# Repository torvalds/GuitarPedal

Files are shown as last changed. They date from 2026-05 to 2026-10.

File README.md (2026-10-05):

## Resurrected random guitar pedal project

This is a resurrected version of my old guitar pedal project: a digital
guitar pedal built around an RP2354A and a TI audio codec, with all the
effects done in software on a core of its own.

It went through a phase with a little OLED screen and a couple of rotary
encoders on it, and that's gone now.  Editing seventeen effects through a
128x128 screen and two knobs was never going to be pleasant, and I'm not
exactly known for my mad UI designing skillz, so the pedal itself is down
to one knob and one stomp switch and the deep editing happens somewhere
that already has a screen: there's a web app that talks to it over USB
MIDI from a browser.

So what's in here:

 - `Hardware` has the kicad files.
 - `Effects` has the seventeen effects, one file each.  They are up here
   rather than inside the firmware because three different things are
   built from them: the firmware, the test bench, and the web app's
   controls.
 - `Audio` has the DSP the effects are built out of - biquads, envelope
   followers, LFOs - and the audio loop itself.  The bench compiles the
   same files, so what gets measured is the pedal's own arithmetic.
 - `Firmware` is the rest of what runs on the pedal: USB, MIDI, scenes,
   the board pin maps.
 - `WebMIDI` is the web app that edits it.
 - `scripts` is what the build runs - the effect generator, the math
   tables, and the checks that refuse a firmware image doing something
   the audio core shouldn't.
 - `Validation` is the test suite.  Some of it runs on your machine and
   some of it wants a pedal plugged in.
 - `Documentation` remains a very optimistic name for a directory.

## Firmware

I've only ever built the firmware on Linux, but it *should* be perfectly
possible to build on MacOS or Windows too if you just figure out the
platform requirements. The project depends on the `pico-sdk` and
`tinyusb` libraries and on `picotool`, and has submodules for all three, so
they get built automatically, but the build tools your platform has to provide.

Regardless of platform, you'll need the basics:
 - git
 - make
 - python3
 - cmake
 - a C and C++ compiler for the machine you build on, because picotool
   and the SDK's PIO assembler are built from source too
 - pkg-config and the libusb-1.0 development files, for picotool
   (`libusb1-devel` on Fedora, `libusb-1.0-0-dev` on Debian)

and a 32-bit arm cross-build environment.  On Linux, that would be
something like
 - arm-none-eabi-binutils-cs
 - arm-none-eabi-gcc-cs
 - arm-none-eabi-gcc-cs-c++ (the SDK sets up C++ as well as C)
 - arm-none-eabi-newlib

On Fedora that whole list is

    dnf install git make python3 cmake gcc-c++ pkgconf-pkg-config \
        libusb1-devel arm-none-eabi-gcc-cs arm-none-eabi-gcc-cs-c++ \
        arm-none-eabi-newlib

The `ble` board also carries the nRF54 radio's firmware, which is a
Zephyr build of its own.  ``make -C nRF54 fetch`` sets that up once: a
python venv with west in it, the Nordic SDK, and Zephyr's ARM toolchain
in `~/zephyr-sdk-*`, about 7.5GB between them.  It also needs ninja
(`ninja-build` on Fedora).

There's more than one board this can be built for, and the build won't
guess.  You say which one this tree is about once, in
`board.local`, and it stays said - it's a file rather than a
cmake cache variable specifically so that blowing away `build/` doesn't
silently change your mind for you.  So:
```
	git clone https://github.com/torvalds/GuitarPedal.git
	cd GuitarPedal
	echo unified > board.local
	make prep
	make
```
`unified` is the current one-board pedal.  The other is `split`, which is
the older modular pair of boards.  If you forget this step the configure
will stop and tell you, which is the intended behaviour - a wrong board
should be an error you fix once, not a working build for hardware you
don't have.

That gets you `build/pedal-unified.uf2` (and `.elf`, and `.bin`).  Every
artifact is named for the board it's for, so there is deliberately no
`pedal.uf2` to grab by mistake.  You can build the other board without
changing what the tree is about - ``make split`` - or both with ``make
all-boards``.

To get the `.uf2` onto the pedal you need it in BOOTSEL mode, and there
are two ways.  If it's running and plugged in, send it MIDI CC 20 with
value 126 and it will reboot into BOOTSEL on its own:
```
	amidi -l                          # find which card the pedal is
	amidi -p hw:5,0 -S "B0 14 7E"     # ...and that 5 is mine, not yours
```
Otherwise, hold the knob in while you plug it in.  The rotary encoder's
switch doubles as BOOTSEL on this board - through a Schottky, so that
QSPI traffic can't fake pulling it low - and that's the route that still
works on a pedal too broken to enumerate.  The older boards had a proper
BOOTSEL button, but it was on the little MCU daughtercard, which is fine
on a bench and useless the moment the thing is screwed into a box.

Either way a USB mass storage device shows up and you copy the file to
it.

The build makes its own picotool, with USB support, so you can also skip
all that and just do ``make flash``, which builds and flashes the board in
`board.local`.
``make flash-split`` does the other one.

### Tools outside the tree

Two tools stay outside the tree, and each has a make target that
sets it up once per machine.  Both say what they are missing, and
running either again is safe.

``make probe-rs`` builds probe-rs, which programs and debugs the nRF54
radio through the pedal, from `~/src/probe-rs` into `~/bin/probe-rs`.
It needs cargo and the libudev development files (`systemd-devel` on
Fedora).

``make build123d`` makes a python venv in `~/.build123d` for the
3D-printed case in `Hardware/Models`, and two commands in `~/bin` that
use it: ``build123d Compact.py`` runs the model, and ``ocp-viewer`` is
the viewer it draws in, at http://localhost:3939.

### Talking to the pedal without root

picotool and probe-rs open the pedal's USB device directly, and without
a udev rule only root can.  This is `/etc/udev/rules.d/99-pedal.rules`:

    ATTR{idVendor}=="2e8a", MODE="0660", GROUP="dialout"
    ATTR{idVendor}=="ffff", ATTR{idProduct}=="0003", MODE="0660", GROUP="dialout"

The first line covers anything with Raspberry Pi's vendor id, which is
how a board in BOOTSEL shows up; the second is the running pedal, whose
CMSIS-DAP interface is what probe-rs uses for the radio.  You have to be
in the `dialout` group, and ``udevadm control --reload`` as root plus a
replug picks the rule up.  USB audio and MIDI need no rule.

The pedal's debug console is `/dev/ttyACM0`, which needs a kernel with
`CONFIG_USB_ACM`.  Every distribution kernel has it; a kernel you
configured yourself may not.

### Testing

`Validation` has the test suite, and it's split by what it needs.

``make check`` needs gcc and numpy (`python3-numpy`), plus node if
you want the web app's tests too; without node those are skipped.  The
bench scripts that talk to a pedal want more: alsa-utils, ffmpeg, scipy
and matplotlib, ngspice for the circuit comparisons, and dbus-python and
PyGObject for Bluetooth MIDI.  On Fedora,

    dnf install python3-numpy nodejs alsa-utils ffmpeg-free psmisc \
        python3-scipy python3-matplotlib ngspice python3-dbus python3-gobject

``make check`` runs the part that needs no hardware at all: the MIDI
packetiser, whether the web app still loads and still draws the right
conclusions, and a sweep that asks every biquad in the pedal where it
actually landed.  ``make check-biquad`` is that last one on its own, and
``make check-effects`` puts signals through the effects themselves.

That last one works because of `Validation/bench`, which builds the
pedal's actual audio core - the same `single_sample()`, the same effect
headers, the same compiler flags - as a program on your machine that
takes float samples on stdin and hands them back on stdout.  It is not a
model of the signal path.  It's the signal path, with the two register
blocks the audio core touches replaced by ordinary memory.

``make check-analysis`` is the other host-only one, and it is what keeps
the per-effect pages under `Documentation/effects` honest: every curve on
those pages is a measurement, and this re-measures and says when one has
stopped being true.  It is separate from ``check`` because it re-runs
every sweep on every page, which is slow.

Then there are the ones that want hardware: ``make check-hw`` with a
signal generator, ``make check-analog`` with a patch cable from the
pedal's output back to its own input, ``make check-bench`` to ask whether
a real board agrees with the host build, ``make check-hwtone`` to sweep
the tone stack the codec runs in its own biquads, and ``make check-loop``
if you have two pedals to patch into each other.

## Hardware

The kicad design files (and some supporting infrastructure, like the 3D
printed insert and the enclosure drill rules) are in the ``Hardware``
subdirectory.

These days it's just the one board.  `Hardware/usb-stomp` has the RP2354A
and the TI TAC5242 codec sitting directly on it, and that's the whole
pedal: no cable, no daughtercards, no connectors in between.

What's on it:

 - a 1/4" input jack and a 1/4" output jack
 - a third 1/4" jack for an expression pedal or a remote stomp switch
 - MIDI in and out, on 3.5mm "Type A" TRS jacks (out through a 5V
   buffer, in through an optocoupler, like MIDI has always wanted)
 - USB-C, and the usual 9V guitar pedal power jack
 - one rotary encoder with a switch under it, and one stomp switch
 - three addressable WS2812B LEDs

The MIDI jacks and the expression jack are the genuinely new things.  The
older boards had nowhere to put them - the expression jack in particular
wants two ADC pins, and those are exactly the pins the old MCU board was
spending on hardware MIDI, so it could not have existed there at all.

Fair warning on that expression jack, though: the hardware is done and
the firmware can read it, but only when the host asks it to over SysEx.
Right now it's a probe for figuring out what people actually plug in
there - expression pedals don't even agree on which contact is the wiper
- and nothing is wired up to *do* anything with the result yet.

### How it used to be

It used to be modular, and those board files are all still here.  There
were two little daughtercards for the "core" hardware - the RP2354
microcontroller (`Hardware/rp2354`) and the TI TAC5112 codec
(`Hardware/codec`) - plus a board for the audio and 9V DC power jacks
(`Hardware/audio-jacks`), and a main board (`Hardware/pedal-board`) for
the pedal IO: i2c connector for the screen, USB-C programming port,
rotary encoders, pin header for stomp switches.  The two halves were
joined by a 12P 0.5mm FFC cable carrying power and data lines (i2c for
control, i2s for audio).

That was mostly so I could try out different form factors.  It let me lay
the two halves out independently, and it was flexible enough to cram a
125B enclosure full of jacks, rotaries and the screen all in one top
area.  There was also a worry about noise isolation, which in the end
never had to be tested.

I used the nice HiRose BM28 series connectors on the modular boards.
They are absolutely tiny, which makes for a great board footprint but
admittedly also makes for a slightly more complicated board due to the
tiny 0.35mm pitch.  I'm not a fan of the traditional pin headers simply
because they make it so hard to do compact form factors.

Those boards are finished and they still work - the firmware builds for
them, and they're still useful for testing.  But what this section used
to say was that if you know what you want, you should just put the codec
directly on the audio jack board and the rp2354 on the IO board.  Which,
yes.  That's the board above.

### Images

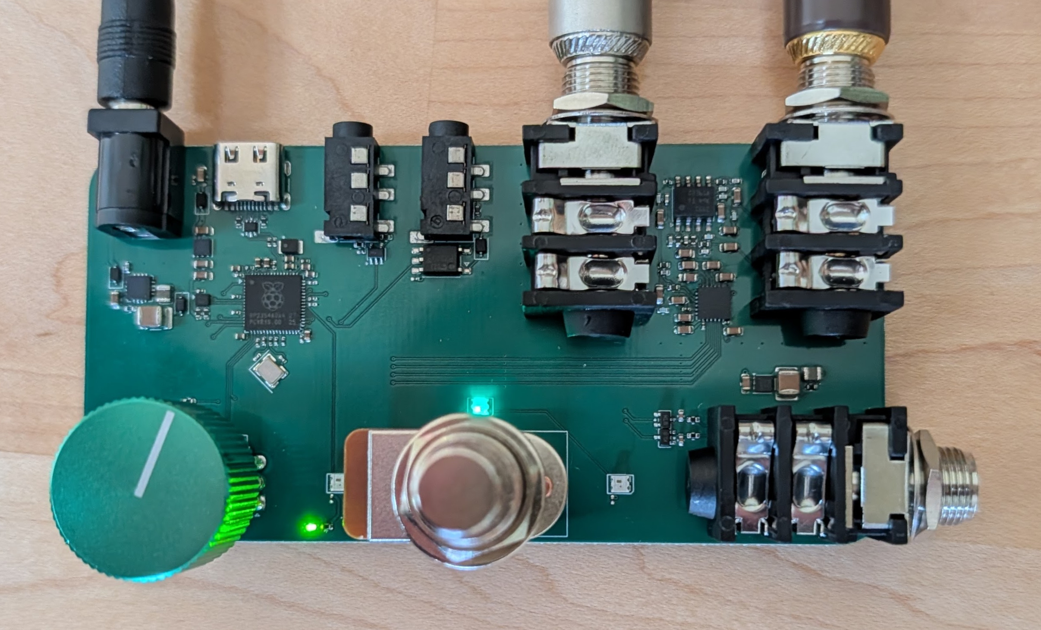
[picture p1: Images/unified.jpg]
The unified board


The bare `usb-stomp` board, powered up.

## Basic UI

There's no screen.  The pedal has one knob, one footswitch and three
LEDs, and everything else happens in a browser.

### On the pedal

Out of the box the footswitch is bypass - tap for in-circuit or not, hold
it for the tuner - and the knob is the master volume, with either kind of
press on it putting the volume back where it started.  That last one
sounds trivial and isn't: it's the way back when you can't see anything.

But none of that is compiled in.  There are five gestures - turn the
knob, tap it, hold it, tap the switch, hold the switch - and what each
one means is a table the pedal looks up and the app writes.  You can
point the knob at any parameter of any effect, or make a single press
take one effect's mix up while it takes another's down.  A pedal with no
screen can't tell you what its knob is for, so that has to be settable
from something that can.

The three LEDs, left to right: something is wrong (red for clipping,
amber for dropped samples), in circuit or bypassed, and the chain is
busy - where "busy" means whatever the effect thinks it means, so the
gate lights it while it's gating and the compressor while it's
compressing.

### In the browser

`WebMIDI` is a static web page that talks to the pedal over USB
MIDI.  There's nothing to install and it runs off a phone.

It also talks to the pedal over Bluetooth MIDI.  On Linux, Chrome only
offers Bluetooth to a page with
`chrome://flags/#enable-experimental-web-platform-features` turned on;
USB needs nothing.

It doesn't know what the effects are.  It asks.  The pedal describes
every effect it has - every pot, the ranges, the units, the hover text -
and the app builds itself out of that, so it can't drift out of step with
the firmware, and adding an effect to the pedal makes it show up in the
app without touching the app.

What you actually do there is *route*.  There are seventeen effects and
none of them are in your signal path until you say so: routing picks
which ones run, and in what order, and the order is yours, because a
boost in front of a delay is a different pedal from a delay in front of a
boost.  Whatever you don't route costs nothing.

Pots are mostly just numbers, except where they aren't - the tone stacks,
the parametric EQ and the cab sim draw their actual frequency response,
so you can see the curve instead of inferring it from three knob
positions.

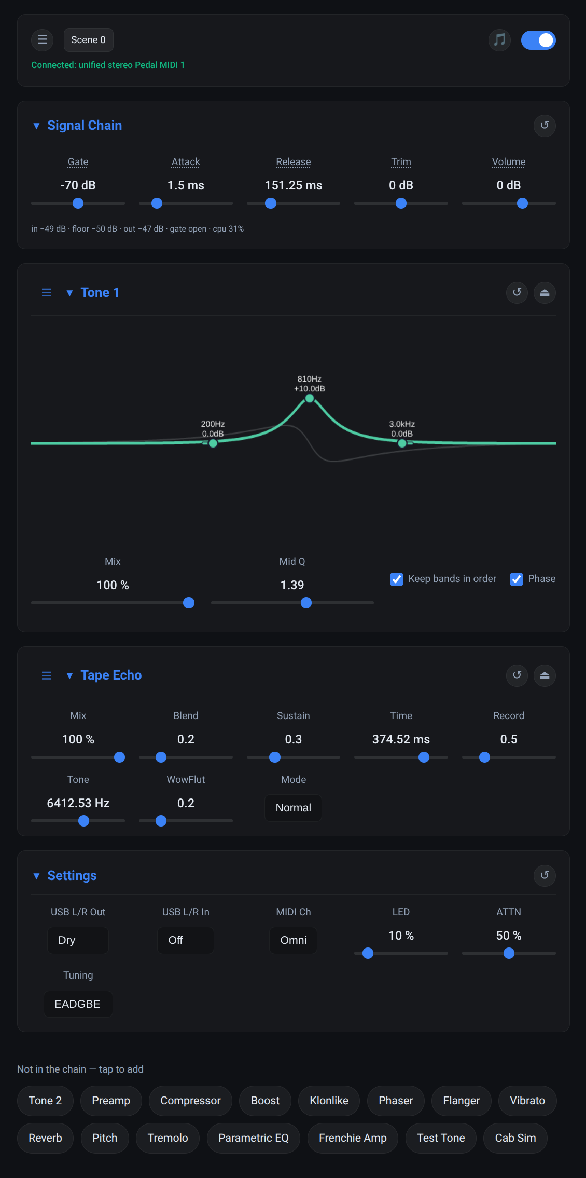
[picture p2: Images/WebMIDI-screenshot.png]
The WebMIDI app with a tone control and a tape echo routed


A tone stack with a 10dB mid bump at 810Hz and a tape echo behind it, and
the fifteen effects that aren't routed sitting at the bottom waiting to
be.  The faint grey line is the phase response.

Eight scenes fit in the pedal's own flash.  A scene is a routing plus
everything set inside it, and a MIDI program change recalls one, which is
half of what those MIDI jacks are for: a cheap footswitch can step
between scenes with no computer in sight.

## Audio effects

Nineteen of them, plus five that are always there and can't be
unrouted: the **Signal Chain** at the front, which is the input trim, the
noise gate and the master volume
([measured](Documentation/effects/signal-chain.md)), and behind them the
**Settings**, which is whether the input jack is carrying one channel or
two, the MIDI channel, LED brightness and what the tuner is tuning to,
the **USB Audio**, which is what crosses the wire in each direction, the
**Bluetooth Audio**, which is where audio from a phone joins, how loud it
is and what goes back, on a board with a radio, and the **Expression Jack**, which is what
is plugged into it and where that thing's travel ends.

They're listed in the order they run in by default.  This is an overview
and not documentation - the app is the reference, because it gets the
ranges, the units and the hover text from the pedal itself rather than
from anything I typed here.

 - **Hum Filter** - removes the hum single coils and noisy power put on
   the guitar, cutting only the hum's own frequencies, so a clean supply
   gets no cuts at all.  Switching it on the first time, or moving the
   target, listens for a few seconds with the sound left on, so you hear
   the hum go: keep the strings quiet while it does.  It runs ahead of
   the noise gate.  It does not reach the high buzz some USB chargers
   add, and a power bank is quieter there anyway.
 - **Tone** - bass, mid and treble, with the corner frequencies
   adjustable and the mid's Q as well.  There are two of them, so one
   can go in front of a distortion and one behind it.
 - **Analog In Tone** and **Analog Out Tone** - the same three bands
   again, running in the codec's own biquads rather than in the chain.
   They cost the audio core nothing, and they keep the two channels
   apart where Tone folds them together.  Routed like anything
   else, but drawn at the ends of the chain because that is where they
   are: analog is the operative word, and they sit outside everything
   USB audio can reach, so a Dry capture has already been through the
   input one and a Wet capture has not yet been through the output one.
   They need a board whose codec answers on i2c.
 - **Preamp** - a two-stage 12AX7 model, class-A biased with the
   asymmetry left in, and a JFET stage after it.
 - **Compressor** - level, ratio, attack, release, and a boost, so it
   can also just be a clean boost when that's what you want.  The
   threshold reaches low enough to work on a quiet pickup with nothing
   in front of it.  [Measured](Documentation/effects/compressor.md).
 - **Auto-Wah** - an envelope filter that sweeps a resonant filter with
   the guitar's pick dynamics, by Jacky Mpoka.  Lowpass mode preserves low-end body while
   sweeping harmonics (Mu-Tron III style); Bandpass mode isolates the
   resonant peak for classic vocal wah (Crybaby style).  Sweeps up for
   funk quack or down for synth sweeps.
 - **Boost**, with distortion.  I like this one.  Others may not.  Set
   the boost stupidly high and the level low, and instead of clipping at
   the level the signal *folds* back down, which gives you harmonics
   that a soft or hard clipper doesn't.
 - **Klonlike** - the obvious model: 18V charge pump for headroom,
   germanium diodes, and the clean/dirty blend that tracks the gain
   knob.  Originally by Bryan Leavelle.
   [Measured](Documentation/effects/klon.md).
 - **Rat Sketch** - a ProCo RAT, from the Aion FX Helios clone.  One
   op-amp with up to 67dB and several decibels an octave of treble
   emphasis inside the feedback, then diodes to ground, then the one
   backwards Filter knob.  Three clipping modes, because the pedal has
   three.  The op-amp saturates inside its own loop and the diodes are
   solved rather than approximated, which is where its second harmonic
   comes from.  [Measured](Documentation/effects/rat.md).
 - **Phaser**, **Flanger** and **Vibrato** - the modulation three.  All
   simple, all a delay line and an LFO wearing different hats.
 - **Tape Echo** - the Echo King from Cleveland Music Co, a model of the
   Maestro Echoplex tape delays, converted from the Hothouse examples.
   All credit to Ricky Sheaves, and blame me for the conversion.
 - **Reverb** - comb filters into allpasses, the traditional way.
   [Measured](Documentation/effects/reverb.md).
 - **Pitch** - not the clever FFT kind.  It walks a delay line faster or
   slower than real time in two phases, crossfaded with a sine so the
   wrap doesn't click.  So it shifts *and* delays, and it feeds back into
   itself, which makes it a short echo that shifts again on every repeat.
   Most natural an octave up, but it does fractions.
 - **Tremolo** - amplitude modulation, several shapes.
 - **Parametric EQ** - five bands, two shelves and three peaks, every one
   of them tunable across the whole range.
 - **Frenchie Amp** - a small amp: triode, tone stack, power amp.
 - **Test Tone** - sine, triangle, saw or noise at a known level and
   frequency.  It replaces the input rather than adding to it, which is
   what lets the pedal measure itself.
 - **Cabinet** - a speaker cone as a moving mass rather than as a filter,
   integrated at the sample rate.  Pick one of five cabinets and it knows
   the rest of itself; the knobs are how hard the amp drives it, how much
   the amp lets its resonance bloom, and where the mic is pointed.

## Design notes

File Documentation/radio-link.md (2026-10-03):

# The link between the pedal and its radio

How the RP2354 and the nRF54L10 on the `minimal` board talk to each other
over a UART: the wire, the packet format, streams and windows, loss, and
restarts. The code is `nRF54/app/src/link.h`, which both sides compile,
`Firmware/nrf54/uart.h` on the pedal and `nRF54/app/src/main.c` on the radio.

## What it is built for

This is not a general-purpose serial protocol, and the design leans on that:

- **Two chips on one board.** The two data lines are copper traces under an
  inch long, with no connector. Bit errors are not expected; the CRC is
  there so that damage is seen rather than decoded, not because the line is
  noisy.
- **Both ends are ours and are updated together.** The pedal programs the
  radio over SWD (Serial Wire Debug), so there is no version negotiation.
- **Both ends poll from a main loop**, expected to come round within about a
  millisecond. The radio sleeps 1 ms when it has nothing to do. The pedal's
  loop also runs USB, and a few things hold it up for longer: a debug-probe
  command can take milliseconds, and saving a scene erases a flash sector
  with interrupts off.
- **The pedal's start is the radio's start.** The pedal holds the radio in
  reset while it brings the link up, so the radio never carries link state
  from before the pedal's.
- **Loss has two expected causes:** one side restarting in the middle of a
  packet, and a receiver falling a whole receive ring behind, which takes a
  stall of seconds. Neither is a reason to resend, and nothing is resent.

What it carries: MIDI to and from up to four Bluetooth connections, commands
from the pedal to the radio and the radio's answers, the radio's debug text,
and a load test.

## The wire

UART1 on the RP2354 (GPIO4 transmit, GPIO5 receive) to UARTE30 on the nRF
(P0.01 receive, P0.00 transmit). 1 Mbit/s, 8 data bits, no parity, one stop
bit, so 100 kB/s each way. The board also wires RTS and CTS, and nothing
uses them: there is no hardware flow control. Both receive pins have a
pull-up, so an undriven line reads as idle rather than as a break.

Both ends move bytes with DMA (direct memory access) and service the
link from the main loop, with no interrupt:

- **Pedal receive:** a 4 kB ring, aligned to its size, that one DMA transfer
  of 0xffffffff bytes writes for ever, wrapping on its address bits. The
  loop reads the channel's write address to see how far it has got.
- **Pedal transmit:** a 1 kB ring, sent one contiguous span per DMA
  transfer.
- **Radio receive:** a 4 kB ring that the DMA refills from the top for ever,
  through the shortcut from the receive END event to the START task. The
  DMA's match filter is set to the zero byte that ends every packet, which
  makes the `AMOUNT` register say how far the DMA has got at each packet
  end; END events count the wraps. The radio only knows the position at a
  packet end, which is all the decoder needs.
- **Radio transmit:** a 1 kB ring, sent one contiguous span per DMA
  transfer.

Each hand-over between the CPU and a DMA channel has a data memory barrier.

## Packets

A packet is a four-byte header, a payload of 0 to 128 bytes, and a CRC-8
over both (polynomial 0x07, initial value 0). That is encoded with COBS
(Consistent Overhead Byte Stuffing), which removes every zero byte, and
ended with a zero. A zero on the wire is therefore always the end of a
packet, and a receiver can start listening at any byte. A packet is at most
135 bytes on the wire: one byte of COBS overhead, since a frame is shorter
than COBS's 254-byte block, and the zero.

The receiver believes nothing until it has seen its first zero. A frame
that does not decode, is longer than a packet can be, or is too short to
hold a header and a CRC is dropped and counted as malformed; one whose CRC
is wrong is dropped and counted separately. Zeros with nothing between them
are ignored.

The header:

| Byte | Field | Meaning |
|---|---|---|
| 0 | kind | what the packet is (below) |
| 1 | peer | which Bluetooth connection it is from or for; 0 is all of them |
| 2 | seq | the packet's number in its stream |
| 3 | flags | `LINK_FIRST` 0x01, `LINK_LAST` 0x02, `LINK_TRUSTED` 0x04 |

The radio assigns peer numbers to its connections. The pedal only ever
echoes one back, so it keeps no table of them.

| Kind | Value | Direction | Carries |
|---|---|---|---|
| `LINK_MIDI` | 0 | both | MIDI bytes, to or from one peer |
| `LINK_CONTROL` | 1 | both | a command for the radio, or its answer |
| `LINK_DEBUG` | 2 | radio to pedal | the radio's `printk` text |
| `LINK_ACK` | 3 | both | how far a stream has got (below) |
| `LINK_HELLO` | 4 | radio to pedal | the radio has started |
| `LINK_ASK` | 5 | both | please acknowledge this stream |
| `LINK_TEST` | 6 | both | load for testing the link |

`LINK_FIRST` marks a payload that starts a message, which is where a
receiver may pick up again after a lost packet. On a MIDI stream that is
any payload starting with a status byte other than F7 (the end of a
SysEx), real-time bytes (F8 to FF) included; on the others, the first
packet of a message. `LINK_LAST` marks
the end of a command or answer. `LINK_TRUSTED` is set by the radio on MIDI
from a peer that bonded with Secure Connections through the pedal's pairing
window, and the pedal refuses SysEx and the reboot-to-bootloader CC from a
peer without it.

## Streams

A stream is a kind and a peer: MIDI for each peer, the control stream, the
debug stream, and the test streams. Acknowledgements, asks and the hello
are not streams. Each side keeps up to 12 streams, made on first use; when
all 12 are in use, the one idle longest - nothing in flight, no
acknowledgement due - is reused, and with none of those a packet on a new
stream is dropped and counted.

A new stream starts at sequence 0 on both sides, and takes nothing until a
packet with `LINK_FIRST`: its first packet may be the rest of a message
from a stream the far side had before, numbered 0 and so in order.

The radio numbers its Bluetooth connections from 1 to 255 and then from 1
again, a new number for each connection and never one still in use, so
streams for peers that have gone are reused as new ones arrive. A radio
that restarts starts again from 1.

For each stream, each side keeps:

| Field | Meaning |
|---|---|
| `tx_next` | the sequence number the next packet out gets |
| `tx_acked` | the first packet out the far side has not consumed |
| `rx_next` | the sequence number expected next |
| `rx_done` | one past the last packet consumed |

Sequence numbers are 8 bits and wrap, and are compared modulo 256. With
two packets in flight at most, that is never ambiguous.

## Windows and acknowledgements

A sender may have at most 2 packets on a stream that the receiver has not
**consumed**: `tx_next - tx_acked < 2`. Consumed means dealt with, not
merely received, so a stream whose receiver cannot use its packets yet
stops its sender on that stream. Every stream starts with its window open
and nothing is granted, because each side has room for every stream's
window at once.

**The windows are per stream, but MIDI for different peers shares a queue
at every stage**, so a shut window on one peer's MIDI stream holds up MIDI
for all of them:

- the pedal collects outgoing MIDI into one packet buffer, and takes no MIDI
  for another peer until that packet has gone;
- the radio's MIDI from the air waits in one queue, and the record at its
  head waits for its own stream's window;
- the radio hands held MIDI to Bluetooth in arrival order, through one set
  of notification buffers shared by every connection.

Commands, answers, debug text and test traffic do not share these, and a
stalled MIDI stream does not hold them up.

An acknowledgement is a `LINK_ACK` packet with the stream's peer in the
peer byte, the stream's kind in the flags byte, `rx_done` as its sequence
number and `rx_next` as a one-byte payload: how far consumed, and how far
received. The sender takes the first as its new `tx_acked` if it lies
between the old one and `tx_next`.

Acknowledgements are sent the next time a side sends anything after
something is consumed, ahead of any other packet, and outside any window.
Each side reads its receive ring before it sends, so that an
acknowledgement says where it really is: after a stall, one sent first
would report the position from before it. Every 100 ms each side repeats
one for every stream it has received anything on, since an acknowledgement
only restates a position and a lost one would otherwise leave a full window
shut for good. The radio
does this only on a pass that found nothing to do, so a radio that is busy
without a break does not repeat them; the pedal does it on every pass.

What consuming means at each end:

- **The pedal consumes everything on arrival:** MIDI goes through a parser
  per peer, answers through a parser of their own, debug text to its debug
  port.
- **The radio holds MIDI** in one of 32 slots until it has been handed to
  Bluetooth, so a Bluetooth client that cannot keep up shuts the MIDI
  windows from the pedal.
- **The radio holds commands** in one of 2 slots until its queue of answers
  to the pedal is empty, so that whatever a command says back has room.

## Loss

A receiver that gets a sequence number other than `rx_next` counts a gap,
takes the new number as its position, and drops packets on that stream,
consuming each, until one with `LINK_FIRST`, and marks that one as
following a gap. The parser behind the stream then starts afresh rather
than take it as the rest of the message that was cut: the pedal drops a
SysEx cut short, and the radio closes it with F7 and sends it on. The
radio also closes an open SysEx when MIDI goes on to another peer, since
the pedal only switches peer between messages.

**Write-off.** A sender that gets an acknowledgement showing the receiver
has received less than was sent, and has sent nothing on the stream for
200 ms (`LINK_LOST_MS`), takes the rest as lost: it moves `tx_acked` so
that only packets received and not yet consumed hold the window. Worked out
from the acknowledgement itself, so the same one again changes nothing.
The receiver sees the next packet as a gap. A receiver that is merely slow
has received everything sent, so its window stays shut until it catches
up.

A side whose own loop was held up does not count that time: a jump of more
than 100 ms in its clock is taken as a stall, and moves the time each
stream last sent forward by as much. What it had queued mostly could not
leave meanwhile, and the acknowledgements waiting in its ring are from
before it did.

**Ask.** A receiver that has heard nothing on a stream has nothing to
acknowledge, so a write-off would never come. So a sender with a packet
unacknowledged, and nothing sent on the stream for 200 ms, sends a
`LINK_ASK`, at most once per 200 ms per stream: the stream's peer, its
kind in the flags byte, sequence 0, and the sender's `tx_acked` as the
payload. A receiver that knows the stream acknowledges it. One that does
not makes it, starting at the asker's `tx_acked`, and acknowledges that:
the packets it never saw are then written off like any others.

## Starting and restarting

**The pedal starts first.** It finds the radio over SWD, holds it in reset,
sets up its UART and DMA, initialises its link state and releases the
reset. Until it has a hello, it sends nothing but acknowledgements.

**The radio starts listening, then says hello.** It starts its receive DMA,
picks a random 32-bit boot id, and sends a zero followed by a `LINK_HELLO`:
peer 0, sequence 0, `LINK_FIRST | LINK_LAST`, with the boot id (four bytes,
low first) and the image's build date and time as payload. It repeats the
hello every 50 ms, on passes that found nothing to do, until it has decoded
any packet from the pedal.

**The pedal answers a new hello by starting over.** A hello with the boot id
it already has is a repeat and is ignored. Any other forgets every stream,
throws away half-parsed MIDI and the MIDI collecting for the next packet,
starts the command it was part way through sending again from its first
packet, sends a zero so that the radio's decoder is in step, and queues
what the radio has to know: the pedal's name and whether the pairing window
is open. Those go behind any commands already queued.

It also stops sending MIDI until the new radio says a Bluetooth client is
subscribed. It keeps its place in its queue of outgoing MIDI, so the rest
of a message it was part way through goes out, without `LINK_FIRST`, and
the new radio drops it. Packets already in its transmit ring go out too,
numbered for the old streams, and are taken as gaps.

**A radio that restarts on its own** comes through the same path with a new
boot id. **A pedal that restarts** resets the radio, so both start again.

## Buffers

| Side | Buffer | Size | Holds |
|---|---|---|---|
| pedal | receive ring | 4 kB | bytes from the radio, written by DMA |
| pedal | transmit ring | 1 kB | packets for the radio |
| pedal | command queue | 512 B | whole commands waiting for the control window |
| pedal | MIDI buffer | 128 B | MIDI collecting into the next packet |
| radio | receive ring | 4 kB | bytes from the pedal, written by DMA |
| radio | transmit ring | 1 kB | packets for the pedal |
| radio | Bluetooth in | 1 kB | packets from the Bluetooth thread, waiting for the loop |
| radio | MIDI from the air | 2 kB | MIDI decoded from Bluetooth, waiting for its window |
| radio | answer queue | 1 kB | answers waiting for the control window |
| radio | debug queue | 1 kB | lines of `printk` waiting for the debug window |
| radio | held MIDI | 32 slots | MIDI from the pedal waiting for Bluetooth |
| radio | held commands | 2 slots | commands waiting for the answer queue to empty |

**The windows keep each receive ring from overrunning.** Twelve streams of
two packets of at most 135 bytes is 3240 bytes, under the 4 kB ring, so
data alone cannot lap it however late the loop is. What still arrives while
a receiver's loop is stopped is acknowledgements and asks, at most a few
hundred bytes a second. Measured with the load test, the radio's loop had to
stop for several seconds before its ring overran.

The radio takes its ring as overrun when more than 3826 bytes are waiting:
the ring less two packets, one for a packet the DMA may be part way through
and one for the time it takes to read the rest. It then counts everything
waiting as lost, skips it, and drops the packet after it as well, since the
decoder was in the middle of one. Since END is a flag rather than a count,
an overrun that crosses two wraps between polls is not counted, and shows
up as gaps and a malformed packet instead. The pedal cannot tell an overrun
at all: it sees the result as gaps, CRC failures and malformed packets.

**When a queue is full, what does not fit is dropped and counted**, not
held back: commands at the pedal, answers and debug lines at the radio,
and MIDI from Bluetooth, which has no way to push back on a sender over the
air. When the radio's MIDI-from-the-air queue lacks room for another
packet's worth, the loop stops taking from Bluetooth in, which then fills
and drops.

## Commands and answers

A command is a whole SysEx message, `F0 7D` and a command byte through F7,
of up to 255 bytes. The pedal queues it whole and sends it on the control
stream in packets of up to 128 bytes, `LINK_FIRST` on the first and
`LINK_LAST` on the last. The radio puts it back together in a 256-byte
buffer and deals with it when it takes the last packet. Answers come back
on the control stream as SysEx messages, which the pedal parses as MIDI from
a trusted source.

Each pass, the radio sends a packet of the control stream before one of
MIDI, so that a notice that a Bluetooth client has subscribed reaches the
pedal ahead of the request that client sends next - as long as the control
window is open. The pedal throws MIDI for the radio away until it has such
a notice, since sending to nobody would cost the link the whole of a big
reply.

## Timing

| Constant | Value | What it is |
|---|---|---|
| `LINK_LOST_MS` | 200 ms | how long a packet may still be on its way |
| acknowledgement repeat | 100 ms | both sides |
| hello repeat | 50 ms | until the radio hears from the pedal |
| radio idle sleep | 1 ms | when a pass found nothing to do |

## Tests

- `Validation/test-link.c` checks the encoder and decoder against known
  packets and every single-byte change and omission - a changed data byte
  is always caught, and a changed COBS code byte or a missing byte gets
  through about 1 time in 3000 - and two ends joined in memory for windows,
  acknowledgements, loss, asks, the hello, stream reuse and sequence wrap.
- `Validation/test-uartrx.c` checks the radio's receive position logic
  against a model of its DMA.
- `Validation/link-stress.py` runs the load test on a pedal: test streams
  both ways, a stream held stuck, debug text, commands timed through the
  radio, a schema over Bluetooth, and optionally the radio's loop stopped
  for a while.

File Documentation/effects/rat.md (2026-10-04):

# Rat Sketch `[RAT]`

A model of the ProCo RAT: one op-amp with a great deal of gain, a diode clamp
on its output, one pole of treble cut and a buffer. There are no transistors in
the signal path, so the whole pedal is a feedback network, two diodes and a
filter — which makes it the distortion here with the least in it, and so the
one where what is left is the argument.

Five controls. **Distortion** and **Filter** and **Volume** are the pedal's
own; **Sweep** and **Mode** are the Helios's additions, described below.

Every figure here is drawn by `Validation/draw-rat.py` from measurements made
by `Validation/analyse-rat.py`, which drives the pedal's own audio core on the
host. The numbers behind each one are kept in the source of this page, in
comments, and `make check-analysis` re-measures them and says if the code has
moved underneath the drawing — so a figure can be as detailed as it needs to be
without the record stopping being text. Comparisons against the hardware and
against ngspice carry their date instead, because neither runs on a laptop.

## Which RAT this is, and why that is the first question

**There is no such thing as "the" RAT**, and this matters more here than it
would for most pedals, because the two things that vary between versions are
the two things this model is mostly about: the op-amp and the diodes.

The reference is an **Aion FX Helios Vintage Distortion** — a documented kit,
built, on the bench, with an OP07CP read off the board. It was chosen because
it was to hand and because a kit comes with a schematic, which is the
difference between measuring a circuit and guessing at one. Every fitted number
in `Effects/rat.h` came off that unit on 2026-09-06.

**The op-amp is a version, not a detail.** The original 1978 RAT used an
LM308N, externally compensated with the 30 pF cap between pins 1 and 8 that
every RAT schematic shows. Pro Co began phasing it out around 1995 and post-1996
RAT 2s carry an OP07, which is internally compensated and needs no such cap.
So the Helios's OP07CP is not a deviation from a RAT — it is what a modern one
has, and this model is faithful to that generation rather than to the first.

That is the version dependency worth taking seriously, because of what the
op-amp turned out to be worth. Giving it a real gain-bandwidth instead of an
ideal one moved this model 7.9 dB at 5 kHz with the Distortion at noon and
22.8 dB at the top of the travel, and at full Distortion it was **audible in a
blind test** — level-matched and shuffled, three takes ordered correctly by
brightness. An LM308 RAT would want that one number refitted and, on the
evidence, very little else: `RAT_GBW` is fitted at 460 kHz for this OP07, and
the whole closed-loop corner falls out of it. What it would *not* need is a
different slew rate, which is the usual folklore about this part — see below.

**The diodes are the other version.** A stock RAT has one silicon pair to
ground and no switch. The Helios adds two common modifications: a **Mode**
switch selecting between three sets of diodes, and a **Sweep** control that
puts up to 1 k in series with the 47 R setting the gain, which takes the treble
emphasis away and the gain with it. Fully down, Sweep is the stock pedal.

So `Mode = Silicon` with `Sweep = 0` is a stock post-1996 RAT, and the other
positions are the mods. If you are comparing this against a different RAT, that
is the setting to compare at.

## The gain network, and the loop around it

The feedback leg is two series RC branches in parallel with the Distortion
rheostat above them, so the gain is frequency-dependent on purpose: 4.7 µF into
560 R lifts everything above 60 Hz, 2.2 µF into 47 R lifts it again above
1.5 kHz, and the Filter knob then takes the result back off. That shape is the
pedal.

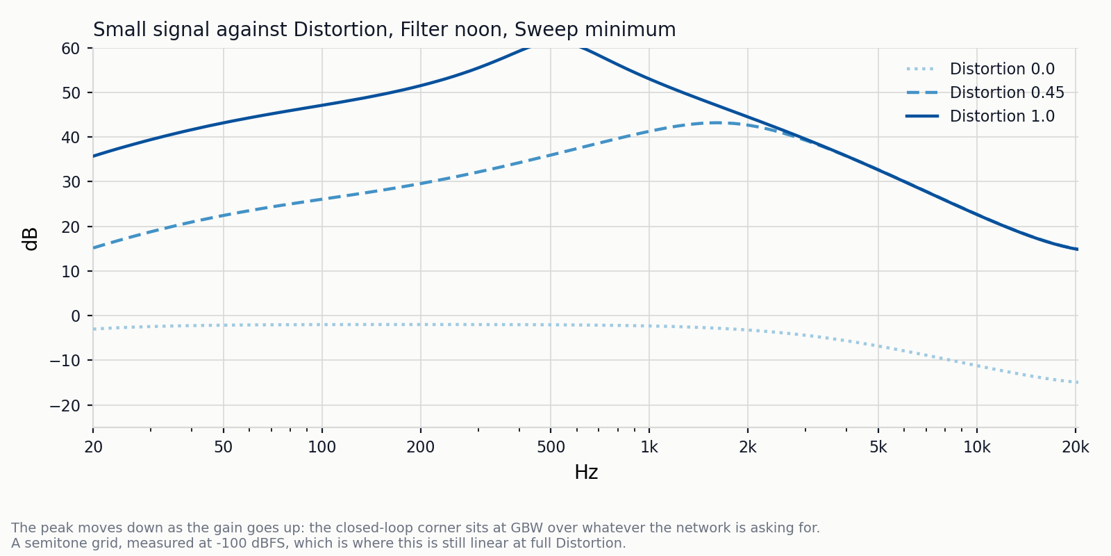
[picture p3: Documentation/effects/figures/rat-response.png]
Small signal against Distortion


<!-- measured
| dB at | 20 | 40 | 80 | 160 | 320 | 640 | 1.3k | 2.6k | 5.1k | 10k | 20k |
|---|---|---|---|---|---|---|---|---|---|---|---|
| Distortion 0.0 | -3.01 | -2.23 | -2.02 | -1.98 | -1.99 | -2.1 | -2.51 | -3.86 | -6.93 | -11.34 | -14.93 |
| Distortion 0.45 | 15.16 | 20.97 | 25.01 | 28.35 | 32.62 | 37.92 | 42.68 | 40.89 | 32.35 | 22.37 | 14.85 |
| Distortion 1.0 | 35.72 | 41.65 | 45.92 | 49.86 | 56.27 | 59.66 | 49.82 | 41.53 | 32.31 | 22.33 | 14.81 |
-->

The peak moving *down* as the gain goes up is the gain-bandwidth: the corner
sits wherever the gain the network is asking for has fallen to GBW/f, so the
knob drags it across most of the audio band — about 2 kHz at noon and down near
560 Hz at the top.

The op-amp's rails are **inside** that loop, which is where the circuit has
them and is not a formality. When it saturates the loop opens, C5 and C6 go on
charging from wherever the node was, and when it comes back out is decided by
that charge and by which rail it had been against. Two unequal rails and a
capacitive feedback leg make a duty cycle, and for a clipped wave the duty
cycle *is* the even harmonics: H2/H1 is `|cos(πd)|`, which is nothing at all at
a half.

| 220 Hz, −12 dBFS, Distortion full | duty | H2 | H3 |
|---|---|---|---|
| the Helios | 46.83 % | −19.6 dB | −10.1 dB |
| `rat-helios.cir` | 45.96 % | −14.9 dB | −10.8 dB |
| **this model** | **45.99 %** | **−17.9 dB** | **−11.2 dB** |
| this model, rails outside the loop | 49.96 % | −55.2 dB | −9.7 dB |

Those are the softest numbers on this page, and it is worth saying by how
much. They come from a scope reading of the op-amp's own output, good to
something like a tenth of a volt, and a tenth of a volt on the upper rail is
worth 0.29 % of duty and 0.65 dB of H2. The remaining disagreement with the
pedal is 0.8 % and 1.7 dB — larger than that, but the same order, so the
right conclusion is that the mechanism is present and correctly signed rather
than that it is calibrated.

That is a table of one number each. The reason to believe it is a picture:

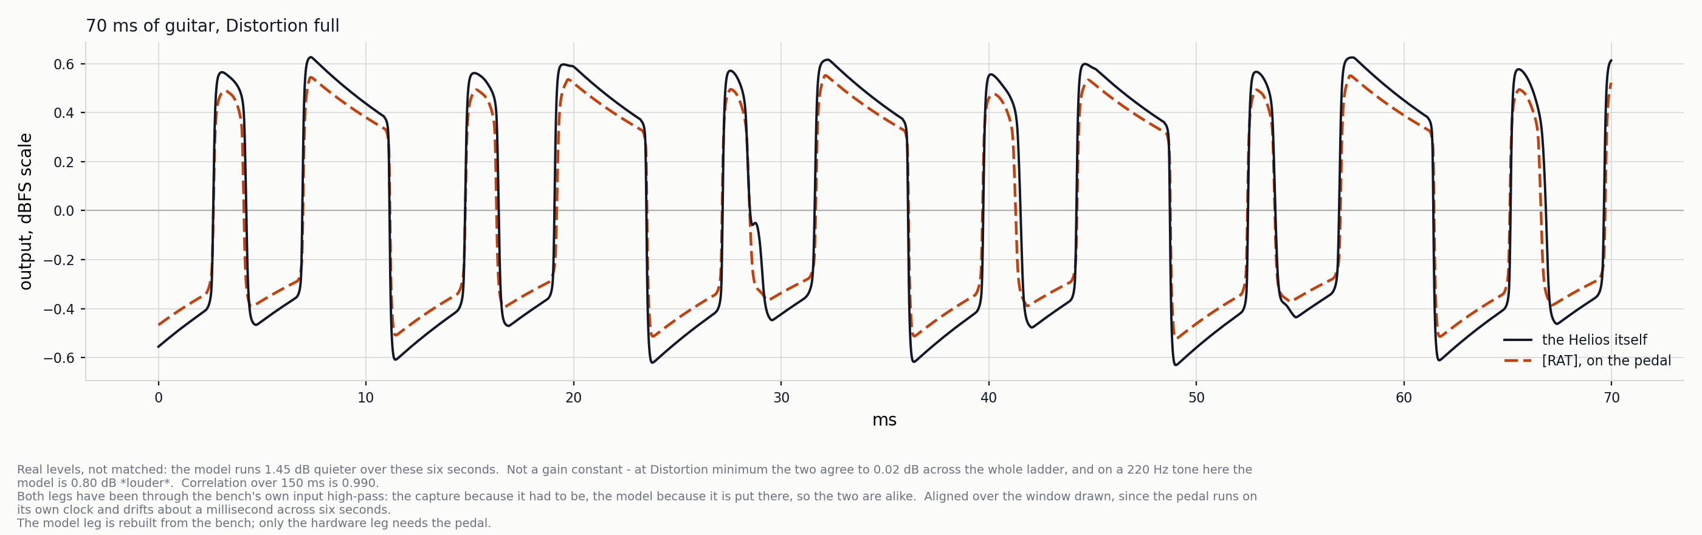
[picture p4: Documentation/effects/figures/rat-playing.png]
70 ms of guitar at Distortion full


Seventy milliseconds of real playing at full Distortion, at real levels rather
than matched. The model's plateaus tilt down at the pedal's rate and its zero
crossings are the pedal's; over 150 ms the two correlate at **0.990**.

It is also **1.45 dB quieter**, and that is drawn rather than normalised away.

It is not a gain constant. At Distortion minimum, where the op-amp is a
follower and the input network, the clamp curve, the follower and the output
network are the whole signal path, the model matches the pedal to **0.02 dB
across the entire level ladder**. Nor is it the source the pedal is driven
from, whose 1 kΩ output impedance against a 690 kΩ input costs 0.021 dB and is
flat across the band.

Driven with the pedal's own recorded stimulus, windowed identically, at full
Distortion:

| 220 Hz burst | rms | crest | plateau droop |
|---|---|---|---|
| the Helios | −8.46 dB | 1.69 dB | **2.17 dB** |
| this model | −7.66 dB | 1.36 dB | **1.27 dB** |

So on a tone the model is 0.8 dB *louder*, and it has **about half the
pedal's droop** — the tilt away from the rail across each clipped plateau,
which is what the waveform above shows. That holds at every drive level tested.
A flatter plateau is less peaky for the same energy, and on broadband material,
where the level never settles and the tilt is being re-established constantly,
it comes out 1.45 dB the other way.

The droop is C7 charging through the diodes, and **most of the apparent gap was
the bench**. A capture reaches the analysis through the pedal's own analog
input, whose coupling capacitor into the codec is a single-pole high-pass at
9.28 Hz.[^rig] Taking it back out — so the numbers are what an ideal capture
would have caught — leaves this:

| plateau droop | 82 Hz | 165 Hz | 220 Hz | 440 Hz |
|---|---|---|---|---|
| the Helios, corrected | 3.80 dB | 1.89 | 1.40 | 0.71 |
| this model | 3.72 | 1.82 | 1.33 | 0.57 |
| `rat-helios.cir` | 2.27 | 1.53 | 1.13 | 0.52 |

So the model is under 0.15 dB short of the pedal across 2.4 octaves rather
than half of it, and the netlist is further short than the model. What remains
is small and unattributed.

The op-amp's rails are not the explanation, and they are the obvious place to
look: they are measured rather than fitted, a scope on pin 6 reading the output
stopping 0.89 V short of the supply and 1.56 V short of ground. That trace
settles the larger question too — at full Distortion the plateaus are flat, top
and bottom — so whatever tilts this pedal's clipped half cycles, the amplifier
does not.

The rest was excluded the same way, all by measurement: C7's value (4.1 µF in
circuit), R5's (1 kΩ), the diode saturation current (×30 moves the droop
0.17 dB), its ideality (1.86 to 3.5, another 0.17), C7 leakage (300 µA moves
it 0.01 dB) and the Filter branch (0.6 % of the current).

The level is a separate question and the correction does not touch it: +0.8 dB
on a tone and −1.45 dB on a chord, pole in or out.

[^rig]: 9.28 Hz is measured, not assumed — `Validation/test-loop.py` fits it and
    it has held across three board generations, predicted before the third was
    built. It is 0.008 dB at 220 Hz, so no level, ladder or harmonic
    measurement here has ever needed to care about it. In the time domain it is
    not small: τ is 17 ms, so a value held across a 2.27 ms half cycle decays
    12 % and a clipped flat top tilts 1.1 dB. `loop.uncolour()` takes it back
    out, which is what makes a number describe the pedal rather than the pedal
    and this bench together. The real fix is hardware and is planned rather
    than done: DC-coupling the codec inputs removes the pole, and the
    next-generation board wants that anyway for its headphone amplifier — with
    a 1 MΩ input and only a DC blocking capacitor in front of it, what is left
    is too small to correct for.

The netlist is not drawn here, and that is worth saying rather than passing
over: on this material it correlates with the pedal at 0.574, so the model is
the better description of the Helios than `rat-helios.cir` is. The deck is
right about tones — it is what most of the constants on this page were fitted
against — and wrong about a chord, by an amount no tone measurement would have
found.  That is a defect in the netlist rather than in this model, and it
is not chased here.

## A diode has no clipping level

The clamp is not a limit. A diode's drop is the logarithm of its current, so
the node keeps climbing about a hundred millivolts a decade for as long as the
drive keeps rising. At Distortion minimum the op-amp is a follower and the
input drives the diodes through R5 alone, which is the one place that curve is
visible from outside the pedal:

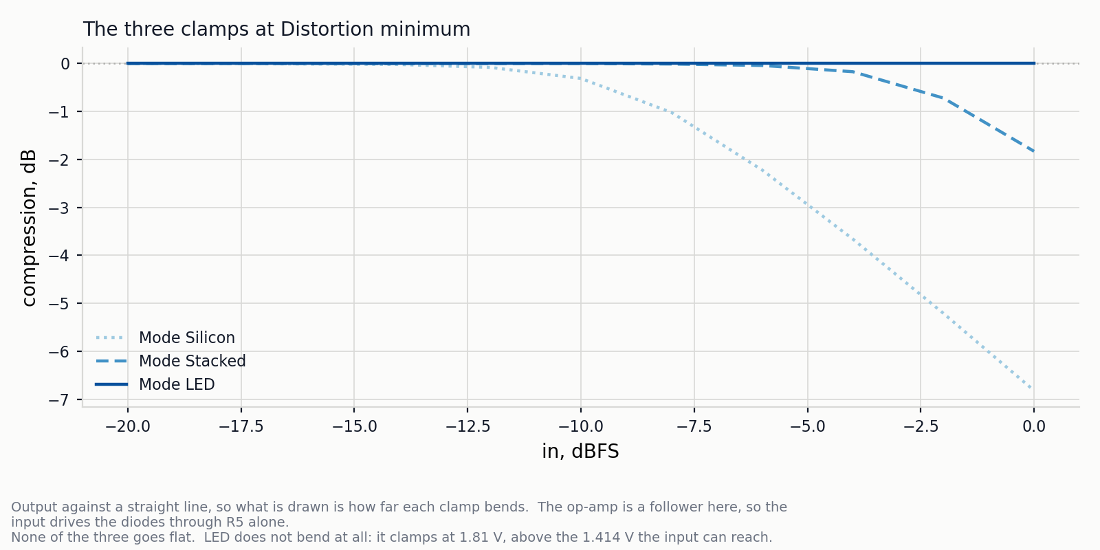
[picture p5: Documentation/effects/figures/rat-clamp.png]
The three clamps


Drawn as compression — output against a straight line — because what matters is
how far each bends and that none of them stops bending. Raw, all three are a
diagonal with the interesting part squeezed into the last few decibels.

<!-- measured
| dB at in dBFS | -20 | -18 | -16 | -14 | -12 | -10 | -8 | -6 | -4 | -2 | 0 |
|---|---|---|---|---|---|---|---|---|---|---|---|
| Mode Silicon | 0.0 | -0.0 | -0.01 | -0.02 | -0.08 | -0.31 | -1.02 | -2.22 | -3.66 | -5.21 | -6.82 |
| Mode Stacked | 0.0 | -0.0 | -0.0 | -0.0 | -0.0 | -0.0 | -0.01 | -0.04 | -0.17 | -0.72 | -1.83 |
| Mode LED | 0.0 | 0.0 | -0.0 | 0.0 | 0.0 | -0.0 | 0.0 | 0.0 | 0.0 | -0.0 | -0.0 |
-->

None of the three goes flat, and that is the point rather than a detail of the
drawing. Measured on the pedal at 1 dB steps, the last decibel before full
scale still moves the output **0.21 dB**. A curve that goes flat above a knee
cannot do that, and what it costs is visible: the flat top of a clipped note
stops tilting as the note decays.

That figure is also the one setting where the **Mode** switch looks pointless,
which it is not. Put some gain in front and the three positions separate by
7.6 dB of output ceiling:

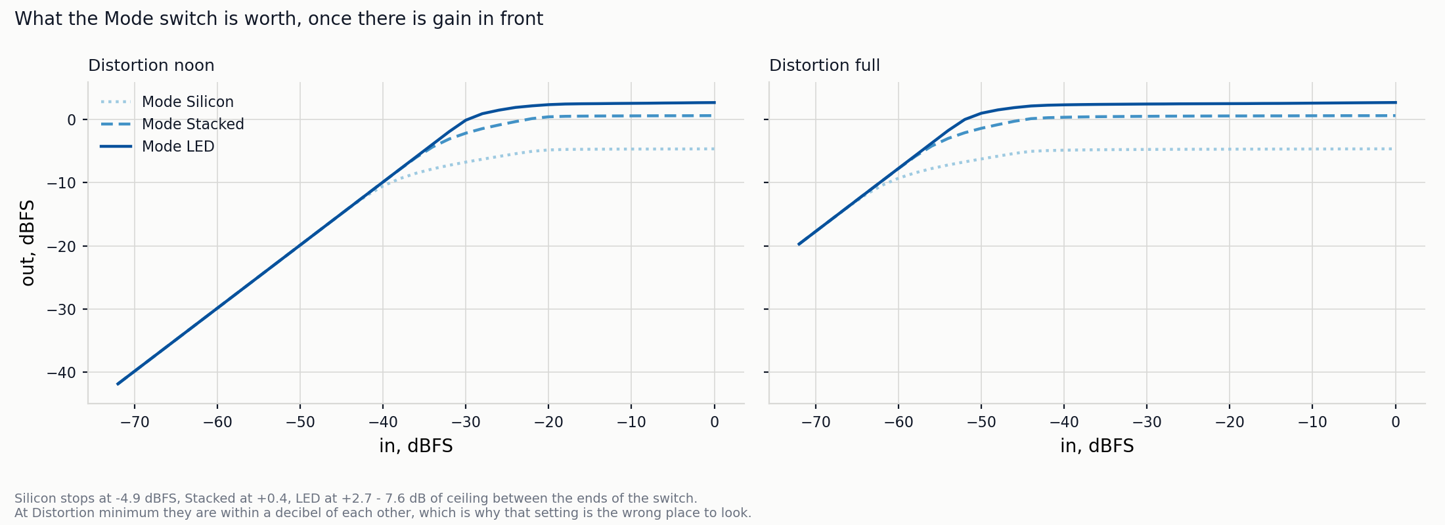
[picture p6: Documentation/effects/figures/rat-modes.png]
What the Mode switch is worth


<!-- measured
| dBFS out at in dBFS | -72 | -60 | -48 | -36 | -24 | -12 | 0 |
|---|---|---|---|---|---|---|---|
| Mode Silicon at noon | -41.89 | -29.89 | -17.89 | -8.49 | -5.4 | -4.67 | -4.63 |
| Mode Stacked at noon | -41.89 | -29.89 | -17.89 | -5.99 | -0.31 | 0.59 | 0.64 |
| Mode LED at noon | -41.89 | -29.89 | -17.89 | -5.89 | 1.94 | 2.57 | 2.71 |
| Mode Silicon at full | -19.72 | -9.28 | -5.79 | -4.77 | -4.69 | -4.66 | -4.63 |
| Mode Stacked at full | -19.72 | -7.75 | -0.79 | 0.47 | 0.57 | 0.61 | 0.64 |
| Mode LED at full | -19.72 | -7.72 | 1.55 | 2.42 | 2.52 | 2.6 | 2.72 |
-->

The three positions are not three heights of one mechanism. LED clamps at
1.81 V, which is *above* the 1.414 V this pedal's input can reach, so at unity
gain the LEDs never conduct at all — the green line is the linear chain and
nothing else. Silicon at 0.61 V sits far below the op-amp's rails and dominates
completely. Stacked is between. The two red LEDs are across the node in all
three positions; they contribute nothing to the other two, four decades down
where the silicon passes milliamps.

Magnified onto a single clipped edge, at Distortion noon where the clamp and
the rails are both in play:

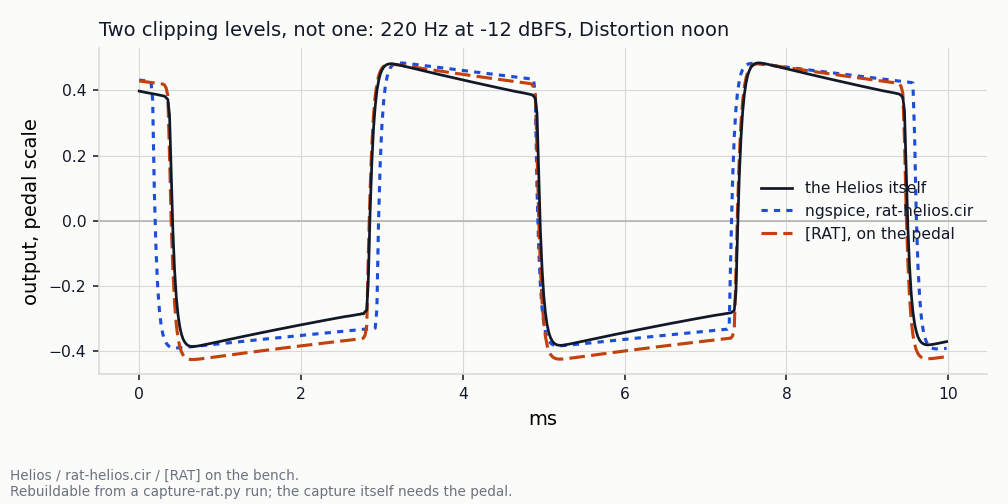
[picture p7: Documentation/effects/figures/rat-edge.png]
One clipped edge, three ways


The diode law is fitted to the pedal, not to the netlist:

| | this pedal | `rat-helios.cir` |
|---|---|---|
| N | 1.859 | 1.752 |
| Is | 2.03 nA | fitted |
| Rs | **31 Ω** | absent |

Where the 31 Ω lives is not settled. A 1N914's own bulk resistance is
single-digit ohms, so most of it is the Mode switch's contacts or the JFET
follower sagging at large signal, and those look identical from outside. Only
the diode's own share should double in the Stacked position, so it is not
doubled — a choice recorded rather than a measurement.

## The Filter runs backwards

One pole, and turning it up makes it darker. It is the only tone control and it
is after everything, so it removes treble the gain network has already made
rather than shaping what the diodes see.

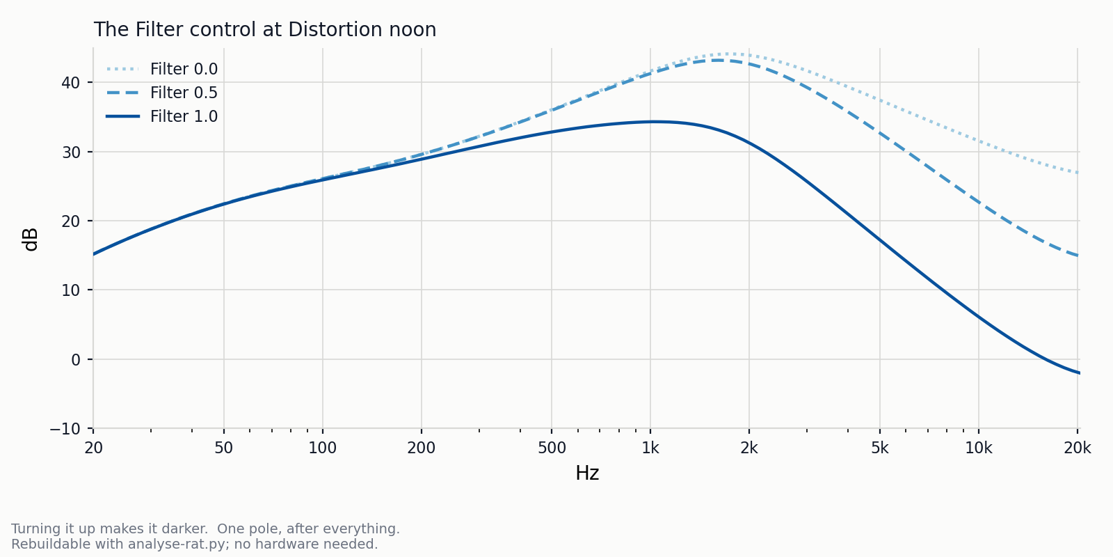
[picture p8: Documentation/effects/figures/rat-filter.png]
The Filter control


<!-- measured
| dB at | 20 | 40 | 80 | 160 | 320 | 640 | 1.3k | 2.6k | 5.1k | 10k | 20k |
|---|---|---|---|---|---|---|---|---|---|---|---|
| Filter 0.0 | 15.16 | 20.97 | 25.01 | 28.36 | 32.66 | 38.07 | 43.25 | 42.78 | 37.23 | 31.36 | 26.89 |
| Filter 0.5 | 15.16 | 20.97 | 25.01 | 28.35 | 32.62 | 37.92 | 42.68 | 40.89 | 32.35 | 22.37 | 14.85 |
| Filter 1.0 | 15.15 | 20.94 | 24.89 | 27.89 | 31.03 | 33.58 | 34.09 | 28.07 | 16.83 | 5.75 | -2.07 |
-->

## What it gets wrong

**The asymmetry turns on more abruptly than the pedal's.** Across the
Distortion travel both this model and the netlist switch their asymmetry on
between 0.25 and 0.30, where the pedal is already part way into it at 0.25:

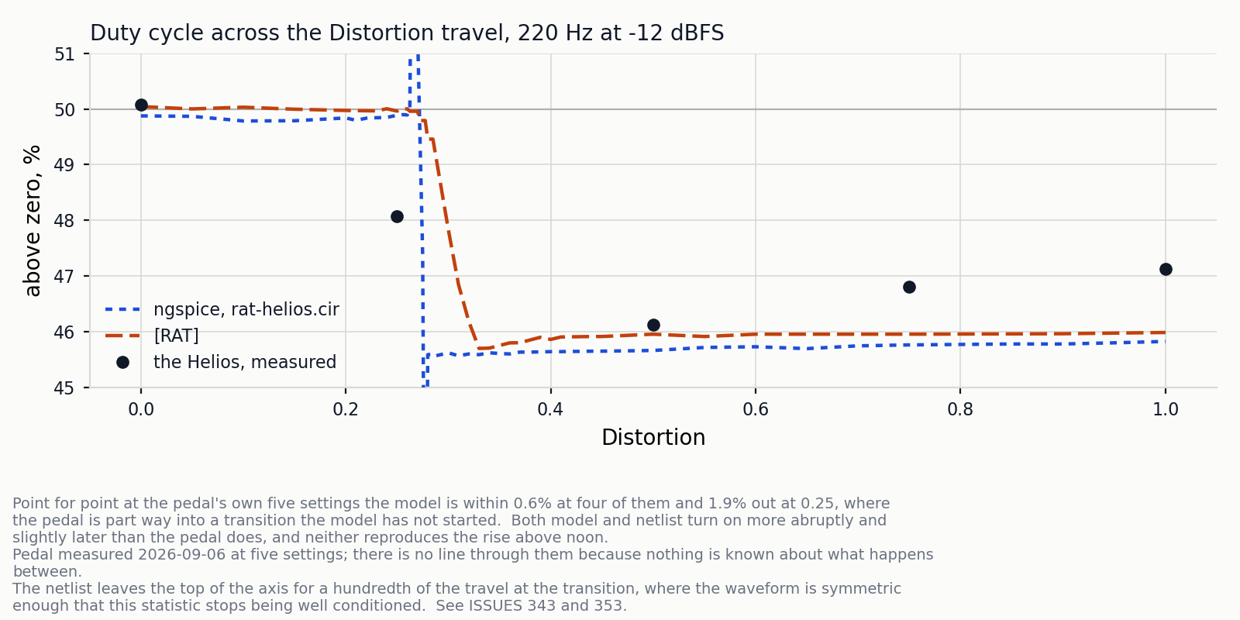
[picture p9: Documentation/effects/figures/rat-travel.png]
Duty cycle across the Distortion travel


<!-- measured
| % at Distortion | 0.0 | 0.1 | 0.2 | 0.3 | 0.4 | 0.5 | 0.6 | 0.7 | 0.8 | 0.9 | 1.0 |
|---|---|---|---|---|---|---|---|---|---|---|---|
| duty above zero % | 50.04 | 50.03 | 49.97 | 47.84 | 45.86 | 45.95 | 45.95 | 45.95 | 45.96 | 45.96 | 45.99 |
| H2 | -106.9 | -121.2 | -153.3 | -22.0 | -17.7 | -17.8 | -17.9 | -17.9 | -17.9 | -17.9 | -17.9 |
| H3 | -52.0 | -38.9 | -14.9 | -12.1 | -11.2 | -11.2 | -11.2 | -11.2 | -11.2 | -11.2 | -11.2 |
-->

Point for point at the pedal's own five settings the model is within 0.6 % at
four of them and 1.9 % out at 0.25 — rms 0.91 %, against the netlist's 1.12 %.
So this is the shape of the onset rather than a different curve, and the first
version of this figure said otherwise only because it joined the pedal's five
points with straight lines. There is no line through them now: the pedal was
measured at five settings and nothing is known about what it does between.

Neither description reproduces the small rise from noon to full either, which
is 0.6 %, which is about twice what the same measurement repeats to.

**The follower is one number.** `RAT_KOUT` is a flat −1.95 dB, which is a good
approximation of a stage the schematic cannot settle anyway: it draws a 2N5457
and the kit shipped a PN4303, which bias half a volt apart. Against the deck
with nothing else in the path there is a bow of about +0.4 dB through the
midband crossing to −0.78 dB at 16 kHz, and the follower is where to look
first.

**Everything runs at the sample rate**, so the diode clamp aliases. What that
costs on this effect has not been measured.

**And the slew rate is deliberately absent**, which is worth saying because it
is the first thing anybody reaches for. The OP07's 0.3 V/µs is never reached
here: the closed-loop corner is 2 kHz at noon and 560 Hz at full, so a
rail-to-rail swing through it has a maximum slope of 0.07 and 0.02 V/µs. The
bandwidth limit wins by four to fifteen times everywhere, and a full swing at
0.3 V/µs would take 0.9 of a sample period in any case — sub-sample, so a
per-sample delta clamp would model the sample rate rather than the part.

## What it costs

A diode equation solved per sample is a logarithm and four Newton steps, and
measured on the pedal that was **59 % of everything this effect costs**. The
clipping node cannot move while a note is playing, so `scripts/rat_clamp.py`
solves it at every point of a table at build time and the audio core does an
index and a lerp instead. What the finished effect costs is **9 % more than the
crude sketch that preceded it** — the one with a fixed clipping level, a
symmetric clamp and the rails outside the loop — so everything on this page
arrived for very little.

The table is 1548 bytes of RAM, sized so its interpolation error stays under
the 0.62 mV rms residual of the fit it is built from. Ratios rather than
percentages of the sample period, because a percentage depends on the clock the
firmware happens to be built for and this one does not.

## Reproducing this

```
cd Validation && make bench && ./analyse-rat.py      # every chart above
./compare-spice.py rat                               # against rat-helios.cir
./draw-rat.py                                        # the figures themselves
```

`make check-analysis` compares this page against a fresh run and warns when a
number has moved. The hardware comparisons need the Helios on the bench and a
capture from `capture-rat.py`; the figures need a guitar recording that is not
ours to commit, and `draw-rat.py` says so on their faces.

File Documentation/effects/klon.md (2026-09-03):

# Klonlike `[KLON]`

A model of the Klon Centaur, originally written by Bryan Leavelle. Three
controls — **Gain**, **Treble**, **Output** — all `LINEAR(0 1)`.

The circuit it models: a charge pump for 18V of headroom, an input buffer, an
op-amp driving a germanium diode pair to ground, and a clean/dirty blend that
tracks the gain knob rather than being a mix control of its own. The treble
control is a shelf with a presence peak below it.

**The signature is the blend.** On a real Centaur the clean and clipped paths
are summed by a dual-gang gain pot, so turning up the gain does not just add
distortion, it *removes the clean signal*. At low gain you get a clean sound
with an edge on it; at maximum there is no clean path left. That is the whole
character of the pedal and the model does reproduce it.

All numbers here are measured, not calculated, by `Validation/analyse-klon.py`
driving the pedal's own audio core on the host. `make check-analysis` re-runs
them and says if the code has moved underneath this page.

## What the Gain knob does

Output and distortion against Gain, with a −18 dBFS tone in — about what a
guitar actually produces.

```mermaid
%%{init: {'themeVariables': {'xyChart': {'plotColorPalette': '#0072b2'}}}}%%
xychart-beta
    title "THD against Gain, -18 dBFS in"
    x-axis "Gain, %" [0, 10, 20, 30, 40, 50, 60, 70, 80, 90, 100]
    y-axis "THD, dB" -145 --> 0
    line [-138.5, -80.4, -57.7, -42.5, -32.3, -25.1, -19.9, -14.9, -10.9, -9.2, -8.3]
```

```mermaid
%%{init: {'themeVariables': {'xyChart': {'plotColorPalette': '#0072b2'}}}}%%
xychart-beta
    title "Output against Gain, -18 dBFS in"
    x-axis "Gain, %" [0, 10, 20, 30, 40, 50, 60, 70, 80, 90, 100]
    y-axis "Gain, dB" -5 --> 25
    line [-0.81, -0.6, 1.55, 5.65, 10.19, 14.18, 17.34, 19.46, 19.87, 19.99, 20.04]
```

Two things worth reading off those. **The output curve flattens after about
0.7** — the last third of the knob is almost all distortion and almost no
level, which is what you want from a drive pedal and is a fair reproduction of
the real thing. And **at Gain 0 the effect is essentially a wire**, −0.81 dB
and −138.5 dB THD, so it can be left in the chain switched down.

## The Treble control

Small-signal response at Gain 0.5, with Treble at each end.

```mermaid
%%{init: {'themeVariables': {'xyChart': {'plotColorPalette': '#0072b2, #d55e00'}}}}%%
xychart-beta
    title "Treble 0.0 blue, Treble 1.0 orange, at Gain 0.5"
    x-axis "Hz" [20, 40, 80, 160, 320, 640, "1.3k", "2.6k", "5.1k", "10k", "20k"]
    y-axis "dB" 0 --> 24
    line [10.13, 13.36, 14.74, 15.16, 15.27, 15.22, 14.35, 10.83, 8.87, 7.55, 5.92]
    line [10.13, 13.37, 14.75, 15.19, 15.39, 15.87, 19.6, 21.78, 20.93, 19.59, 17.93]
```

The two ends differ by 11 to 12 dB above 2 kHz and are within 0.15 dB of each
other below 640 Hz, so it is a treble control and not a tilt. The peak at
2 kHz on the bright setting is the 1.7 kHz presence filter riding on the
shelf, which is why it sits above its own centre frequency. The model doubles
the peak's boost relative to the shelf, which the comment in the source notes
was true of the original code too.

## What it gets wrong

Two things, both filed.

**It cannot produce even harmonics at all.** The clipper is `tanhf()`, which
is odd, and nothing in the signal path breaks the symmetry — measured even
content is `0.00 %` at every gain setting, from 0.0 to 1.0. The comment in the
source says germanium hard clipping "gives even harmonic content from the soft
knee", and a real mismatched diode pair does. This one does not, and even-order
content is most of what people mean when they call a drive "warm" rather than
"fuzzy".

**The clean path skips every input filter.** `klon_step()` builds a
conditioned signal — DC blocker, 30 Hz coupling capacitor, 15 kHz input
bandwidth — and then blends the *raw* input with the clipped one, not the
conditioned input. So all three filters exist only in the dirty half, and the
gain knob moves the frequency response as a side effect:

```mermaid
%%{init: {'themeVariables': {'xyChart': {'plotColorPalette': '#0072b2, #d55e00'}}}}%%
xychart-beta
    title "Gain 0.0 blue, Gain 1.0 orange, Treble 0.5, normalised"
    x-axis "Hz" [20, 40, 80, 160, 320, 640, "1.3k", "2.6k", "5.1k", "10k", "20k"]
    y-axis "dB, relative to 320 Hz" -6 --> 4
    line [-0.08, -0.06, -0.05, -0.04, 0.0, 0.18, 1.65, 1.09, 0.11, -0.03, -0.05]
    line [-5.09, -1.91, -0.57, -0.14, 0.0, 0.21, 1.65, 0.96, -0.46, -1.86, -3.68]
```

At Gain 0 the response is flat to 20 Hz and flat to 20 kHz — no coupling
capacitor and no bandwidth limit anywhere. At Gain 1.0 the same filters are
fully present, 5.1 dB down at 20 Hz and 3.7 dB down at 20 kHz. On the real
Centaur both halves come off the same input buffer through the same coupling
cap, so the split happens after the input stage, not before it. One character
in the source — blending `pre` instead of `in` — but it changes the voicing at
every setting below maximum.

## What it gets right

- **The blend really is a gain-tracked crossfade**, not a mix knob, and the
  clean path really does ground out as the gain comes up.
- **The knee is soft.** The level sweep at Gain 0.7 shows THD rising smoothly
  from −96 dB at −60 dBFS to −7 dB at 0 dBFS with no discontinuity, and the
  waveform corner sharpness stays near 1.5 until the signal is loud enough to
  fold, which is germanium-like rather than silicon-like.
- **It stays clean when it is told to.** −138.5 dB THD at Gain 0.

One caveat for the top of the knob: aliasing rises from −123 dB at low gain to
**−50.7 dB at Gain 1.0**, because the clipper generates harmonics well above
Nyquist and there is no oversampling. That is audible as a hard edge rather
than as recognisable tones, and it is worst exactly where the input bandwidth
limit is bypassed by the issue above.

## Reproducing this

```
cd Validation
make bench          # a stale bench measures a pedal you no longer have
./analyse-klon.py
```

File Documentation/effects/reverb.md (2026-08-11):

# Reverb `[REVERB]`

Freeverb — Schroeder-Moorer, by Jezar at Dreampoint, public domain. Eight
parallel feedback comb filters fed by the input, summed into four series
allpasses. Two controls: **Room** (0.70..0.98) is the feedback gain shared by
all eight combs, and **Damp** (0.1..0.5) is a one-pole lowpass inside each
comb's feedback loop. Defaults are 0.88 and 0.25, and it returns wet only, at
an 18% default mix.

Each comb's read pointer is swept ±6 samples by one of four slow LFOs, which is
the Lexicon trick for stopping a long tail ringing on a fixed set of
frequencies.

## Room is the decay time, and it is not linear in the knob

T60 is measured the standard way: Schroeder backward integration of the tail
after a gated noise burst, fitted from −5 dB to −25 dB and tripled.

```mermaid
%%{init: {'themeVariables': {'xyChart': {'plotColorPalette': '#0072b2'}}}}%%
xychart-beta
    title "Decay time against the Room control"
    x-axis "Room, comb feedback gain" [0.7, 0.76, 0.81, 0.87, 0.92, 0.98]
    y-axis "T60, seconds" 0 --> 10
    line [0.52, 0.65, 0.89, 1.32, 2.4, 9.08]
```

Half a second to nine seconds, so the whole travel does something — but look at
the shape. The knob is linear in the feedback gain, and decay time goes as
roughly 1/(1−g), so it runs away at the top: **the first 80% of the pot covers
0.52 to 2.4 seconds, and the last 20% covers 2.4 to 9.1.**

That is not merely a steep curve, it is a curve whose steep end is where the
interesting settings live. It is the same shape of defect the compressor's Ratio
had — a control whose useful range is piled at one end of its travel — and it is
worth knowing about before reaching for the knob, because the top two
centimetres are where a room turns into a cathedral.

The default 0.88 gives 1.32 s, which is a plausible medium room and sits at
mid-travel where the control is still well behaved.

## Damp tilts the decay; Room scales it

Damp is a lowpass in the feedback path, so it does not shorten the tail evenly —
each pass round the loop takes a little more top off, and the highs run out
first. That is what a real room does, because air and soft furnishings both
absorb treble faster than bass.

```mermaid
%%{init: {'themeVariables': {'xyChart': {'plotColorPalette': '#0072b2, #d55e00, #009e73'}}}}%%
xychart-beta
    title "T60 by octave. Damp 0.10 blue, 0.30 orange, 0.50 green"
    x-axis "Hz" [125, 250, 500, 1000, 2000, 4000]
    y-axis "T60, seconds" 0 --> 2
    line [1.7, 1.85, 1.77, 1.69, 1.47, 1.13]
    line [1.7, 1.84, 1.71, 1.6, 1.24, 0.78]
    line [1.69, 1.81, 1.59, 1.47, 0.91, 0.48]
```

The three lines are on top of each other at 125 Hz — 1.70, 1.70, 1.69 — and a
factor of 2.4 apart at 4 kHz. Damp does nothing whatever to the bottom of the
spectrum, by construction, and that is the correct behaviour rather than a
limitation.

Room, by contrast, scales the whole thing:

```mermaid
%%{init: {'themeVariables': {'xyChart': {'plotColorPalette': '#0072b2, #d55e00, #009e73'}}}}%%
xychart-beta
    title "T60 by octave. Room 0.70 blue, 0.87 orange, 0.98 green"
    x-axis "Hz" [125, 250, 500, 1000, 2000, 4000]
    y-axis "T60, seconds" 0 --> 11
    line [0.95, 0.59, 0.59, 0.58, 0.56, 0.46]
    line [1.58, 1.68, 1.5, 1.51, 1.21, 0.82]
    line [10.82, 10.12, 9.6, 7.68, 4.62, 1.79]
```

Note that the green line still slopes — at Room 0.98 the tail is 10.8 s at
125 Hz and 1.8 s at 4 kHz, a six-to-one tilt, because the damping compounds over
far more trips round the loop. So the two controls are not independent: a longer
room is also a darker one, at the same Damp setting.

## The modulation, and why the tail wanders

Eight fixed combs ring on a fixed set of frequencies, and a note that lands on
one of them sits there and hums. Sweeping each read pointer ±6 samples walks
those resonances instead — ±0.5% on a comb of 1215 samples — so nothing has a
fixed frequency to sit on.

You can see it directly. A steady 440 Hz tone, 100% wet, half-second windows —
the first 5.5 seconds of a 85-second capture:

```mermaid
%%{init: {'themeVariables': {'xyChart': {'plotColorPalette': '#0072b2'}}}}%%
xychart-beta
    title "Wet level of a steady tone, wandering as the combs detune"
    x-axis "seconds" [0.0, 0.5, 1.0, 1.5, 2.0, 2.5, 3.0, 3.5, 4.0, 4.5, 5.0]
    y-axis "dBFS" -28 --> -24
    line [-25.08, -26.57, -25.92, -24.96, -26.08, -25.12, -25.73, -26.11, -26.86, -25.24, -25.96]
```

The input never changes and the output wanders. That wander is the effect
working: it is the comb peaks sliding under a fixed tone.

**How far it wanders depends entirely on how long you watch**, and that is worth
stating because the first attempt at this got it wrong. The excerpt above covers
1.9 dB. Over the full 85 seconds it is **5.9 dB peak to peak**, with a standard
deviation of 1.08 dB and a p5..p95 spread of 3.4 dB. The slowest of the four
LFOs has a period of 4.8 seconds and they are spaced so as not to share one, so
a short capture does not sample the range — it samples whichever corner of it
the recording happened to start in. An eight-second capture reported 2.3 dB,
which is less than half the truth.

The chart is an excerpt rather than the whole run for a reason that is about
drawing rather than about reverb: eleven points is what the axis can label, and
eleven points spread over 85 seconds would put the window well above every rate
being looked at and average the wobble into a flat line.

The four LFOs run at 0.21, 0.31, 0.46 and 0.67 Hz — spaced about 3:2 so they do
not beat into a common period — and they are phase accumulators, which matters
more than it sounds. They used to be quadrature phasors rotated by a fixed
step, and nothing renormalised them: three of the four spiralled outwards and
one decayed to a tenth of its amplitude in ten minutes, so the reverb slowly
became the unmodulated version of itself and, left on overnight, walked its read
pointer out of the comb buffer entirely.

**The modulated read is interpolated.** Truncating it to a whole sample makes
the pointer jump, and a jump is a step discontinuity sprayed into the tail
continuously by eight combs at four rates. Measured by band-limiting the input
to 1 kHz and looking above 4 kHz, where a reverb that is time-invariant apart
from a sub-hertz modulation cannot legitimately put anything:

```
  input above 4 kHz    -78.3 dB of its total
  output above 4 kHz   -82.2 dB of its total
```

The output has *less* up there than the input did. It manufactures nothing.
Before the read was interpolated it manufactured 34.5 dB above what went in.

## What it costs

This is the expensive effect, and unlike everything else on this page the number
comes off the pedal rather than the bench — `Validation/measure-load.py`, which
reads the load meter over MIDI telemetry. Steps out of 127 of the sample period,
averaged over four boots:

| | reverb routed | share of the sample period |
|---|---|---|
| empty chain | — | 9.4 % |
| **reverb, as it is now** | **28.42 steps** | **22.4 %** |
| before the LFO and interpolation fixes | 26.15 | 20.6 % |
| with those fixes but a per-frame LFO | 33.54 | 26.4 % |

So one reverb is a fifth of the audio budget, which makes it comfortably the
most expensive effect here and the one to think about before stacking things
behind it.

**Those four figures were taken with the load meter as it was**, timing the
audio loop's idle spin with a 1 MHz timer — one tick of which is 4.8% of a
sample period, so each of them is a rounding of that. The meter counts cpu
cycles now, and re-measured it puts the reverb at **22.1%**, which is inside
the old instrument's resolution and does not move anything said here. The
before-and-after rows have not been re-measured, because doing so means
reflashing three superseded builds to correct figures by a few tenths.

The middle row is the honest cost of correctness: fixing the drifting LFOs and
interpolating the comb reads added 28.3%. Running the LFOs at control rate —
exact once every 32 frames, a straight line between — gave most of that back,
and the effect now costs 8.7% more than the broken version rather than 28.3%.
The remaining work is the comb read itself, which is irreducibly per-frame
because it reads audio.

## Reproducing this

```
cd Validation
make bench          # a stale bench measures a pedal you no longer have
./analyse-reverb.py
```

The cpu figures are not from that and will not be reproduced by it. They need
the pedal:

```
./measure-load.py -b 4
```

which sets routing live over SysEx, saves nothing, and reloads the scene when it
finishes. Read the note at the top of it before believing a single reading:
the empty-chain baseline wanders by a couple of steps between boots while the
routed reading holds still, so the number to compare between firmwares is the
routed absolute, averaged over several boots, and never a one-shot difference.

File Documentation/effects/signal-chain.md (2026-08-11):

# Signal Chain `[CHAIN]`

Not an effect, and it does not pretend to be one. It is the two ends of the
chain: **Trim** (−20..20 dB) and **Gate** (−100..−40 dB) with its **Attack**
(0..10 ms) and **Release** (50..500 ms) at the front, and **Volume**
(−40..20 dB) at the back. It always runs, it is never in the routing, and it
has no wet/dry mix — a gain stage cannot be blended against itself.

## The two gains, which are exactly what they say

```mermaid
%%{init: {'themeVariables': {'xyChart': {'plotColorPalette': '#0072b2'}}}}%%
xychart-beta
    title "Trim: gain applied to a 440 Hz tone"
    x-axis "Trim setting, dB" [-20, -12, -4, 0, 4, 12, 20]
    y-axis "measured gain, dB" -22 --> 22
    line [-20, -12, -4, 0, 4, 12, 20]
```

Volume is the same line shifted: −28.0, −16.0, −10.0, −4.0, +8.0 and +20.0 dB
at the settings that read that way. Both are exact to the second decimal, and
this section exists only so that the rest of the page is read against something
known to be boring.

The one wrinkle is at the bottom of Volume. Its range stops at −40 dB, but the
pot's zero is an explicit **silence** rather than −40, so that CC 7 at zero
means what a MIDI host means by it. −40 dB is a hundredth of an amplitude, so
the step from there to nothing is inaudible.

Trim and Volume are two controls rather than one because the chain between them
is full of things that are not linear. Where you sit on a triode curve, where
the boost starts folding, how far over the compressor's threshold you are — all
of that depends on the absolute level going in, and the DSP is calibrated to a
1 Vrms internal scale that any given guitar may miss by 20 dB either way. Trim
puts a pickup onto that scale; Volume then makes it as loud as you want without
disturbing any of it. Turn Trim up and Volume down by the same amount and you
hear the non-linearity by itself with the loudness held still, which is the only
honest way to judge it — louder always sounds better.

## The gate is three separate things

Everything interesting on this page is the gate, and it is built in three
pieces that are easy to confuse for one:

1. An **envelope follower** on the untrimmed input, with Attack and Release as
   its two time constants.
2. A **binary decision**: is that envelope above the threshold, or below it.
3. A **fixed ramp** that fades the gain between 0 and 1 once the decision
   flips.

**Attack and Release are the first piece only.** They are the detector's
ballistics — they decide *when* the gate changes its mind. They have nothing
to do with the third piece, which is where the fade actually happens and which
no control on the pedal can reach.

## What the threshold is worth

`Inputs/BassForLinus.mp3` is a friend of mine playing scales on a bass, 77
seconds of real dynamics, committed unmodified and scaled to −6 dBFS peak
(−25.9 dBFS RMS) for the same reasons the compressor page gives. Its quiet
passages sit around −57 dBFS and its 1st percentile is −78.

```mermaid
%%{init: {'themeVariables': {'xyChart': {'plotColorPalette': '#0072b2'}}}}%%
xychart-beta
    title "How much of the take the gate silences"
    x-axis "Gate threshold, dBFS" -100 --> -40
    y-axis "% of samples silenced" 0 --> 12
    line [0.0, 0.0, 0.0, 0.29, 2.01, 5.84, 11.08]
```

**At the default −70 dB this recording never gates at all** — 0.29% of it, which
is the space between takes and nothing else. That is not a criticism of the
default. A digital file has a noise floor no room has; the low end of the range
is aimed at a quieter input than any file on disk, and the number worth setting
it by is the floor meter, not this chart.

It does mean the rest of this page is measured with the threshold at the top of
its travel, −40 dBFS, because that is where both timing controls have something
to act on. Measuring a control somewhere it cannot act is how you conclude it
does nothing.

## Release: how long it waits

Measured as the time from a phrase ending — the input dropping below the
threshold and staying there — to the output actually reaching zero. Fourteen
such phrase ends in the take.

```mermaid
%%{init: {'themeVariables': {'xyChart': {'plotColorPalette': '#0072b2'}}}}%%
xychart-beta
    title "Time from the phrase ending to the gate shutting"
    x-axis "Release setting, ms" 50 --> 500
    y-axis "measured wait, ms" 0 --> 1200
    line [173, 348, 548, 747, 862, 1072]
```

A six-to-one range across the knob, and every step of it moves. Note that the
measured wait is several times the number on the pot: the pot is a time
*constant*, and what is being timed is an exponential decay falling all the way
from the note's level to the threshold, which is several time constants' worth.
So the knob is a rate, and the wait it produces also depends on how loud the
note was and where the threshold sits.

That last dependency is worth seeing, because at a lower threshold the top of
the pot stops working altogether:

```mermaid
%%{init: {'themeVariables': {'xyChart': {'plotColorPalette': '#0072b2, #d55e00'}}}}%%
xychart-beta
    title "Silenced at Gate -40 blue, at Gate -50 orange"
    x-axis "Release setting, ms" 50 --> 500
    y-axis "% of samples silenced" 0 --> 14
    line [13.34, 11.33, 9.47, 7.62, 6.3, 5.22]
    line [7.68, 5.99, 4.68, 3.68, 2.91, 2.63]
```

On the orange line the gate closes 8 times at 50 ms and **0 times at 500 ms** —
the envelope simply never gets down to the threshold before the next note
arrives. Both controls are live; it is that one can make the other inert, which
is the ordinary way two knobs on one detector interact rather than a fault in
either.

## Attack: about three milliseconds of say

The same measurement the other way round — from a note starting out of silence
to the output reaching full.

```mermaid
%%{init: {'themeVariables': {'xyChart': {'plotColorPalette': '#0072b2'}}}}%%
xychart-beta
    title "Time from the note starting to the gate fully open"
    x-axis "Attack setting, ms" [0, 1, 2, 4, 6, 8, 10]
    y-axis "measured delay, ms" 0 --> 22
    line [17.1, 17.8, 18.2, 19.0, 19.4, 19.8, 20.0]
```

Monotonic, and much less than it looks. The whole travel moves the opening by
**2.9 ms**, on top of a floor of 17.1 ms that is there at every setting. The
floor is the fixed ramp plus the detector's own lag; the pot supplies the rest.

So Attack is a real control with a small authority, and the gate's opening
speed is mostly not up to it. This was checked against three thresholds and
three different definitions of where a note starts, because the first ruler
tried gave a much more dramatic answer that did not survive the second one.

## The ramp, which no knob touches

```mermaid
%%{init: {'themeVariables': {'xyChart': {'plotColorPalette': '#0072b2, #d55e00'}}}}%%
xychart-beta
    title "Fade time. Opening blue, closing orange"
    x-axis [Release min, Release mid, default, Attack min, Attack max]
    y-axis "milliseconds" 0 --> 110
    line [9.5, 9.5, 9.5, 9.5, 9.5]
    line [95.9, 95.9, 95.9, 95.9, 95.9]
```

Two flat lines, and that is the point of the chart. The gate fades in over
**9.5 ms** and out over **95.9 ms**, and it does so at every setting of both
pots. The constants are written into `chain_step()`: `linear(0.01f, mult, 1.0f)`
going up and `linear(0.001f, mult, 0.0f)` coming down, each snapping to its rail
within a hundredth. That predicts ln(0.01)/ln(0.99) = 458 samples = 9.55 ms and
ln(0.01)/ln(0.999) = 4603 samples = 95.9 ms, which is what comes out.

**The ramp is about not popping**, and the asymmetry is deliberate and was set
by ear. It opens quickly because you do not want to lose the front of a note
when you start playing. It closes far more slowly because a long drawn-out
decay suddenly going away is very noticeable — much more noticeable than the
same amount of time spent opening. Whether 9.5 and 95.9 are the *right* numbers
is a fair question and they have never been measured against anything; what
they are is two values that sounded right.

## An honest doubt about the design

The ramp exists because the gate is a binary on/off decision on the envelope,
and a binary decision needs smoothing or it clicks. That is one design and not
obviously the best one. The alternative is a gate that has no decision and no
ramp in it at all: a multiplier that follows the envelope directly and clamps
at unity above the threshold, so the fade falls out of the envelope's own
ballistics and Attack and Release would then genuinely be the fade times.

What has kept it as it is, is a worry about amplitude modulation. A gain that
tracks the envelope closely is a gain that moves at the signal's own frequency,
and modulating a signal by something derived from itself is distortion — the
compressor page measures exactly this happening, at 11 dB per octave down,
which makes it a bass problem far more than a guitar one. A binary decision
plus a fixed ramp cannot do that, because the ramp's shape does not depend on
the signal level at all. It is a real trade and it has not been measured; the
current design is the cautious side of it.

## The trap this page was written around

The obvious way to measure a gate is to compare the total energy of the output
against the ungated output. Do not. Over this recording:

| Release | energy vs gate off | silenced |
|---|---|---|
| 50 ms | −0.01 dB | 13.34 % |
| 500 ms | −0.00 dB | 5.22 % |

The gate's behaviour changes by a factor of two and a half and the energy
number does not move. It cannot: everything a gate removes is, by construction,
quieter than the threshold, so it contributes almost nothing to a sum of
squares. An earlier attempt at this reported that Attack and Release "barely
change anything" on precisely that evidence. They change a great deal. What was
measured was the metric.

Everything above is therefore a timing, or a count, or a fraction of samples —
and never an average over the take.

## Reproducing this

```
cd Validation
make bench          # a stale bench measures a pedal you no longer have
./analyse-signal-chain.py
```

Needs `ffmpeg` for the decode, which is deterministic for a given ffmpeg; the
script prints the sample count, raw peak and scaled RMS first, so if those move
and nothing else changed, the decoder did.

The gate multiplier is recovered by dividing the gated output by the ungated
one, sample by sample — `chain_step()` applies the trim and the gate as one
scalar multiply, so the quotient is the firmware's own `chain.mult` exactly.
Where a note starts and ends is decided here, from the input, and never from
the firmware's envelope follower: that is the thing being measured, so it
cannot also be the ruler.

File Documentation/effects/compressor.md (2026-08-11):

# Compressor `[COMPRESSOR]`

Five controls: **Level** (−60..−10 dB, the threshold), **Attack** (2..100 ms),
**Release** (50..500 ms), **Ratio** (1..20×) and **Boost** (0..24 dB, makeup
gain). Defaults are −35 dB, 15 ms, 150 ms, 4.8× and 6 dB.

The arithmetic is short enough to state. An envelope follower tracks the
rectified input with those attack and release times; above the threshold the
gain becomes `(level/env)^(1 − 1/ratio)`, slewed to avoid clicks; and the
result is multiplied by Boost whatever happens. **So Boost is unconditional
and compression only ever subtracts** — quiet playing gets the makeup gain and
nothing else, loud playing gets the makeup gain minus whatever the ratio takes
away.

## The static answer, which is exact and not very useful

A steady tone at a series of levels, measuring the gain the compressor
settles on:

```mermaid
%%{init: {'themeVariables': {'xyChart': {'plotColorPalette': '#0072b2, #d55e00'}}}}%%
xychart-beta
    title "Gain applied to a steady tone. Level -20 blue, Level -30 orange"
    x-axis "input, dBFS peak" -60 --> -10
    y-axis "gain, dB" -10 --> 8
    line [6, 6, 6, 6, 6, 6, 6, 6, 6, 2.95, -1.01]
    line [6, 6, 6, 6, 6, 6, 6, 2.95, -1.01, -4.97, -8.94]
```

The knee sits exactly where Level says, and above it each 5 dB of input buys
1.04 dB of output — a ratio of 4.81, against the 4.8 on the pot. Nothing is
wrong with it.

It is also nearly worthless as a description of the effect, which is why this
page does not stop here. A compressor's whole job is changing its gain over
time in response to a signal that changes over time, and a tone that never
changes measures the one case that never happens.

## The dynamic answer

`Inputs/BassForLinus.mp3` is a friend of mine playing scales on a bass, 77
seconds of real dynamics. It is committed unmodified, so it matches the copy
it came from.

**The level it is played at is a measurement choice, not a detail.** The mp3
decodes to **+2.86 dBFS** — reconstruction overshoot on a master that was
already close to full scale — so used raw it would clip the pedal's input
before the compressor saw any of it. It is scaled to −6 dBFS peak, which is
where an instrument track is usually aimed, giving −25.9 dBFS RMS over the
whole take. A quieter input crosses the threshold less often and everything
below moves with it.

```mermaid
%%{init: {'themeVariables': {'xyChart': {'plotColorPalette': '#0072b2, #d55e00'}}}}%%
xychart-beta
    title "Level -30: input blue, output orange, half-second windows"
    x-axis "seconds" 0 --> 76
    y-axis "dBFS rms" -75 --> -10
    line [-69.5, -73.8, -71.6, -66.2, -25.3, -22.4, -25.1, -24.7, -23.6, -25.4, -28.2, -29.8, -33.6, -34.5, -35.3, -35.1, -32.7, -34.4, -32.4, -32.0, -30.7, -38.4, -36.3, -34.2, -36.1, -30.8, -27.9, -25.1, -23.6, -24.9, -26.0, -24.6, -28.6, -26.5, -25.6, -24.3, -24.5, -25.3, -26.5, -24.2, -25.7, -26.7, -27.4, -28.0, -36.9, -47.4, -63.5, -25.4, -24.5, -22.5, -22.1, -23.9, -25.4, -27.4, -36.1, -24.6, -24.6, -24.3, -23.7, -25.0, -27.0, -29.5, -37.7, -24.3, -24.7, -26.8, -23.3, -22.5, -24.9, -33.2, -41.3, -21.6, -27.8, -29.4, -28.4, -22.7, -23.9, -25.3, -32.2, -67.4, -62.0, -58.6, -54.3, -18.9, -23.5, -49.0, -31.7, -28.4, -23.7, -51.7, -54.0, -20.7, -22.5, -23.7, -30.9, -31.5, -42.8, -63.0, -35.9, -21.4, -22.1, -19.7, -25.8, -30.4, -39.1, -60.7, -44.6, -21.7, -23.1, -20.0, -20.5, -21.2, -23.7, -26.4, -34.6, -21.5, -22.0, -23.0, -24.1, -24.9, -25.2, -25.7, -29.0, -24.1, -25.8, -27.7, -28.3, -22.3, -23.2, -24.4, -25.1, -24.0, -24.5, -24.8, -27.5, -32.8, -29.2, -29.5, -28.2, -29.7, -28.5, -30.9, -30.2, -30.1, -27.1, -31.6, -34.2, -37.9, -25.8, -25.6, -26.3, -26.8, -27.4]
    line [-63.5, -67.8, -65.6, -60.2, -24.4, -24.3, -25.2, -24.9, -24.2, -25.3, -26.3, -26.1, -28.1, -28.5, -29.3, -29.1, -27.8, -28.6, -27.5, -27.2, -27.9, -32.4, -30.3, -28.4, -30.3, -25.9, -25.6, -25.2, -24.6, -25.1, -25.4, -25, -26.5, -25.3, -25.2, -25.1, -24.8, -25.9, -26.2, -24.2, -25.5, -25.7, -25.5, -25.4, -33.3, -41.4, -57.5, -24.3, -24.5, -24, -24.3, -24.9, -24.8, -25.2, -31.8, -24.6, -24.6, -24.8, -24.6, -25.6, -25.6, -26.2, -32.9, -23.9, -24.6, -25.5, -24.1, -24.6, -25.5, -31.3, -35.3, -23.2, -26.5, -26, -26.4, -23.8, -24.2, -24.7, -31.2, -61.4, -56, -52.6, -48.3, -21.9, -28.1, -43, -27.6, -25.8, -27.4, -45.7, -48, -22.8, -26.8, -24, -27.3, -26.8, -37.2, -57, -30.2, -23.6, -25.4, -24.1, -25.9, -27.2, -33.1, -54.7, -38.6, -23.3, -26.6, -23.1, -24.7, -25, -25.8, -26.4, -32.2, -23.4, -24.6, -24.8, -25.1, -25, -24.8, -25, -27.8, -23.8, -24.8, -25.1, -25.1, -23.6, -24.2, -24.5, -24.6, -24.7, -24.8, -24.8, -27, -27.4, -26.1, -27.4, -25.8, -26.8, -26.1, -27, -27.1, -26.8, -26.1, -26.5, -28.2, -31.9, -24.9, -25.3, -25.4, -25.3, -25.2]
```

That is the picture a tone cannot give. The blue line wanders over 50 dB; the
orange one spends most of the take between −24 and −28 dB. The passages the
player left quiet come up, the loud ones are held, and the shape of the phrase
survives — the orange line still rises and falls, it just does it over a
quarter of the range.

The silences are the exception and they are correct: where the input drops to
−67 dB between takes, the output sits 6 dB above it, because there is nothing
to compress and the makeup gain is unconditional. A compressor lifts the noise
floor between notes; this one is honest about it.

## What the threshold is worth

The same recording, gain plotted against how loud the playing was, at two
threshold settings:

```mermaid
%%{init: {'themeVariables': {'xyChart': {'plotColorPalette': '#0072b2, #d55e00'}}}}%%
xychart-beta
    title "Gain against playing level. Level -20 blue, Level -30 orange"
    x-axis "input, dBFS rms in half-second windows" -55 --> -16
    y-axis "gain, dB" -6 --> 8
    line [6, 6, 6, 6, 6, 5.99, 5.5, 3.7]
    line [6, 6, 5.87, 5.47, 4.23, 1.34, -1.3, -3.5]
```

At −20 dB, against this recording at this level, the effect never applies less
than +3.0 dB and never more than +6.0 — the blue line is flat until the loudest
few seconds and then bends slightly, which is a boost with a hint of
compression on top. The orange line, ten decibels down, is what a compressor's
transfer curve is supposed to look like: +6 dB on the quiet passages falling to
−3.5 dB on the loud ones, about 10 dB of range squeezed out of the performance.

Neither is right or wrong. Which one you get depends on how loud the signal
arriving is, and that is a thing the player sets — with Trim, with a boost, or
with whatever pedal is in front. What the threshold does is fix the distance
between the two.

**A caution about reading the two transfer curves together**: they do not
share an x-axis. The static one is the peak amplitude of a sine; this one is
half-second RMS of a bass. Those differ by the crest factor, which for plucked
bass is a good 12 dB, so the knee appears in a different place on each and
neither is wrong.

## What the knobs are worth

The threshold is compared against an envelope of the input, so how much any
setting does depends entirely on how hot the instrument is. That makes "is
this default any good" a question with three different answers:

```mermaid
%%{init: {'themeVariables': {'xyChart': {'plotColorPalette': '#0072b2, #d55e00, #009e73'}}}}%%
xychart-beta
    title "Dynamic range removed. Input peaking -6 blue, -12 orange, -20 green"
    x-axis "Level, dB" -40 --> -15
    y-axis "dB of range removed" -1 --> 17
    line [15.7, 12.0, 8.2, 4.4, 0.9, -0.0]
    line [11.2, 7.4, 3.6, 0.5, -0.0, -0.0]
    line [5.2, 1.5, -0.0, -0.0, -0.0, -0.0]
```

**At a realistic instrument level the default threshold does nothing at all.**
A guitar around 0.1 V RMS lands near −12 dBFS peak once its crest factor is
allowed for, and on that middle line the default −20 dB removes 0.0 dB of
dynamic range. You have to be at −35 before it takes out a useful 7 dB, and
−35 is most of the way to the bottom of a pot that stops at −40.

The top half of the Level control — everything above about −25 — does nothing
for any input a guitar produces.

## Attack and release cost low notes

A fast envelope follows the waveform rather than the note, and modulating the
gain at the note's own frequency is distortion. It is a bass problem far more
than a guitar one: the penalty falls about 11 dB per octave.

```mermaid
%%{init: {'themeVariables': {'xyChart': {'plotColorPalette': '#0072b2, #d55e00, #009e73'}}}}%%
xychart-beta
    title "THD by note. Release 50ms blue, 150ms orange, 500ms green"
    x-axis "Hz" [40, 80, 160, 320, 640]
    y-axis "THD, dB" -105 --> -35
    line [-40.5, -50.6, -62.0, -73.9, -85.8]
    line [-48.3, -58.5, -69.9, -81.8, -93.8]
    line [-57.6, -67.8, -79.2, -91.1, -103.1]
```

At the default 150 ms, a guitar's low E measures −58.5 dB and a bass low E
−48.4 dB. So the default is comfortable for the instrument this pedal is for
and marginal for the one an octave below it. Dropping to 50 ms costs 8 dB
everywhere and takes bass low E to −40.5 dB, which is audible.

Attack barely matters here by comparison — the whole 2 ms to 100 ms range
moves THD by 5 dB — while it does change how much gets squeezed, from 9.9 dB
at 2 ms to 4.3 dB at 100 ms. So attack is close to a free control and release
is not.

Ratio is nearly free above about 8: at Level −30 it buys 8.8 dB of squeeze at
8:1 and 9.4 dB at 20:1, against 8.2 dB at the default 4.8.

## What the defaults are, and why

**These were made up.** The controls were given plausible-sounding numbers when
the effect was written and had never been measured. The ranges too.

Measuring changed one of them. Because the response is a pure translation, the
end of the pot is a wall: with the old `LINEAR(-40 0)`, a guitar arriving at
about −20 dBFS peak could not get more than roughly 5 dB of compression at any
setting, simply because the knob stopped. The range is now `LINEAR(-60 -10)`,
which costs 0.42 dB per step against 0.33 and forecloses nothing.

With that room, here is what each candidate default does to the instrument
somebody actually plugs in — no trim, nothing in front:

```mermaid
%%{init: {'themeVariables': {'xyChart': {'plotColorPalette': '#0072b2, #d55e00, #009e73, #666666'}}}}%%
xychart-beta
    title "dB removed by pickup. 280mVpp blue, 500mVpp orange, 1Vpp green, 2Vpp grey"
    x-axis "Level, dB" [-30, -33, -35, -37, -40, -45]
    y-axis "dB of range removed" -1 --> 21
    line [-0, 0.4, 1.4, 2.9, 5.1, 8.9]
    line [1.4, 3.5, 5.1, 6.6, 8.9, 12.7]
    line [5.9, 8.1, 9.7, 11.3, 13.5, 17.0]
    line [10.4, 12.7, 14.3, 15.8, 17.6, 20.5]
```

Peak-to-peak volts convert through `process.h`: a sample is the instantaneous
volts over √2, because 1.0 is a 1 Vrms sine peaking at 1.414 V. So the README's
"typical" 280 mVpp is −20.1 dBFS peak, and a hot pickup at 500 mVpp is −15.1.

**−35 dB** is the default, and two things pick it. It gives 5.1 dB of reduction
on a hot pickup and 9.7 dB on a humbucker — a compressor doing something the
moment you switch it on, which is presumably why you switched it on. And it
sits at exactly mid-travel on the new range, so the knob's centre is the
sensible setting and both directions mean something.

It is deliberately gentle on a quiet single-coil, 1.4 dB. That is what the 25 dB
of travel below it is for.

The other four hold up, with one repair. Ratio's *values* were always fine —
4.8 is in the useful part of the curve and above 8:1 buys almost nothing — but
the pot was `LINEAR(1 20)` while the compressor uses `1 − 1/ratio`, which
saturates. The first twentieth of the travel covered more than half the effect
and the last 63% covered 0.7 dB. It is `EXPONENTIAL(1 20)` now: the same
values, the same reach, spread across the knob instead of piled at one end.

Attack costs 5 dB of THD across its whole range while changing the squeeze by
more than twice that. Release is right for guitar and marginal an octave below.

## Reproducing this

```
cd Validation
make bench          # a stale bench measures a pedal you no longer have
./analyse-compressor.py
```

Needs `ffmpeg` for the decode. That decode is deterministic for a given
ffmpeg, and the script prints the sample count, raw peak and scaled RMS
first — if those move and nothing else changed, the decoder did.

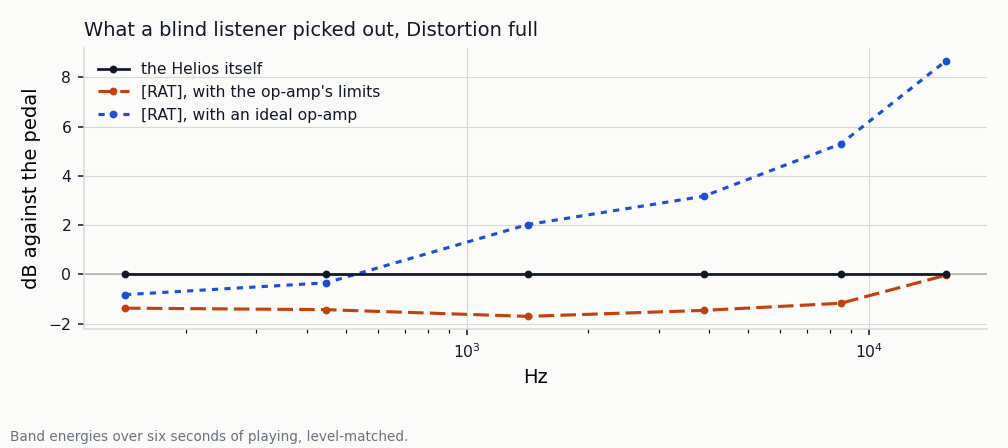
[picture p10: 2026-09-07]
Documentation/effects/figures/rat-brightness.png

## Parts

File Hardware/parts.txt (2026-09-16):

#
# The parts worth using again.  Hardware/parts.README has the format.
#
# One line of comment or none, and only where it is critical to the
# part.  Anything that has to be looked at before an order is a CHECK:
# line instead.
#
## Capacitors

0.3pF/50V/±0.1pF/C0G/0201:
	Murata GRM0335C1HR30BA01D
	C76927

1.5pF/25V/±0.05pF/C0G/0201:
	Murata GJM0335C1E1R5WB01D
	C435397

2.0pF/25V/±0.05pF/C0G/0201:
	Murata GJM0335C1E2R0WB01D
	C668326

15pF/25V/5%/C0G/0201:
	Murata GRM0335C1E150JA01D
	C161373

15pF/50V/5%/C0G/0402:
	Murata GRM1555C1H150JA01D
	C76950

150pF/25V/5%/C0G/0402:
	Murata GRM1555C1E151JA01D
	C710836

2.2nF/25V/10%/X7R/0201:
	Murata GRM033R71E222KA12D
	C161488

2.2nF/50V/2%/C0G/0402:
	Murata GRM1555C1H222GA01D
	C2987940

10nF/25V/10%/X7R/0201:
	Murata GRM033R71E103KE14D
	C85930

22nF/50V/10%/X7R/0402:
	Fenghua 0402B223K500NT
	C1532

# The Z7 in the Murata code is X7R, not the X7T it looks like.
0.1uF/16V/X7R/0201:
	Murata GRM033Z71C104ME14D
	C3901090

0.1uF/16V/10%/X7R/0402:
	Samsung CL05B104KO5NNNC
	C1525

1uF/16V/5%/X7R/0603:
	Yageo CC0603JRX7R7BB105
	C519560

1uF/25V/10%/X7R/0603:
	Murata GCM188R71E105KA64D
	C85862

2.2uF/25V/10%/X7R/0603:
	Murata GRM188Z71E225KE43D
	C415535

2.2uF/25V/10%/X7R/0805:
	Murata GRM21BR71E225KE11L
	C77081

4.7uF/25V/20%/X5R/0402:
	Murata GRM155R61E475ME15D
	C2858031

4.7uF/50V/10%/X7R/0805:
	Murata GRM21BZ71H475KE15L
	C437557

10uF/25V/20%/X5R/0603:
	Murata GRM188R61E106MA73D
	C91606

22uF/25V/20%/X5R/0805:
	Murata GRM21BR61E226ME44L
	C86816

22uF/25V/10%/X7R/1210:
	Samsung CL32B226KAJNNNE
	C309062

# Hybrid electrolytic.
47uF/35V/D6.3xL5.8:
	Panasonic EEHZA1V470P
	C178639
	Capacitor_SMD:CP_Elec_6.3x5.9

## Resistors

1Ω/50V/1%/0402:
	FOJAN FRC0402F1R00TS
	C2909329

1Ω/75V/1%/0603:
	UniRoyal 0603WAF100KT5E
	C22936 basic

10Ω/50V/1%/0402:
	UniRoyal 0402WGF100JTCE
	C25077 basic

33Ω/25V/5%/0201:
	UniRoyal 0201WMJ0330TEE
	C423356

33Ω/50V/1%/0402:
	UniRoyal 0402WGF330JTCE
	C25105 basic

100Ω/50V/0.1%/thin-film/0402:
	Yageo RT0402BRD07100RL
	C705627

220Ω/50V/1%/0402:
	UniRoyal 0402WGF2200TCE
	C25091 basic

1kΩ/25V/1%/0201:
	UniRoyal 0201WMF1001TEE
	C270365

1kΩ/50V/1%/0402:
	UniRoyal 0402WGF1001TCE
	C11702 basic

1kΩ/50V/1%/thin-film/0402:
	Yageo RT0402FRE071KL
	C136974

2.2kΩ/50V/1%/0402:
	UniRoyal 0402WGF2201TCE
	C25879 basic

4.7kΩ/50V/1%/0402:
	UniRoyal 0402WGF4701TCE
	C25900 basic

5.1kΩ/25V/1%/0201:
	UniRoyal 0201WMF5101TEE
	C270344

5.1kΩ/50V/1%/0402:
	UniRoyal 0402WGF5101TCE
	C25905 basic

100kΩ/50V/1%/0402:
	UniRoyal 0402WGF1003TCE
	C25741 basic

249kΩ/25V/1%/0201:
	Yageo RC0201FR-07249KL
	C273273

1MΩ/50V/1%/thin-film/0402:
	Vishay MCS04020C1004FE000
	C1884615

## Inductors

2.7nH/600mA/0201:
	Murata LQP03HQ2N7B02D
	C7216765
	Inductor_SMD:L_0201_0603Metric

3.5nH/500mA/0201:
	Murata LQP03HQ3N5B02D
	C3911055
	Inductor_SMD:L_0201_0603Metric

1uH/2A/0806:
	Murata LQM2MPN1R0MGHL
	C528977
	Mylib:L_0806

2.2uH/1.8A/0806:
	Murata DFE201612E-2R2M=P2
	C337893
	Mylib:L_0806
	https://pim.murata.com/asset/pim4/inductor/J(E)TE243A-0006_PDF_INDUCTOR

# Polarised, and the inductor the RP2350 datasheet specifies.
3.3uH/0806:
	Abracon AOTA-B201610S3R3-101-T
	C42411119
	Mylib:AOTA-B2016
	https://abracon.com/datasheets/AOTA-B201610S3R3-101-T.pdf
	CHECK: polarised, and the body is symmetrical - match the silkscreen
	CHECK: dot to JLCPCB's.  The dot is the outer winding, our pad 1
	JLC: rotate 180

4.7uH/350mA/0603:
	TDK MLZ1608M4R7WT000
	C76799
	Inductor_SMD:L_0603_1608Metric

## Ferrite beads

120Ω@100MHz/200mA/0201:
	Murata BLM03AG121SN1D
	C97850
	Inductor_SMD:L_0201_0603Metric

## Diodes

# KiCad's Part field says LRC LMBR130T1G; that is not what C191023 ships.
1N5819WS/40V/1A/SOD-323:
	Guangdong Hottech 1N5819WS
	C191023
	Diode_SMD:D_SOD-323

# Common cathode.
BAT54CW/30V/SOT-323:
	hongjiacheng BAT54CW
	C22392482
	Package_TO_SOT_SMD:SOT-323_SC-70
	https://assets.nexperia.com/documents/data-sheet/BAT54W_SER.pdf
	CHECK: rotation applied automatically, and never yet seen on a board
	JLC: rotate 180

# Series connected.
BAT54SW/30V/SOT-323:
	hongjiacheng BAT54SW
	C22466373
	Package_TO_SOT_SMD:SOT-323_SC-70
	https://assets.nexperia.com/documents/data-sheet/BAT54W_SER.pdf
	CHECK: rotation applied automatically - confirm the body matches the
	CHECK: footprint outline in the assembly preview
	JLC: rotate 180

SM4007PL/1kV/1A/SOD-123FL:
	MDD SM4007PL
	C64898
	Mylib:SOD-123FL

## LEDs

LED/yellow-green/2V/0402:
	Lite-On LTST-C281KGKT
	C160479

# Top-emitting.
WS2812B/2020:
	Worldsemi WS2812B-2020-V6
	C52917434
	LED_SMD:LED_WS2812B-2020_PLCC4_2.0x2.0mm
	https://cdn-shop.adafruit.com/product-files/4684/4684_WS2812B-2020_V1.3_EN.pdf
	CHECK: JLCPCB have queried this footprint's pin-1 marking before

# Side-emitting.  The -V6 is not a drop-in for the earlier version
WS2812B/4020:
	Worldsemi WS2812B-4020-V6
	C52941387
	Mylib:WS2812B-4020-V6
	CHECK: Check footprint offsets

## Crystals

32MHz/8pF/20ppm/2016:
	YXC X201632MKB4SI
	C718072
	Crystal:Crystal_SMD_2016-4Pin_2.0x1.6mm

# 10pF load capacitance.  3225 is the metric size, 3.2 x 2.5mm.
ABM8/12MHz/30ppm/3225:
	Abracon ABM8-272-T3
	C20625731
	Crystal:Crystal_SMD_3225-4Pin_3.2x2.5mm

## Antennas

# Needs 6.5 x 6.5mm of ground clearance at a board edge.
2.4GHz/chip/1206:
	Johanson 2450AT18A100E
	C89334
	RF_Antenna:Johanson_2450AT18x100
	https://www.johansontechnology.com/docs/3827/Antenna-2450AT18A0100001E-Rev4.0.pdf

## Connectors

AFH-5/12P/0.5mm-FFC:
	JUSHUO AFH05-S12FIA-1H
	C5371161
	Mylib:AFH-5-S12FIA-1H

AudioJack/TRRS/PJ-320D:
	SHOU HAN PJ-320D
	C431535
	Mylib:PJ-320D
	CHECK: 7.4mm origin offset applied automatically - confirm the pads land
	JLC: offset +7.400 +0.000

BM28/24P/0.35mm/plug:
	Hirose BM28B0.6-24DP/2-0.35V(51)
	C424568
	Mylib:BM28B0.6-24DP
	https://www.hirose.com/product/series/BM28

BM28/24P/0.35mm/socket:
	Hirose BM28B0.6-24DS/2-0.35V(51)
	C424569
	Mylib:BM28B0.6-24DS
	https://www.hirose.com/product/series/BM28

JST-SH/4P/1.00mm:
	JST SM04B-SRSS-TB(LF)(SN)
	C160404
	Connector_JST:JST_SH_SM04B-SRSS-TB_1x04-1MP_P1.00mm_Horizontal
	JLC: offset +0.000 -0.062

# Horizontal.  JLCPCB ships a G-Switch part; the footprint is named for a GCT USB4105.
USB-C/2.0/16P/GT-USB-7010C:
	G-Switch GT-USB-7010C
	C2843967
	Connector_USB:USB_C_Receptacle_GCT_USB4105-xx-A_16P_TopMnt_Horizontal
	CHECK: origin offset applied automatically - confirm the pads land
	JLC: offset +0.000 -1.305

# Vertical.
USB-C/2.0/16P/GT-USB-7051A:
	G-Switch GT-USB-7051A
	C2843970
	Connector_USB:USB_C_Receptacle_G-Switch_GT-USB-7051x

# Mid-mount, CB1.6 being the board thickness: the body needs a 9.24 x 6.50mm notch, which the footprint carries on Edge.Cuts.
USB-C/2.0/16P/mid-mount/TYPE-C-16P-CB1.6:
	SHOU HAN TYPE-C 16P CB1.6 073
	MPN: TYPE-C 16P CB1.6 073
	C2906290
	Mylib:TYPE-C-16P-CB1.6
	https://atta.szlcsc.com/upload/public/pdf/source/20211021/35D048B933FA988260DD32545575C1A5.pdf
	CHECK: confirm Edge.Cuts carries the notch and the outline is broken for it

## Switches

# About 2mm tall; the family shares this footprint and differs in height.
TS-1088/tactile/1.6N/SMD-4x3mm:
	XUNPU TS-1088-AR02016
	C720477 basic
	Button_Switch_SMD:SW_SPST_TS-1088-xR020

ZX-QC1212/tactile/SMD:
	ZX-QC1212-4.3TP
	C7470196
	Mylib:ZX-QC1212

## Integrated circuits

# 8MB PSRAM, QSPI.
APS6404L/3.3V/USON-8L:
	AP-Memory APS6404L-3SQR-ZR
	C3040877
	Package_SON:Winbond_USON-8-1EP_3x2mm_P0.5mm_EP0.2x1.6mm
	https://www.mouser.com/datasheet/2/1127/APM_PSRAM_QSPI_APS6404L_3SQR_v2_3_PKG-1954826.pdf
	JLC: rotate 90

# Latching TMR switch: the magnet must move *past* it, not merely closer.
# BOP +/-9 Gs, from the D series electrical table - the ordering-code page
# says 98 Gauss and contradicts its own feature list and the A/B/C/E run.
KTM1331TD/latch/9Gs/continuous/SOT-23:
	CONNTEK KTM1331TD-ST3
	C7544656
	Package_TO_SOT_SMD:SOT-23
	https://wmsc.lcsc.com/wmsc/upload/file/pdf/v2/lcsc/2404011708_CONNTEK-KTM1331TD-ST3_C7544656.pdf
	JLC: rotate 180

# i2c EEPROM.
M24C02/2Kbit/UFDFPN-5:
	STM M24C02-FMH6TG
	C222197
	Mylib:UFDFPN5
	https://www.st.com/resource/en/datasheet/m24c02-r.pdf

# i2c EEPROM.
M24C64/64Kbit/UFDFPN-5:
	STM M24C64-FMH6TG
	C222104
	Mylib:UFDFPN5
	https://www.st.com/en/memories/m24c64-f.html#documentation

# The radio.  1MB of RRAM, not flash.
NRF54L10/VFQFN-48:
	Nordic NRF54L10-QFAA-R7
	C44800139
	Package_DFN_QFN:QFN-48-1EP_6x6mm_P0.4mm_EP4.6x4.6mm_ThermalVias
	https://docs.nordicsemi.com/bundle/ps_nrf54l15

# Dual op-amp, rail-to-rail in but out only to within 15-45mV.  Maximum 7V.
OPA2323/TSOT-23-8:
	TI OPA2323IDDFR
	C36686067
	Package_TO_SOT_SMD:TSOT-23-8
	https://www.ti.com/lit/ds/symlink/opa2323.pdf

# Dual op-amp.  Absolute maximum 5.5V.
OPA2365/SOIC-8:
	TI OPA2365AIDR
	C130011
	Package_SO:SOIC-8_3.9x4.9mm_P1.27mm
	JLC: rotate 90

# The MCU.
RP2354A/QFN-60:
	Raspberry Pi RP2354A
	C41378174
	Package_DFN_QFN:QFN-60-1EP_7x7mm_P0.4mm_EP3.4x3.4mm_ThermalVias
	https://datasheets.raspberrypi.com/rp2350/hardware-design-with-rp2350.pdf

# Single tri-state buffer, TTL input thresholds.
SN74AHCT1G125/SC-70-5:
	TI SN74AHCT1G125DCKR
	C350557
	Package_TO_SOT_SMD:SOT-353_SC-70-5
	http://www.ti.com/lit/sg/scyt129e/scyt129e.pdf
	CHECK: rotation applied automatically; 255um residual is worth an eye
	JLC: rotate 90

# Stereo codec, i2c.  105dB ADC / 114dB DAC.  One land pattern for all TAC5xxx.
TAC5112/VQFN-24:
	TI TAC5112IRGER
	C44853692
	Mylib:TAC5242
	https://www.ti.com/lit/ds/symlink/tac5112.pdf

# Stereo codec, i2c.  119dB ADC / 120dB DAC.
TAC5212/VQFN-24:
	TI TAC5212IRGER
	C44853694
	Mylib:TAC5242
	https://www.ti.com/lit/ds/symlink/tac5212.pdf
	CHECK: stock was single-digit on 2026-09-09 - confirm before ordering

# Stereo codec, no i2c: hardware-strapped on MD0-MD5.
TAC5242/VQFN-24:
	TI TAC5242IRGER
	C47122155
	Mylib:TAC5242
	https://www.ti.com/lit/ds/symlink/tac5242.pdf

# Optocoupler.
TLP2310/SOP:
	Toshiba TLP2310
	C7473281
	Package_SO:SO-5-6_4.55x3.7mm_P1.27mm
	https://toshiba.semicon-storage.com/info/TLP2310_datasheet_en_20220913.pdf
	CHECK: rotation applied automatically - confirm in the preview
	JLC: rotate 90

# 3.3V fixed LDO, low noise.  EN has an internal pullup, so it may float.
TLV76733/3.3V/WSON-6:
	TI TLV76733DRVR
	C2848334
	Package_SON:WSON-6-1EP_2x2mm_P0.65mm_EP1x1.6mm
	http://www.ti.com/lit/gpn/TLV767

# 5V fixed LDO, low noise.
TLV76750/5V/WSON-6:
	TI TLV76750DRVR
	C2872569
	Package_SON:WSON-6-1EP_2x2mm_P0.65mm_EP1x1.6mm
	http://www.ti.com/lit/gpn/TLV767

# 3-axis magnetic sensor, SPI.
TMAG5170-Q1/VSSOP-8:
	TI TMAG5170A1QDGKR
	C5220642
	Package_SO:VSSOP-8_3x3mm_P0.65mm
	https://www.ti.com/lit/ds/symlink/tmag5170-q1.pdf
	JLC: rotate 90

# Fixed 5V buck.  No MODE pin, so power-save cannot be disabled.
TPS62153/5V/QFN-16:
	TI TPS62153RGTR
	C477927
	Package_DFN_QFN:VQFN-16-1EP_3x3mm_P0.5mm_EP1.68x1.68mm_ThermalVias
	http://www.ti.com/lit/ds/symlink/TPS62150.pdf
	JLC: rotate 90

# Buck converter, output set by a single VSET resistor.
TPS628438/SOT-563:
	TI TPS628438DRLR
	C38060243
	Package_TO_SOT_SMD:SOT-563
	https://www.ti.com/lit/ds/symlink/tps62843.pdf
	JLC: rotate 180

# USB ESD protection; pins 1 and 6 are one node and 3 and 4 another.
USBLC6/SOT-666:
	STM USBLC6-2P6
	C15999
	Package_TO_SOT_SMD:SOT-666
	https://www.st.com/resource/en/datasheet/usblc6-2.pdf
	JLC: rotate 180

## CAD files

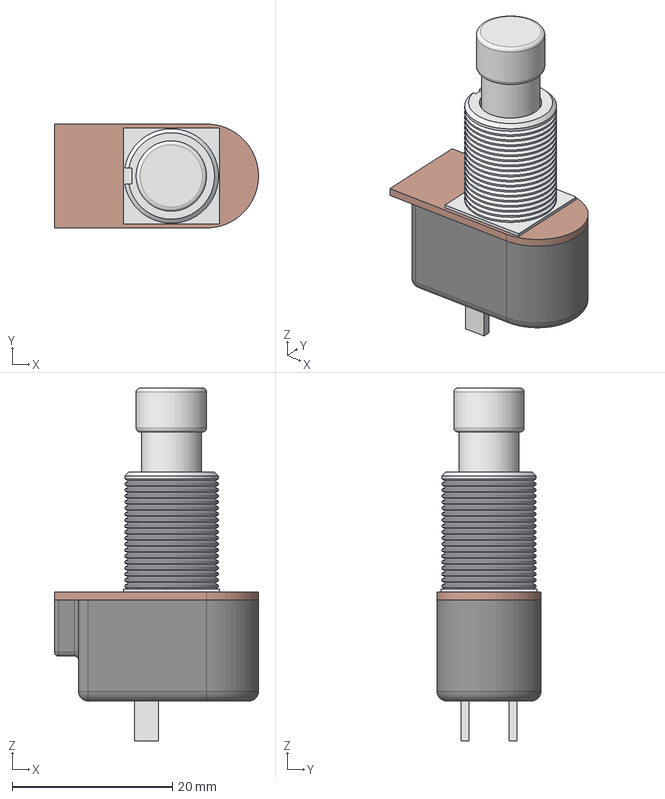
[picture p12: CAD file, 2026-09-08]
Hardware/symbols/PBS-24B-2.step
25.5 x 13.0 x 44.1 mm
metal
plate

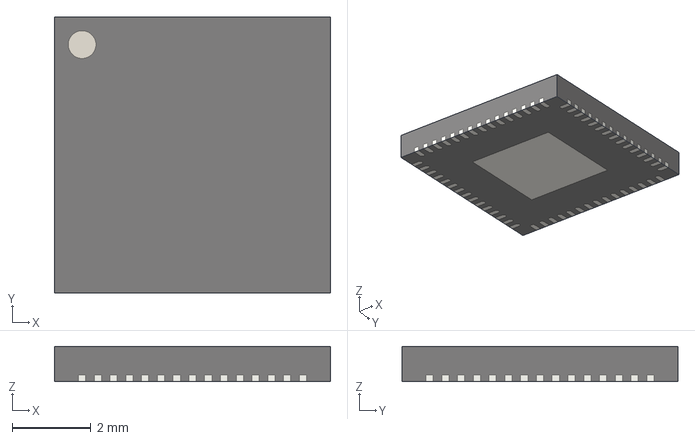
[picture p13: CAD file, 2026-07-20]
Hardware/symbols/QFN-60-1EP_7x7mm_P0.4mm_EP3.4x3.4mm.step
7.00 x 7.00 x 0.9 mm

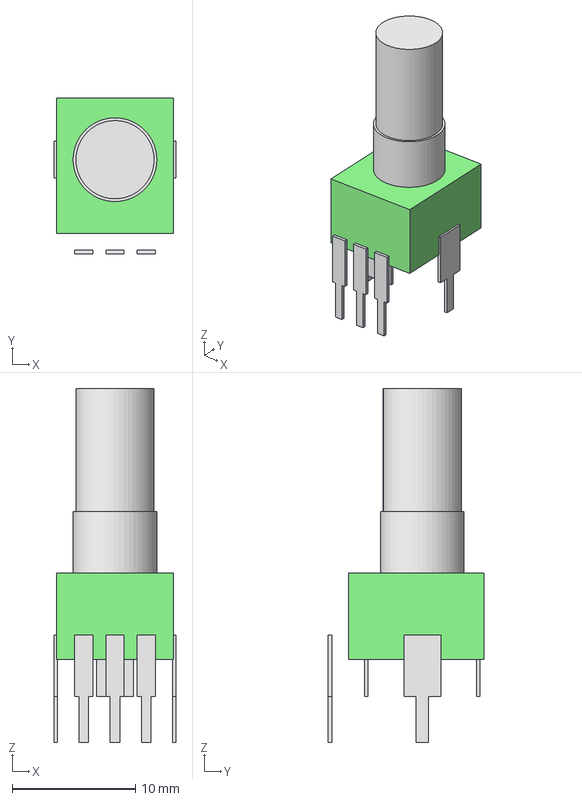
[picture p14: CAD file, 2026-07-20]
Hardware/symbols/Pot-9mm.step
9.90 x 12.7 x 28.8 mm

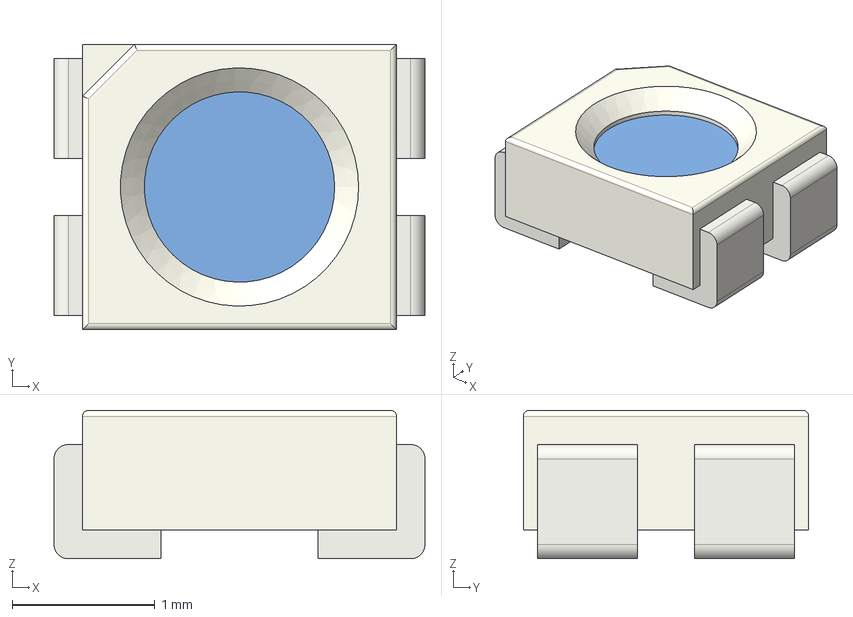
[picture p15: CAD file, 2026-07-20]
Hardware/symbols/LED_WS2812B-2020.step
2.60 x 2.00 x 1.04 mm

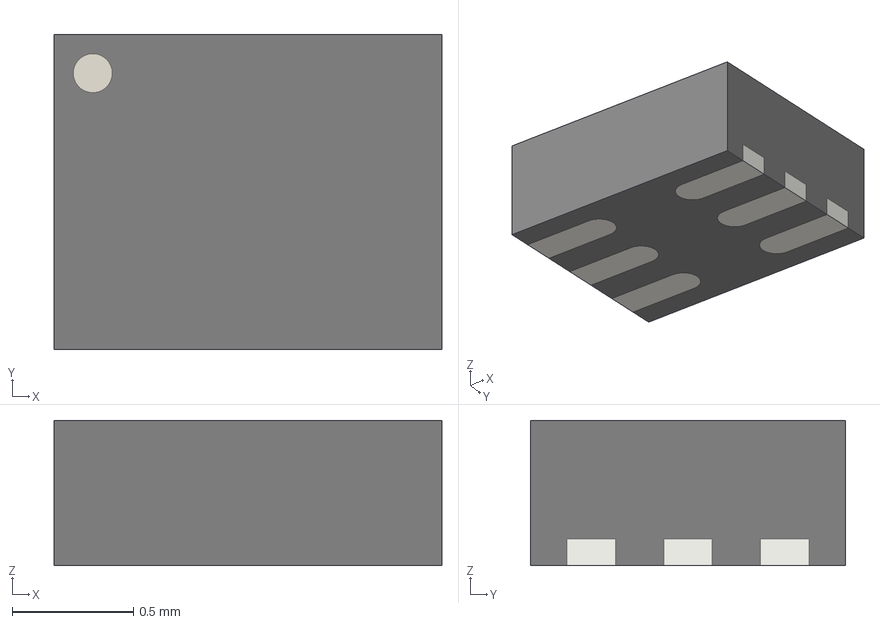
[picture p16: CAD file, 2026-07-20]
Hardware/symbols/DFN-6_1.6x1.3mm_P0.4mm.step
1.60 x 1.30 x 0.6 mm

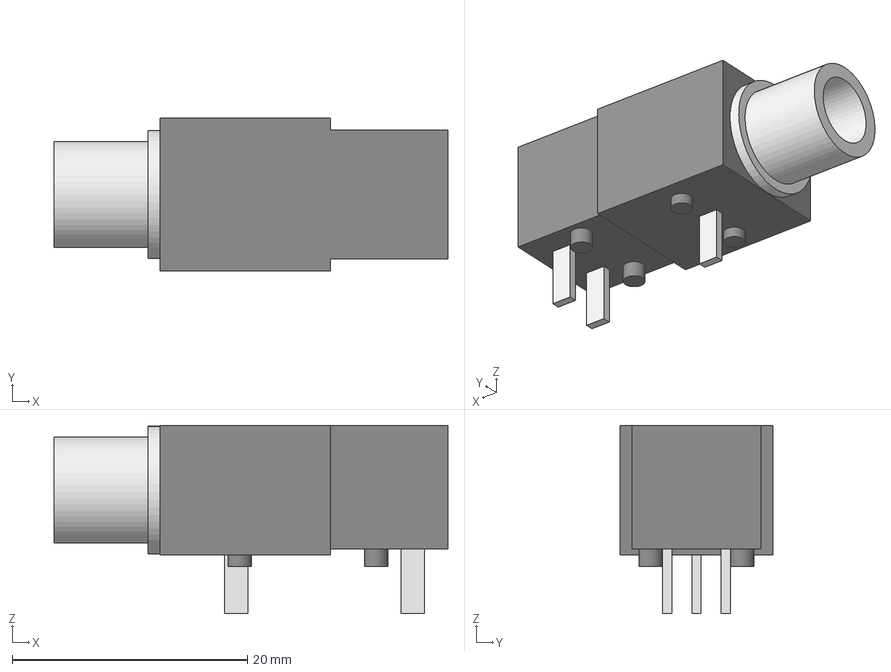
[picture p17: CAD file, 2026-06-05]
Hardware/symbols/CK-6.35-Stereo.step
33.5 x 13.0 x 16.0 mm
Matrix_Union

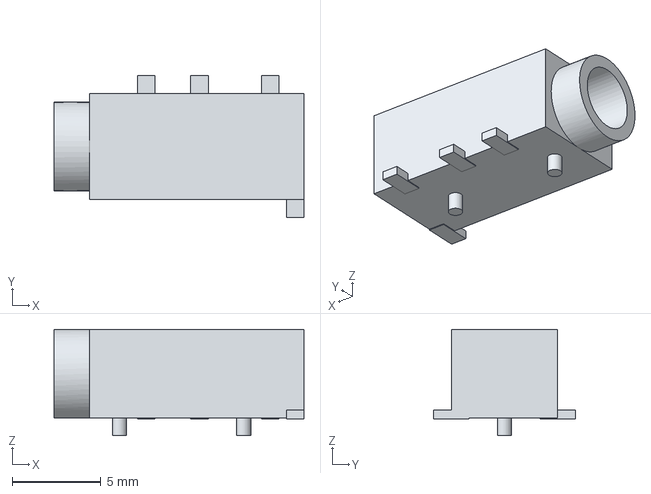
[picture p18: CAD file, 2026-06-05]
Hardware/symbols/PJ-320D.step
14.1 x 8.00 x 6.00 mm

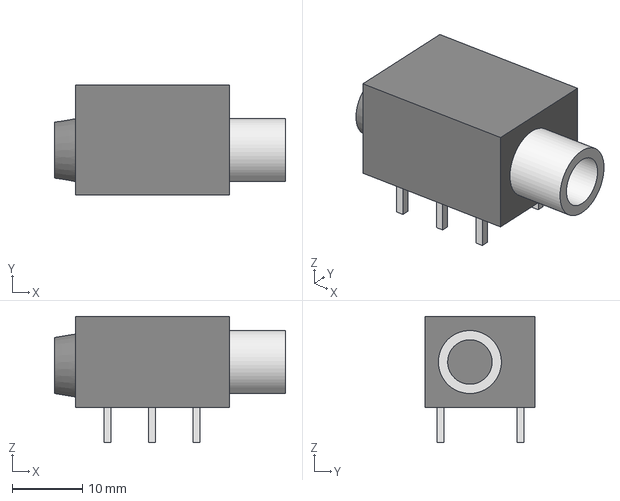
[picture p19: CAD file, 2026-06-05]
Hardware/symbols/NRJ6HM-1-PRE.step
33.0 x 15.8 x 18.0 mm

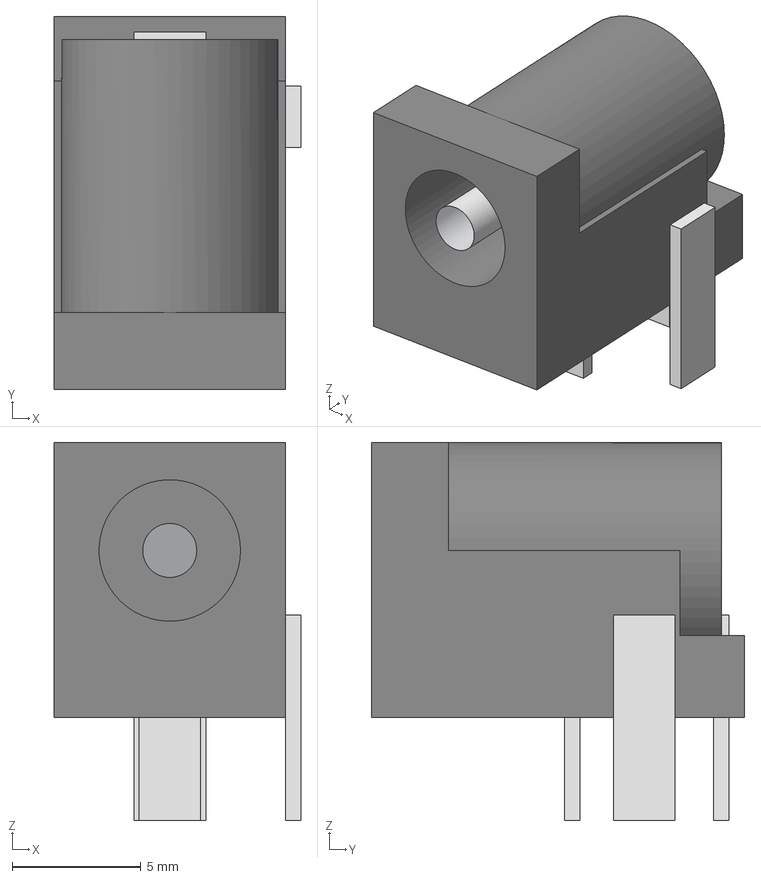
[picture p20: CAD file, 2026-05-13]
Hardware/symbols/WR-DC-2.1.step
9.60 x 14.5 x 14.7 mm

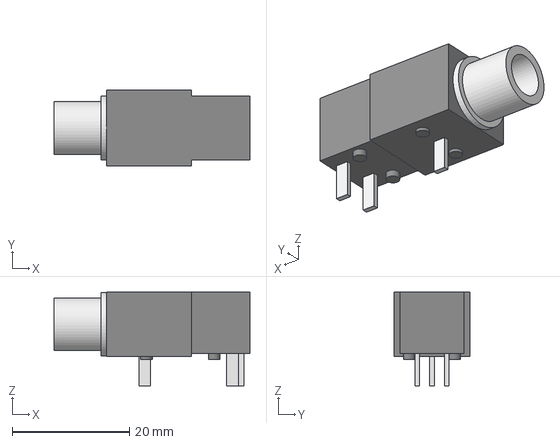
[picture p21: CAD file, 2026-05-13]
Hardware/symbols/CK-6.35-308.step
33.5 x 13.0 x 16.0 mm

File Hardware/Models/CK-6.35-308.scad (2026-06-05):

$fn=40;

black = [0.2,0.2,0.2];
silver = [0.75,0.75,0.75];

// The model is centered on the front pin
// as per the data sheet
pins = [ [0, 0], [15, -2.5], [16, 2.5]];

feet = [ [ 0.3,3.9], [ 0.3,-3.9],
	 [11.9,3.9], [11.9,-3.9] ];

module body()
{
    translate([-6.5,-6.5])
	cube([14.5,13,11]);
    translate([8,-5.5,0.5])
	cube([10,11,10.5]);
}

module barrel()
{
    difference() {
	cylinder(9, d=9);
	translate([0,0,-1])
	    cylinder(11, d=6.35);
    }

}

module jack()
{
    translate([-6.5,0,5.5]) rotate([0,-90,0]) {
	cylinder(1, d=10.9);
	barrel();
    }
}

color(black) body();
color(silver) jack();

// Feet or locating pins..
color(black) translate([0,0,-1]) for (pos = feet)
	translate(pos) cylinder(2, d=2);

// Pins
color(silver) for (pos = pins)
	translate(pos) translate([0,0,-2]) cube([2,0.8,6], center=true);

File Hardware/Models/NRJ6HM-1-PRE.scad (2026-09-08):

$fn=40;

red = [0.8,0.2,0.2];
black = [0.2,0.2,0.2];
silver = [0.75,0.75,0.75];
epsilon = 0.001;

// The model is centered on the barrel
//
// The pins are the footprint's, with y negated because OpenSCAD is y-up
// and KiCad is y-down.  They were measured with calipers originally and
// were out by 50um on the column pitch and 115um on the row spacing;
// these are the corrected numbers, taken from the part's own data via
// EasyEDA - 6.400 pitch, 11.200 rows.
pins = [ [-17.5,7.115],  [ -11.1,7.115 ], [-4.7,7.115],
	 [-17.5,-4.085], [-11.1,-4.085], [-4.7,-4.085 ] ];

module body()
{
    union() {
	translate([-22,-6.43,0])
	    cube([22,15.75,13]);
	translate([-25,0,6]) {
	    rotate([0,90,0]) {
		cylinder(3,d1=8,d2=9);
	    }
	}
    }
}

module barrel()
{
    translate([0,0,6.5]) rotate([0,90,0]) {
	difference() {
	    cylinder(8,d=9);
	    cylinder(9,d=6.35);
	}
    }
}

module nrj6hm()
{
    color(black) body();
    color(silver)
	barrel();
    // Pins
    color(silver) for (pos = pins)
	translate(pos) translate([0,0,-2]) cube([1,1,6], center=true);
}

nrj6hm();

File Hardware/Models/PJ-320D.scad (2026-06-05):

$fn=40;

black = [0.2,0.2,0.2];
silver = [0.75,0.75,0.75];

// The model is centered on the front
// as per the data sheet, but with the
// cylinder sticking out 2mm, so 0,0
// is where the cube body starts
// (datasheet numbers are relative to
// the 2mm tip of the cylinder)

pins = [ [11.6,-3], [3.2, 3], [6.2, 3], [10.2, 3] ];

module body()
{
	difference() {
		union() {
			translate([0,-3,0]) cube([12.1, 6, 5]);
			translate([0,0,2.5]) rotate([0,-90,0]) cylinder(h=4,d=5, center=true);
			translate([1.7,0,0]) cylinder(d=0.8,h=2,center=true);
			translate([8.7,0,0]) cylinder(d=0.8,h=2,center=true);
		}
		translate([8,0,2.5]) rotate([0,-90,0])
			cylinder(12,d=3.6);
	}
}

module pj320d()
{
	color(black)
		body();

	// Pads
	color(silver) for (pos = pins)
		translate(pos) translate([0,0,0.2]) cube([1,2,0.5], center=true);
}

pj320d();

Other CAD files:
Hardware/Models/CK-6.35-Stereo.scad
Hardware/Models/stomp.scad

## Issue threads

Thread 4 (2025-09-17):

Continuation from 1590A: Throughholes for mounting screws in PCBs needed

alekssadowski95, 2025-09-17:
How do the "DaisySeed" and "Stomp" pcbs relate to each other?

Is the 1590B something that you came up wth or is this another enclosure from Hammond?

I would like to understand the requirements of the enclosures.

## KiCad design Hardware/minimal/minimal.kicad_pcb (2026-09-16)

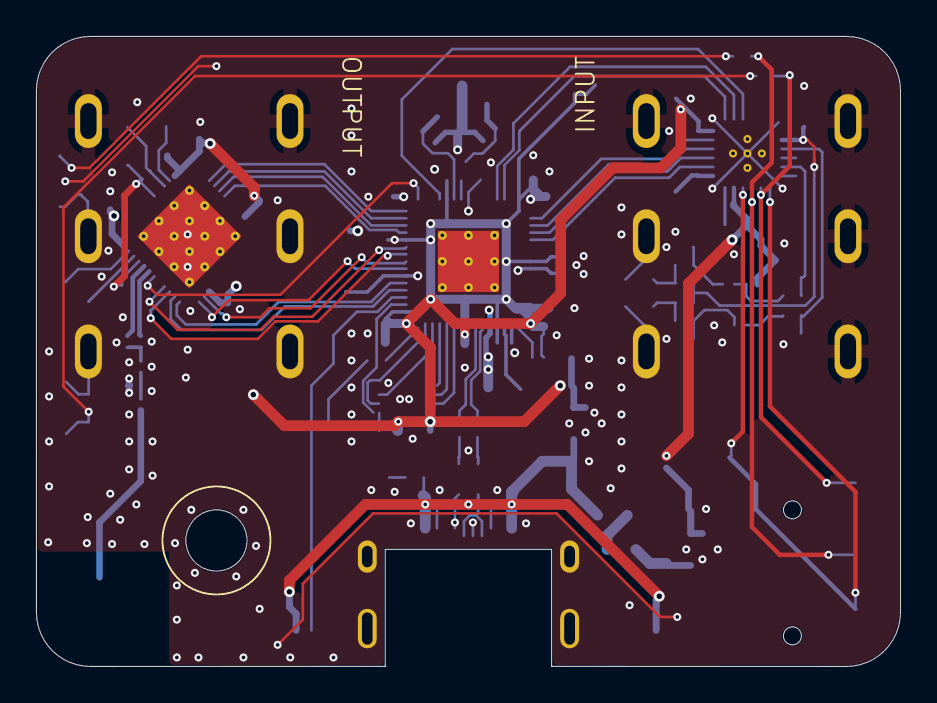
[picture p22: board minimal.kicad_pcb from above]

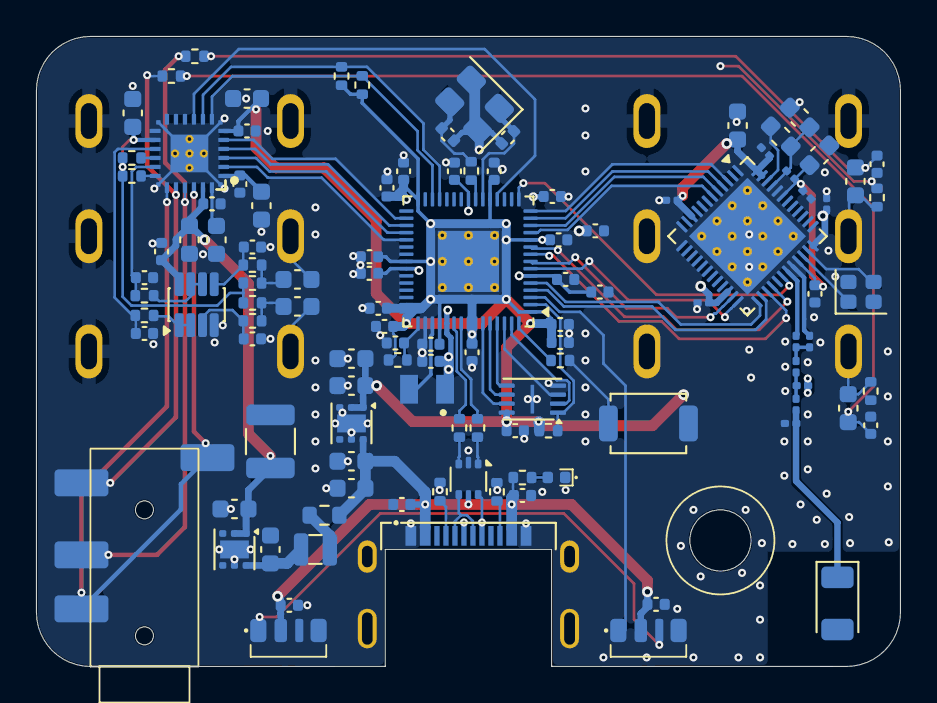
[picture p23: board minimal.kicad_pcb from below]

Board: 4 copper layers, 48.0 x 35.0 mm, 114 parts (112 on the bottom side), 80 nets.

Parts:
AE501: 2.4GHz; Johanson_2450AT18x100
C102, C103, C107, C108, C301, C320, C322, C323, C404, C405, C407, C408, C409, C410, C411, C412, C413, C415, C417: 0.1uF; C_0402_1005Metric
C104, C106, C109, C110, C111, C112, C303, C304, C305, C309, C318, C319, C509, C510: 2.2uF; C_0603_1608Metric
C105: 22uF; C_1210_3225Metric
C302, C308, C310, C311, C511: 2.2nF; C_0402_1005Metric
C306, C307: 150pF; C_0402_1005Metric
C316, C317, C321, C508: 10uF; C_0603_1608Metric
C401, C402, C403, C406, C414, C416, C418, C421, C422: 4.7uF; C_0402_1005Metric
C419, C420: 15pF; C_0402_1005Metric
C501: 1.5pF; C_0201_0603Metric
C502: 2.0pF; C_0201_0603Metric
C503: 0.3pF; C_0201_0603Metric
C504, C505, C506, C507: 0.1uF; C_0201_0603Metric
C512: 10nF; C_0201_0603Metric
D101: LED; LED_0402_1005Metric
D102, D103: WS2812B-4020-V6
FB501: 120Ω; L_0201_0603Metric
J101: USB_C_Receptacle_USB2.0_16P; TYPE-C-16P-CB1.6
J301, J302: AudioJack3_SwitchTR; NRJ6HM-1-PRE
J303: AudioJack4; PJ-320D
L101: 2.2uH; L_0806
L401: 3.3uH; AOTA-B2016
L501: 4.7uH; L_0603_1608Metric
L502: 2.7nH; L_0201_0603Metric
L503, L504: 3.5nH; L_0201_0603Metric
R101, R102, R105, R106: 5k1; R_0402_1005Metric
R103, R401, R403: 2.2kΩ; R_0402_1005Metric
R104: 1R; R_0603_1608Metric
R301, R307: 1k; R_0402_1005Metric
R302, R303, R304, R308: 1MEG; R_0402_1005Metric
R305, R306, R309, R310, R312, R313: 100R; R_0402_1005Metric
R402, R404, R405: 33Ω; R_0402_1005Metric
R406: 1kΩ; R_0402_1005Metric
SW101: SW_SPST; SW_SPST_TS-1088-xR020
U102: USBLC6-2P6; SOT-666
U103, U104: TLV76733DRVx; WSON-6-1EP_2x2mm_P0.65mm_EP1x1.6mm
U301: OPA2323; TSOT-23-8
U302: TAC5112; TAC5242
U401: APS6404L-3SQRx-ZR; Winbond_USON-8-1EP_3x2mm_P0.5mm_EP0.2x1.6mm
U402: RP2354A; QFN-60-1EP_7x7mm_P0.4mm_EP3.4x3.4mm_ThermalVias
U501: NRF54L10-QFAA-R7; QFN-48-1EP_6x6mm_P0.4mm_EP4.6x4.6mm_ThermalVias
Y401: ABM8-272-T3; Crystal_SMD_3225-4Pin_3.2x2.5mm
Y501: 32MHz; Crystal_SMD_2016-4Pin_2.0x1.6mm

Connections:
+1V1: C402.1, C403.1, C405.1, C407.1, C408.1, L401.1, U402.6 (DVDD), U402.23 (DVDD), U402.39 (DVDD), U402.50 (VREG_FB)
+3.3VA: C105.1, C109.1, C301.2, C321.1, C323.1, U103.1 (OUT), U103.2 (SNS), U301.8 (V+), U302.23 (AVDD)
+3V3: C111.1, C112.1, C316.1, C322.1, C401.1, C404.1, C409.1, C410.1, C411.1, C412.1, C413.1, C414.1, C415.1, C416.1, C417.1, C418.1, C421.1, C422.1, C504.1, C505.1, C506.1, C507.1, C508.1, R105.1, R106.1, R401.2, R402.1, U104.1 (OUT), U104.2 (SNS), U302.6 (IOVDD), U401.8 (VDD), U402.1 (IOVDD), U402.11 (IOVDD), U402.20 (IOVDD), U402.30 (IOVDD), U402.38 (IOVDD), U402.44 (ADC_AVDD), U402.45 (IOVDD), U402.49 (VREG_VIN), U402.53 (USB_OTP_VDD), U402.54 (QSPI_IOVDD), U501.10 (VDD), U501.22 (VDD), U501.36 (VDD), U501.47 (VDD), U501.48 (VDD)
/BOOTSEL: R403.1, SW101.2 (B)
/OUT1P: J303.T, R301.1, U302.20 (OUT1P)
/OUT2P: J303.R1, R307.1, U302.21 (OUT2P)
/RP2354/GPIO0: R401.1, U401.1 (~CE), U402.2 (GPIO0)
/RP2354/GPIO1: D102.1 (DIN), U402.3 (GPIO1)
/RP2354/GPIO2: U402.4 (GPIO2), U501.26 (SWDCLK)
/RP2354/GPIO3: U402.5 (GPIO3), U501.25 (SWDIO)
/RP2354/GPIO4: U402.7 (GPIO4), U501.24 (P0.01)
/RP2354/GPIO5: U402.8 (GPIO5), U501.23 (P0.00)
/RP2354/GPIO6: U402.9 (GPIO6), U501.27 (P0.02)
/RP2354/GPIO7: U402.10 (GPIO7), U501.28 (P0.03)
/RP2354/GPIO8: U402.12 (GPIO8), U501.6 (P1.05/AIN1)
/RP2354/GPIO9: U402.13 (GPIO9), U501.5 (P1.04/AIN0)
/RP2354/GPIO10: U402.14 (GPIO10), U501.4 (P1.03/NFC2/CK)
/RP2354/GPIO11: U402.15 (GPIO11), U501.3 (P1.02/NFC1)
/RP2354/GPIO12: U402.16 (GPIO12), U501.30 (nRESET)
/RP2354/GPIO15: U302.9 (GPIO1), U402.19 (GPIO15)
/RP2354/GPIO16: R106.2, U302.8 (SDA), U402.27 (GPIO16)
/RP2354/GPIO17: R105.2, U302.7 (SCL), U402.28 (GPIO17)
/RP2354/GPIO20: U302.5 (DIN), U402.32 (GPIO20)
/RP2354/GPIO21: U302.4 (DOUT), U402.33 (GPIO21)
/RP2354/GPIO22: U302.3 (FSYNC), U402.34 (GPIO22)
/RP2354/GPIO23: U302.2 (BCLK), U402.35 (GPIO23)
/RP2354/SCLK: U401.6 (SCLK), U402.56 (QSPI_SCLK)
/RP2354/SD0: U401.5 (SI/SIO0), U402.57 (QSPI_SD0)
/RP2354/SD1: U401.2 (SO/SIO1), U402.59 (QSPI_SD1)
/RP2354/SD2: U401.3 (SIO2), U402.58 (QSPI_SD2)
/RP2354/SD3: U401.7 (SIO3), U402.55 (QSPI_SD3)
/RP2354/VREG_AVDD: C406.1, R402.2, U402.46 (VREG_AVDD)
/RP2354/VREG_LX: L401.2, U402.48 (VREG_LX)
/RP2354/XIN: C419.1, U402.21 (XIN), Y401.1
/RP2354/XOUT: R406.1, U402.22 (XOUT)
/TAC5212/DREG: C317.1, C320.1, U302.1 (DREG)
/TAC5212/IN1M: R313.2, U302.16 (IN1M)
/TAC5212/IN1P: C310.2, R309.2, U302.15 (IN1P)
/TAC5212/IN2M: R312.2, U302.18 (IN2M)
/TAC5212/IN2P: C311.2, R310.2, U302.17 (IN2P)
/TAC5212/IN^{LEFT}: C303.1, J301.T
/TAC5212/IN^{RIGHT}: C304.1, J301.R
/TAC5212/MICBIAS: C319.1, R303.1, R304.2, R312.1, R313.1, U302.14 (MICBIAS)
/TAC5212/OUT1M: J303.R2, J303.S, U302.19 (OUT1M), U302.22 (OUT2M)
/TAC5212/OUT^{LEFT}: C305.2, J302.T, R302.1
/TAC5212/OUT^{RIGHT}: C309.2, J302.R, R308.1
/TAC5212/VREF: C318.1, U302.24 (VREF)
/USB-D+: R404.2, U102.1 (I/O1)
/USB-D-: R405.2, U102.3 (I/O2)
/USBCONN-D+: J101.A6 (D+), J101.B6 (D+), U102.6 (I/O1)
/USBCONN-D-: J101.A7 (D-), J101.B7 (D-), U102.4 (I/O2)
/nRF54L10/DECA: C510.1, C511.1, C512.1, FB501.2, U501.33 (DECRF), U501.43 (DECA)
/nRF54L10/DECD: C509.1, FB501.1, L501.1, U501.45 (DECD)
GND: C102.1, C103.1, C104.2, C105.2, C106.2, C107.1, C108.1, C109.2, C110.2, C111.2, C112.2, C301.1, C302.1, C306.2, C307.2, C308.1, C310.1, C311.1, C316.2, C317.2, C318.2, C319.2, C320.2, C321.2, C322.2, C323.2, C401.2, C402.2, C403.2, C404.2, C405.2, C406.2, C407.2, C408.2, C409.2, C410.2, C411.2, C412.2, C413.2, C414.2, C415.2, C416.2, C417.2, C418.2, C419.2, C420.2, C421.2, C422.2, C501.2, C502.2, C503.2, C504.2, C505.2, C506.2, C507.2, C508.2, C509.2, C510.2, C511.2, C512.2, D101.1 (K), D102.4 (VSS), D103.4 (VSS), J101.A1 (GND), J101.A12 (GND), J101.B1 (GND), J101.B12 (GND), J101.SH (SHIELD), J301.RN, J301.S, J301.TN, J302.S, R101.2, R102.2, R302.2, R308.2, SW101.1 (A), U102.2 (GND), U103.3 (GND), U103.5 (GND), U103.7 (PAD), U104.3 (GND), U104.5 (GND), U104.7 (PAD), U301.4 (V-), U302.13 (ADDR), U302.A1 (GND), U302.A2 (GND), U302.A3 (GND), U302.A4 (GND), U302.PAD (GND), U401.4 (VSS), U401.9 (EPAD), U402.47 (VREG_PGND), U402.61 (GND), U501.32 (VSS_PA), U501.44 (VSS), U501.49 (VSS/PAD), Y401.2 (G), Y401.4 (G), Y501.2 (G), Y501.4 (G)
unnamed: AE501.1 (FEED_1), C503.1, L504.1
unnamed: C302.2, C305.1, R301.2
unnamed: C303.2, R303.2, R305.1
unnamed: C304.2, R304.1, R306.1
unnamed: C308.2, C309.1, R307.2
unnamed: C420.1, R406.2, Y401.3
unnamed: C501.1, L502.1, L503.2
unnamed: C502.1, L503.1, L504.2
unnamed: D101.2 (A), R103.1
unnamed: D102.3 (DOUT), D103.1 (DIN)
unnamed: J101.A5 (CC1), R101.1
unnamed: J101.B5 (CC2), R102.1
unnamed: L101.1, R104.2
unnamed: C106.1, L101.2, U103.6 (IN)
unnamed: C306.1, R305.2, U301.3 (+)
unnamed: R309.1, U301.1, U301.2 (-)
unnamed: C307.1, R306.2, U301.5 (+)
unnamed: R310.1, U301.6 (-), U301.7
unnamed: R403.2, U402.60 (QSPI_SS)
unnamed: R405.1, U402.51 (USB_DM)
unnamed: R404.1, U402.52 (USB_DP)
unnamed: L502.2, U501.31 (ANT)
unnamed: L501.2, U501.46 (DCC)
unnamed: U501.34 (XC1), Y501.1
unnamed: U501.35 (XC2), Y501.3
VBUS: C102.2, C103.2, C104.1, C107.2, C108.2, C110.1, D102.2 (VDD), D103.2 (VDD), J101.A4 (VBUS), J101.A9 (VBUS), J101.B4 (VBUS), J101.B9 (VBUS), R103.2, R104.1, U102.5 (VBUS), U104.6 (IN)

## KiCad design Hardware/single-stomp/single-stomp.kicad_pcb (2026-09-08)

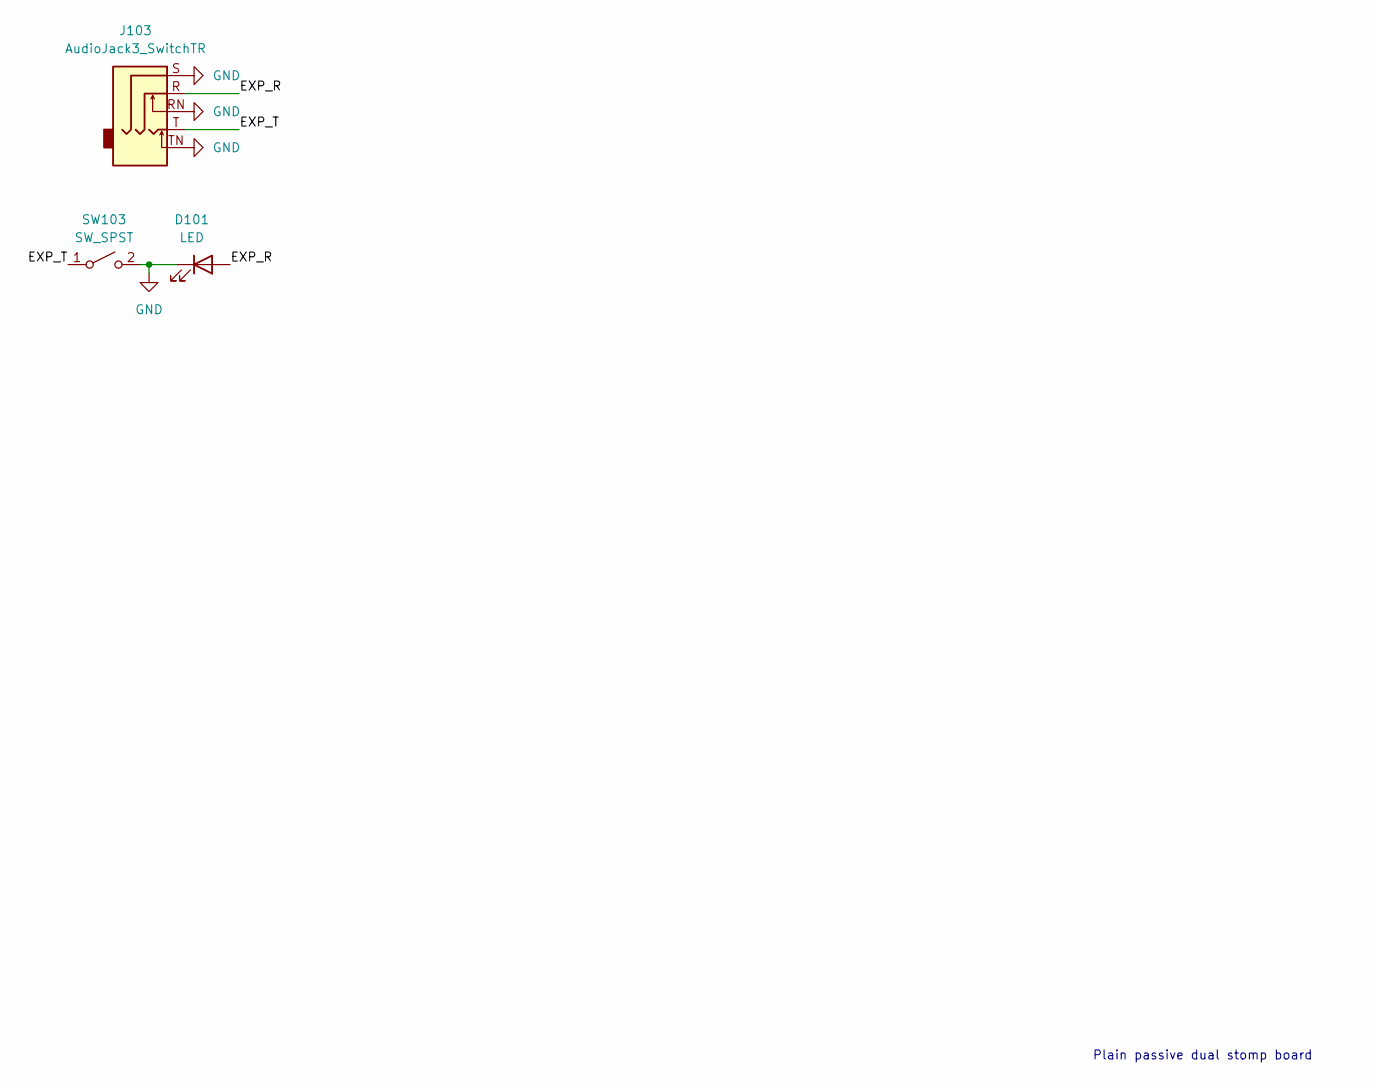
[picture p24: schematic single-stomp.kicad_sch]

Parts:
D101: LED; LED_D5.0mm
J103: AudioJack3_SwitchTR; NRJ6HM-1-PRE
SW103: SW_SPST; Daier PBS-24B-2

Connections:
/EXP_R: D101.2 (A), J103.R
/EXP_T: J103.T, SW103.1 (A)
GND: D101.1 (K), J103.RN, J103.S, J103.TN, SW103.2 (B)

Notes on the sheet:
Plain passive dual stomp board

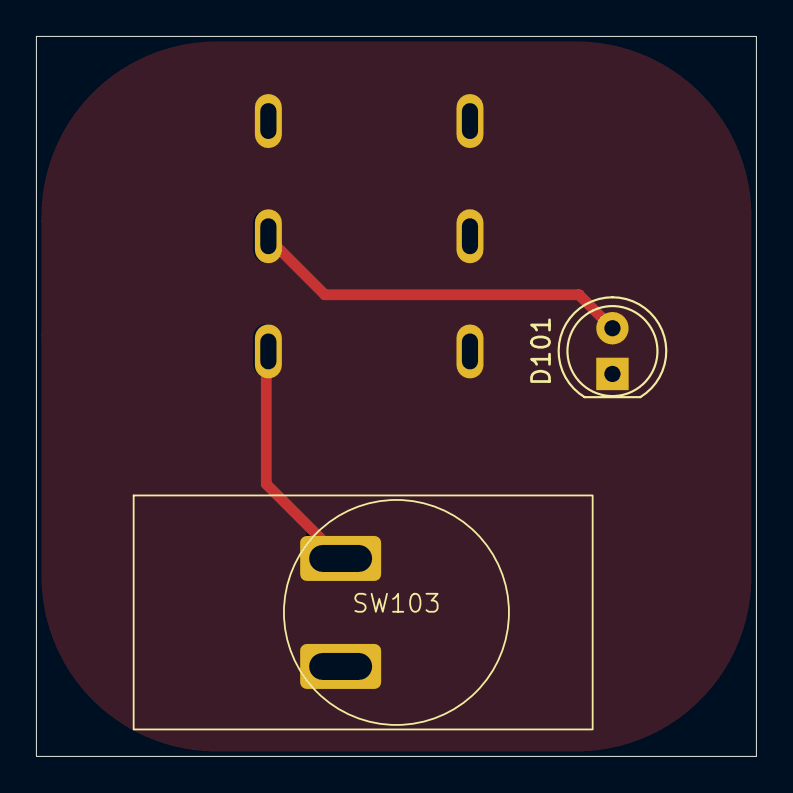
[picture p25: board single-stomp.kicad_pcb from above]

Board: 2 copper layers, 40.0 x 40.0 mm, 3 parts (0 on the bottom side), 3 nets.

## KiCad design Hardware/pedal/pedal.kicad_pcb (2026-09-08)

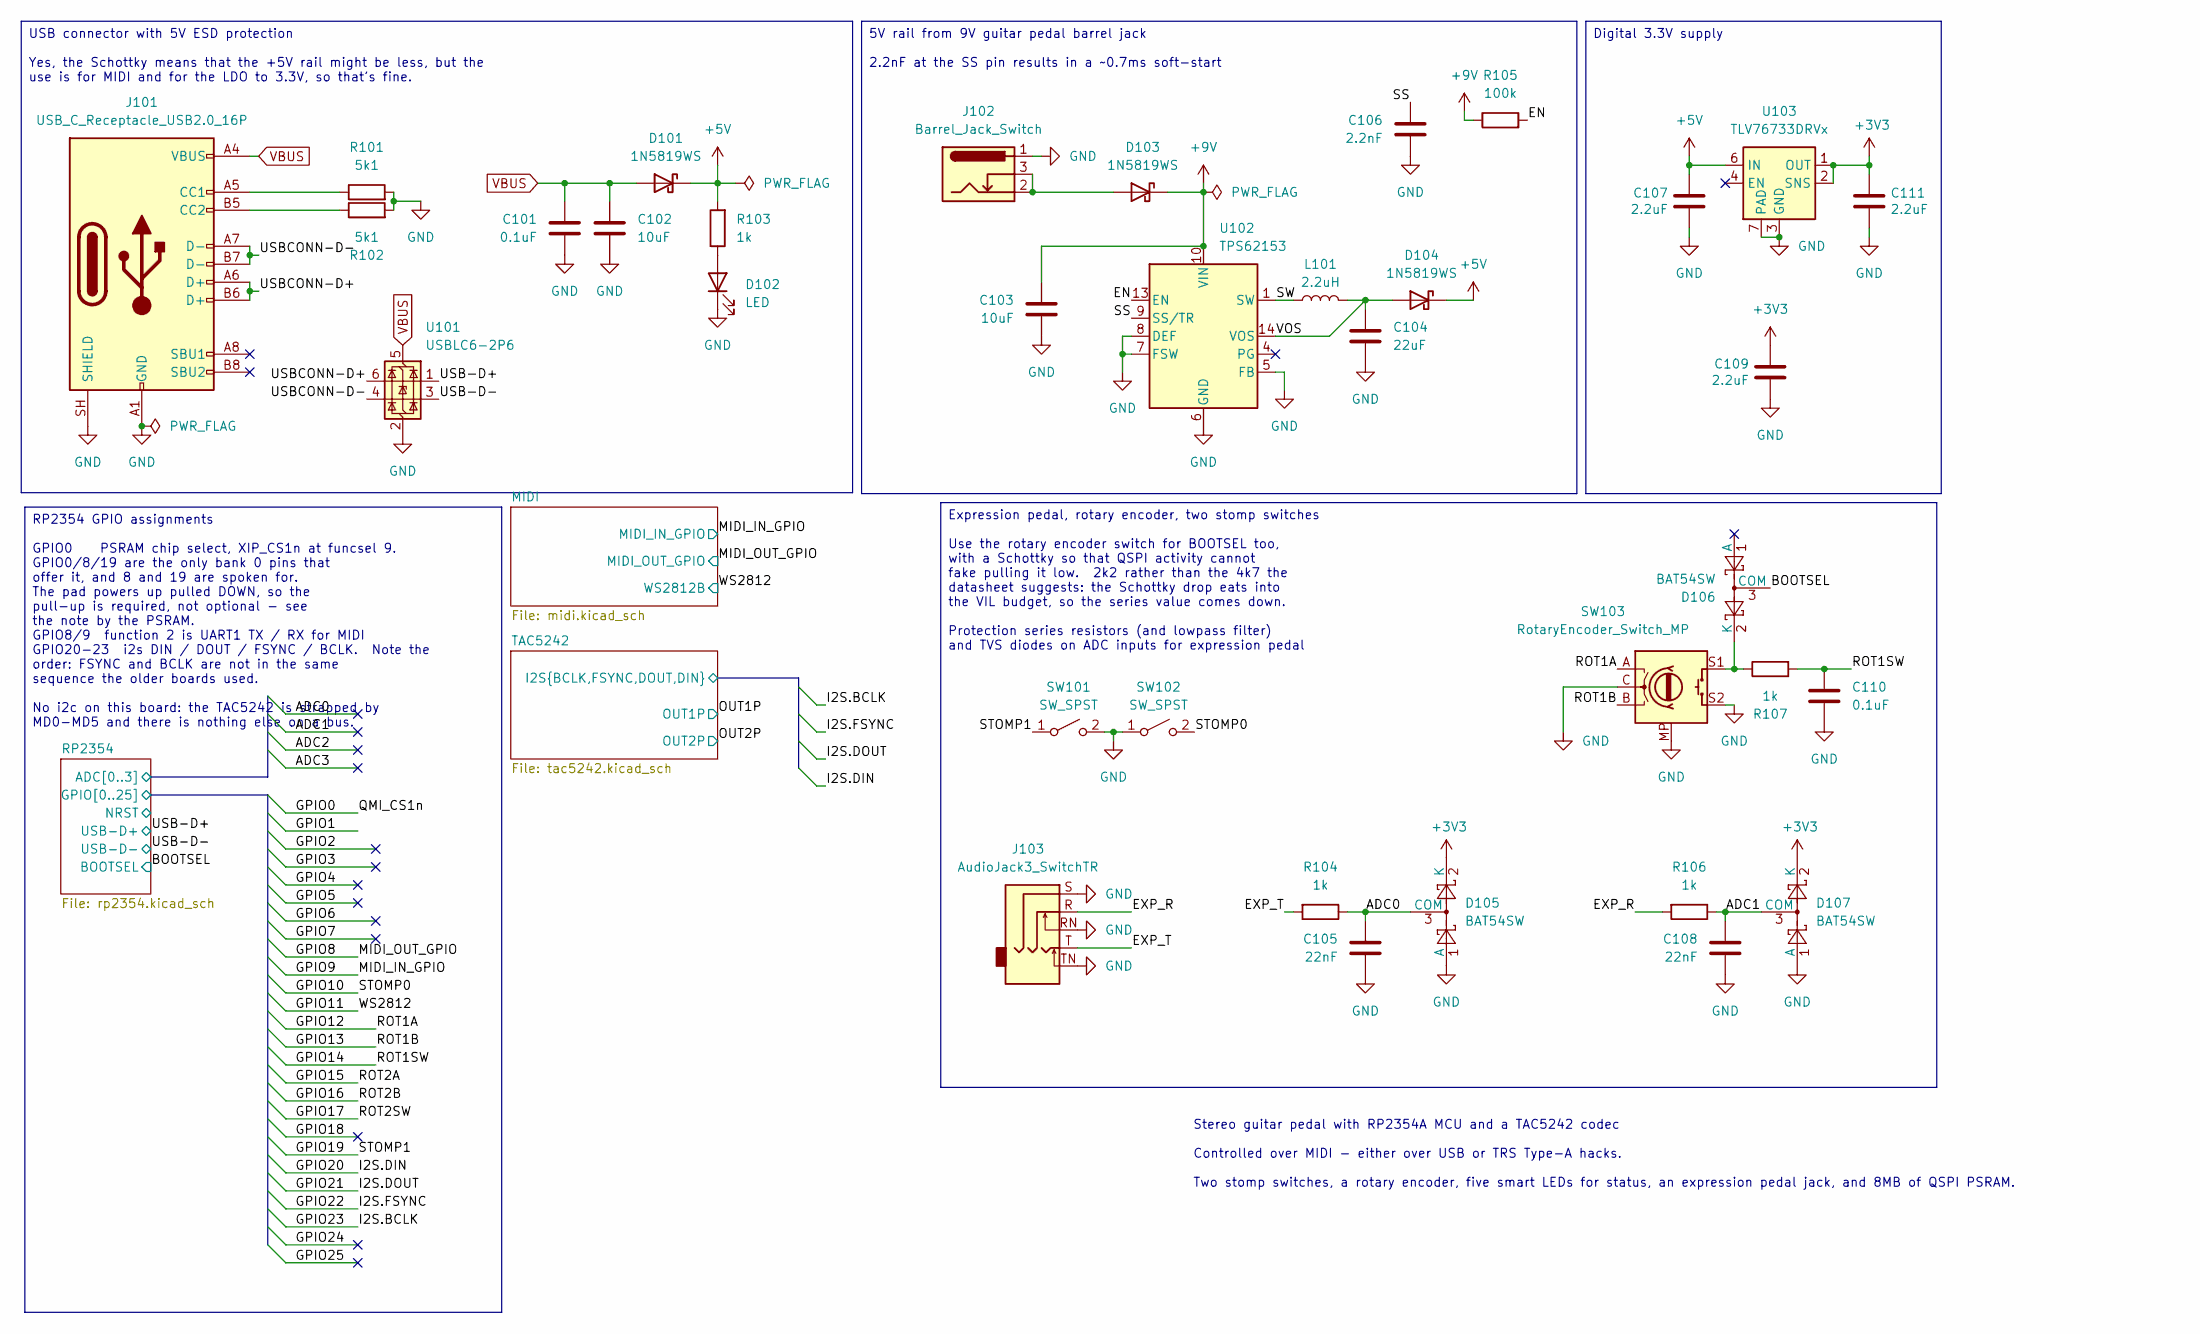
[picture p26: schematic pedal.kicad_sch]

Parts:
C101, C110: 0.1uF; C_0402_1005Metric; MANUFACTURER_PART_NUMBER CL05B104KO5NNNC; LCSC PN C1525
C102, C103: 10uF; C_0603_1608Metric; MANUFACTURER_PART_NUMBER GRM188R61E106MA73D; LCSC PN C91606
C104: 22uF; C_1210_3225Metric; MANUFACTURER_PART_NUMBER CL32B226KAJNNNE; LCSC PN C309062
C105, C108: 22nF; C_0402_1005Metric; MANUFACTURER_PART_NUMBER 0402B223K500NT; LCSC PN C1532
C106: 2.2nF; C_0402_1005Metric; MANUFACTURER_PART_NUMBER GRM1555C1H222GA01D; LCSC PN C2987940
C107, C109, C111: 2.2uF; C_0603_1608Metric; MANUFACTURER_PART_NUMBER GRM188Z71E225KE43D; LCSC PN C415535
D101, D103, D104: 1N5819WS; D_SOD-323; MANUFACTURER_PART_NUMBER 1N5819WS; LCSC PN C191023
D102: LED; LED_0402_1005Metric; MANUFACTURER_PART_NUMBER LTST-C281KGKT; LCSC PN C160479
D105, D106, D107: BAT54SW; SOT-323_SC-70; MANUFACTURER_PART_NUMBER BAT54SW; LCSC PN C22466373
J101: USB_C_Receptacle_USB2.0_16P; USB_C_Receptacle_GCT_USB4105-xx-A_16P_TopMnt_Horizontal; MANUFACTURER_PART_NUMBER GT-USB-7010C; LCSC PN C2843967
J102: Barrel_Jack_Switch; Wurth WR-DC 2.1mm Power Jack
J103: AudioJack3_SwitchTR; NRJ6HM-1-PRE
L101: 2.2uH; L_0806; MANUFACTURER_PART_NUMBER DFE201612E-2R2M=P2; LCSC PN C337893
R101, R102: 5k1; R_0402_1005Metric; MANUFACTURER_PART_NUMBER 0402WGF5101TCE; LCSC PN C25905
R103, R104, R106, R107: 1k; R_0402_1005Metric; MANUFACTURER_PART_NUMBER RT0402FRE071KL; LCSC PN C136974
R105: 100k; R_0402_1005Metric; MANUFACTURER_PART_NUMBER 0402WGF1003TCE; LCSC PN C25741
SW101, SW102: SW_SPST; Daier PBS-24B-2
SW103: RotaryEncoder_Switch_MP; RotaryEncoder_EC11-Switch_Vertical_H20mm
U101: USBLC6-2P6; SOT-666; MANUFACTURER_PART_NUMBER USBLC6-2P6; LCSC PN C15999
U102: TPS62153; VQFN-16-1EP_3x3mm_P0.5mm_EP1.68x1.68mm_ThermalVias; MANUFACTURER_PART_NUMBER TPS62153RGTR; LCSC PN C477927
U103: TLV76733DRVx; WSON-6-1EP_2x2mm_P0.65mm_EP1x1.6mm; MANUFACTURER_PART_NUMBER TLV76733DRVR; LCSC PN C2848334

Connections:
+3V3: C109.1, C111.1, D105.2 (K), D107.2 (K), U103.1 (OUT), U103.2 (SNS); also elsewhere on the board
+5V: C107.1, D101.1 (K), D104.1 (K), R103.2, U103.6 (IN); also elsewhere on the board
+9V: C103.1, D103.1 (K), R105.1, U102.10 (VIN), U102.11 (VIN), U102.12 (VIN)
/BOOTSEL: D106.3 (COM); also elsewhere on the board
/EN: R105.2, U102.13 (EN)
/EXP_R: J103.R, R106.2
/EXP_T: J103.T, R104.2
/RP2354/ADC0: C105.1, D105.3 (COM), R104.1; also elsewhere on the board
/RP2354/ADC1: C108.1, D107.3 (COM), R106.1; also elsewhere on the board
/RP2354/GPIO10: SW102.2 (B); also elsewhere on the board
/RP2354/GPIO12: SW103.A; also elsewhere on the board
/RP2354/GPIO13: SW103.B; also elsewhere on the board
/RP2354/GPIO14: C110.2, R107.2; also elsewhere on the board
/RP2354/GPIO19: SW101.1 (A); also elsewhere on the board
/SS: C106.2, U102.9 (SS/TR)
/SW: L101.1, U102.1 (SW), U102.2 (SW), U102.3 (SW)
/USB-D+: U101.1 (I/O1); also elsewhere on the board
/USB-D-: U101.3 (I/O2); also elsewhere on the board
/USBCONN-D+: J101.A6 (D+), J101.B6 (D+), U101.6 (I/O1)
/USBCONN-D-: J101.A7 (D-), J101.B7 (D-), U101.4 (I/O2)
/VOS: C104.1, D104.2 (A), L101.2, U102.14 (VOS)
GND: C101.1, C102.2, C103.2, C104.2, C105.2, C106.1, C107.2, C108.2, C109.2, C110.1, C111.2, D102.1 (K), D105.1 (A), D107.1 (A), J101.A1 (GND), J101.A12 (GND), J101.B1 (GND), J101.B12 (GND), J101.SH (SHIELD), J102.1, J103.RN, J103.S, J103.TN, R101.2, R102.2, SW101.2 (B), SW102.1 (A), SW103.C, SW103.MP, SW103.S2, U101.2 (GND), U102.5 (FB), U102.6 (GND), U102.7 (FSW), U102.8 (DEF), U102.15 (GND), U102.16 (GND), U102.17 (GND), U103.3 (GND), U103.5 (GND), U103.7 (PAD); also elsewhere on the board
unnamed: D102.2 (A), R103.1
unnamed: D103.2 (A), J102.2, J102.3
unnamed: D106.2 (K), R107.1, SW103.S1
unnamed: J101.A5 (CC1), R101.1
unnamed: J101.B5 (CC2), R102.1
VBUS: C101.2, C102.1, D101.2 (A), J101.A4 (VBUS), J101.A9 (VBUS), J101.B4 (VBUS), J101.B9 (VBUS), U101.5 (VBUS)

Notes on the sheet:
Stereo guitar pedal with RP2354A MCU and a TAC5242 codec Controlled over MIDI - either over USB or TRS Type-A hacks. Two stomp switches, a rotary encoder, five smart LEDs for status, an expression pedal jack, and 8MB of QSPI PSRAM.
Expression pedal, rotary encoder, two stomp switches Use the rotary encoder switch for BOOTSEL too, with a Schottky so that QSPI activity cannot fake pulling it low. 2k2 rather than the 4k7 the datasheet suggests: the Schottky drop eats into the VIL budget, so the series value comes down. Protectio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
5V rail from 9V guitar pedal barrel jack 2.2nF at the SS pin results in a ~0.7ms soft-start
RP2354 GPIO assignments GPIO0 PSRAM chip select, XIP_CS1n at funcsel 9. GPIO0/8/19 are the only bank 0 pins that offer it, and 8 and 19 are spoken for. The pad powers up pulled DOWN, so the pull-up is required, not optional - see the note by the PSRAM. GPIO8/9 function 2 is UART1 TX / RX for MIDI G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
Digital 3.3V supply
USB connector with 5V ESD protection Yes, the Schottky means that the +5V rail might be less, but the use is for MIDI and for the LDO to 3.3V, so that's fine.

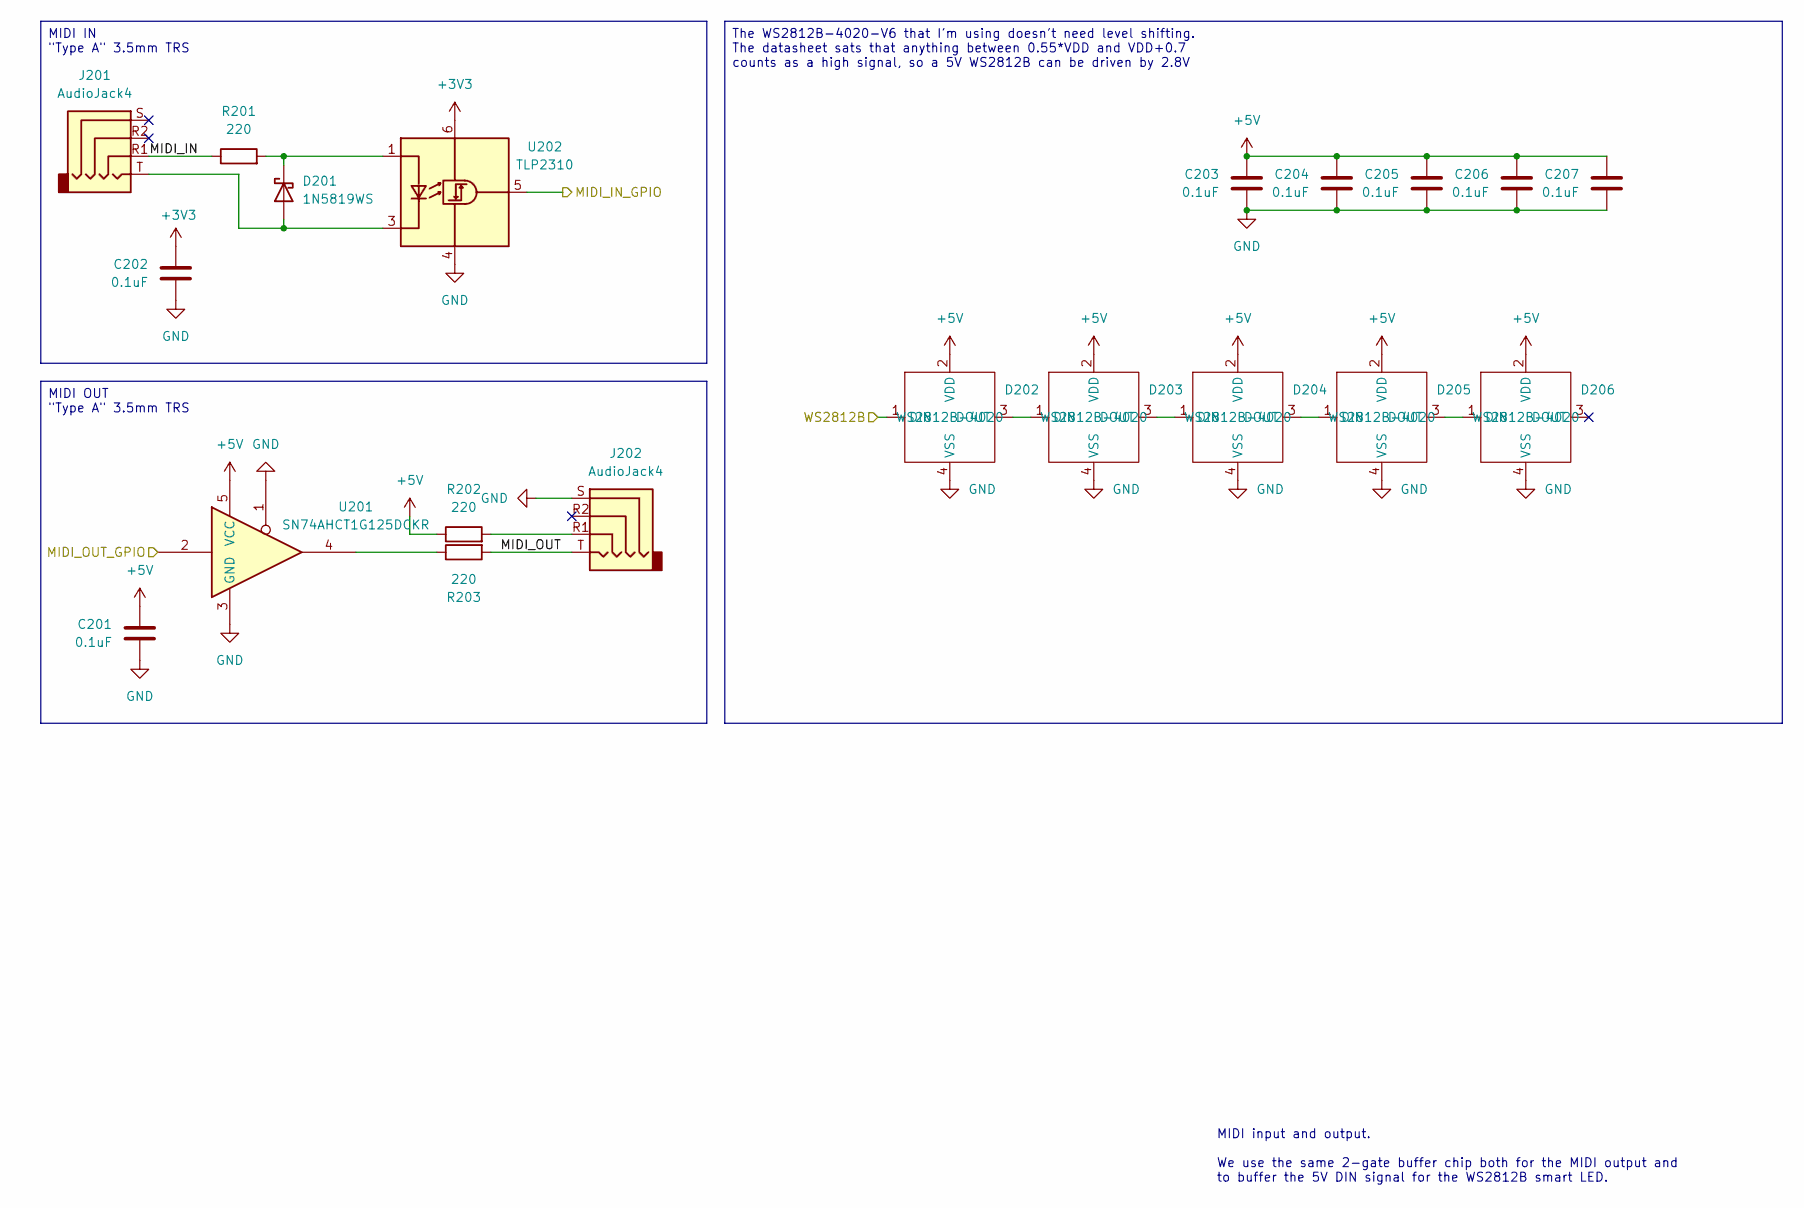
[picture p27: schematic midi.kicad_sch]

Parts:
C201, C202, C203, C204, C205, C206, C207: 0.1uF; C_0402_1005Metric; MANUFACTURER_PART_NUMBER CL05B104KO5NNNC; LCSC PN C1525
D201: 1N5819WS; D_SOD-323; MANUFACTURER_PART_NUMBER 1N5819WS; LCSC PN C191023
D202, D203, D204, D205, D206: WS2812B-4020; MANUFACTURER_PART_NUMBER WS2812B-4020; LCSC PN C965557
J201, J202: AudioJack4; PJ-320D; MANUFACTURER_PART_NUMBER PJ-320D; LCSC PN C431535
R201, R202, R203: 220; R_0402_1005Metric; MANUFACTURER_PART_NUMBER 0402WGF2200TCE; LCSC PN C25091
U201: SN74AHCT1G125DCKR; SOT-353_SC-70-5; MANUFACTURER_PART_NUMBER SN74AHCT1G125DCKR; LCSC PN C350557
U202: TLP2310; SO-5-6_4.55x3.7mm_P1.27mm; MANUFACTURER_PART_NUMBER TLP2310; LCSC PN C7473281

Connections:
+3V3: C202.2, U202.6 (VDD); also elsewhere on the board
+5V: C201.2, C203.2, C204.2, C205.2, C206.2, C207.2, D202.2 (VDD), D203.2 (VDD), D204.2 (VDD), D205.2 (VDD), D206.2 (VDD), R202.1, U201.5 (VCC); also elsewhere on the board
/MIDI/MIDI_IN: J201.R1, R201.1
/MIDI/MIDI_OUT: J202.T, R203.2
/RP2354/GPIO8: U201.2; also elsewhere on the board
/RP2354/GPIO9: U202.5 (VO); also elsewhere on the board
/RP2354/GPIO11: D202.1 (DIN); also elsewhere on the board
GND: C201.1, C202.1, C203.1, C204.1, C205.1, C206.1, C207.1, D202.4 (VSS), D203.4 (VSS), D204.4 (VSS), D205.4 (VSS), D206.4 (VSS), J202.S, U201.1, U201.3 (GND), U202.4 (GND); also elsewhere on the board
unnamed: D201.2 (A), J201.T, U202.3 (K)
unnamed: D201.1 (K), R201.2, U202.1 (A)
unnamed: D202.3 (DOUT), D203.1 (DIN)
unnamed: D203.3 (DOUT), D204.1 (DIN)
unnamed: D204.3 (DOUT), D205.1 (DIN)
unnamed: D205.3 (DOUT), D206.1 (DIN)
unnamed: J202.R1, R202.2
unnamed: R203.1, U201.4

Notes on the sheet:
MIDI input and output. We use the same 2-gate buffer chip both for the MIDI output and to buffer the 5V DIN signal for the WS2812B smart LED.
MIDI IN "Type A" 3.5mm TRS
MIDI OUT "Type A" 3.5mm TRS
The WS2812B-4020-V6 that I'm using doesn't need level shifting. The datasheet sats that anything between 0.55*VDD and VDD+0.7 counts as a high signal, so a 5V WS2812B can be driven by 2.8V

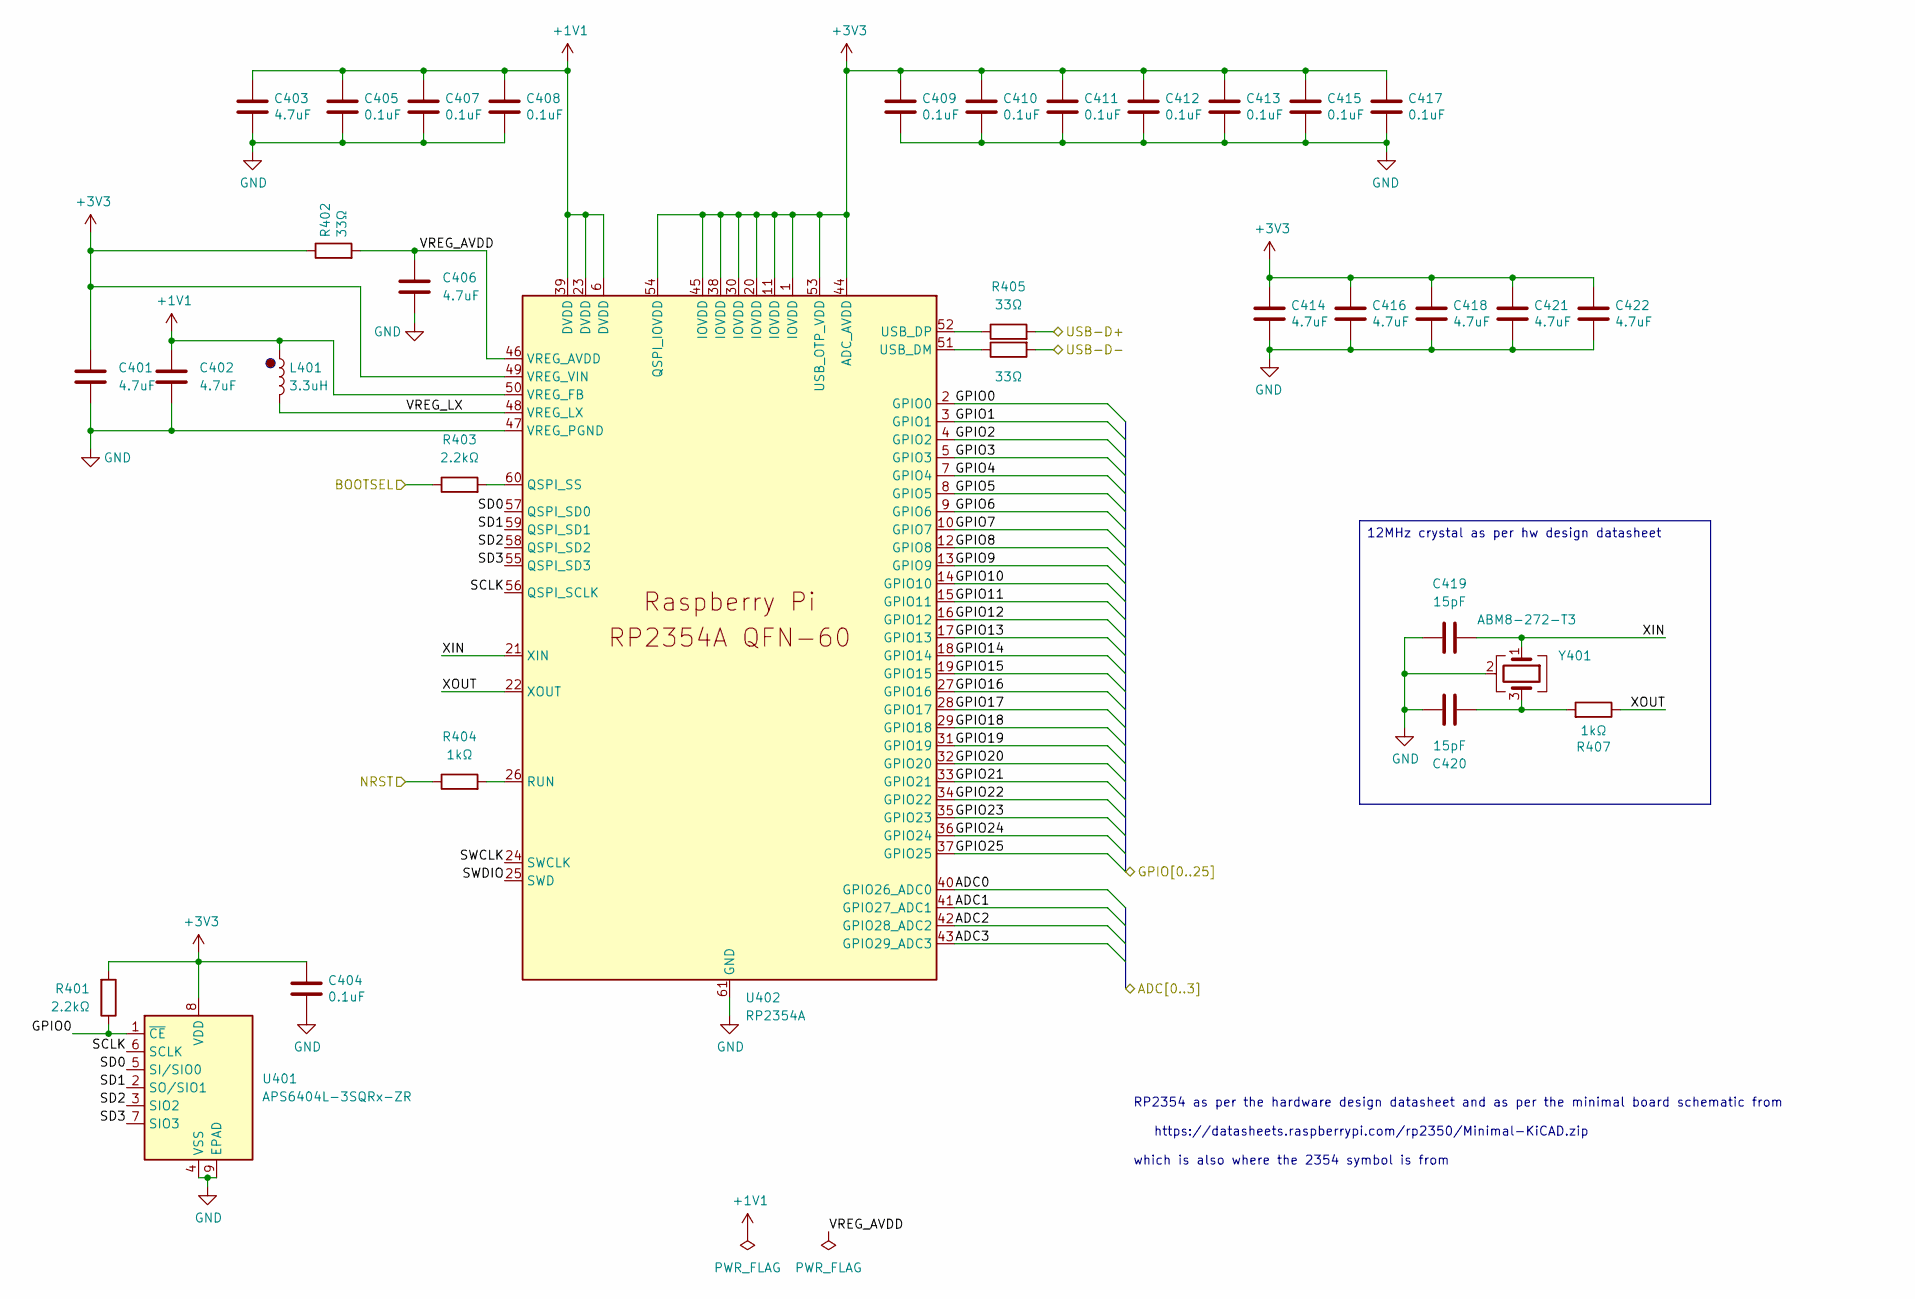
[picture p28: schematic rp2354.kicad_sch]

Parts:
C401, C402, C403, C406, C414, C416, C418, C421, C422: 4.7uF; C_0402_1005Metric; MANUFACTURER_PART_NUMBER GRM155R61E475ME15D; LCSC PN C2858031
C404, C405, C407, C408, C409, C410, C411, C412, C413, C415, C417: 0.1uF; C_0402_1005Metric; MANUFACTURER_PART_NUMBER CL05B104KO5NNNC; LCSC PN C1525
C419, C420: 15pF; C_0402_1005Metric; MANUFACTURER_PART_NUMBER GRM1555C1H150JA01D; LCSC PN C76950
L401: 3.3uH; AOTA-B2016; MANUFACTURER_PART_NUMBER AOTA-B201610S3R3-101-T; LCSC PN C42411119
R401, R403: 2.2kΩ; R_0402_1005Metric; MANUFACTURER_PART_NUMBER 0402WGF2201TCE; LCSC PN C25879
R402, R405, R406: 33Ω; R_0402_1005Metric; MANUFACTURER_PART_NUMBER 0402WGF330JTCE; LCSC PN C25105
R404, R407: 1kΩ; R_0402_1005Metric; MANUFACTURER_PART_NUMBER 0402WGF1001TCE; LCSC PN C11702
U401: APS6404L-3SQRx-ZR; Winbond_USON-8-1EP_3x2mm_P0.5mm_EP0.2x1.6mm; MANUFACTURER_PART_NUMBER APS6404L-3SQR-ZR; LCSC PN C3040877
U402: RP2354A; QFN-60-1EP_7x7mm_P0.4mm_EP3.4x3.4mm_ThermalVias; MANUFACTURER_PART_NUMBER RP2354A; LCSC PN C41378174
Y401: ABM8-272-T3; Crystal_SMD_3225-4Pin_3.2x2.5mm; MANUFACTURER_PART_NUMBER ABM8-272-T3; LCSC PN C20625731

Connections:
+1V1: C402.1, C403.1, C405.1, C407.1, C408.1, L401.1, U402.6 (DVDD), U402.23 (DVDD), U402.39 (DVDD), U402.50 (VREG_FB)
+3V3: C401.1, C404.1, C409.1, C410.1, C411.1, C412.1, C413.1, C414.1, C415.1, C416.1, C417.1, C418.1, C421.1, C422.1, R401.2, R402.1, U401.8 (VDD), U402.1 (IOVDD), U402.11 (IOVDD), U402.20 (IOVDD), U402.30 (IOVDD), U402.38 (IOVDD), U402.44 (ADC_AVDD), U402.45 (IOVDD), U402.49 (VREG_VIN), U402.53 (USB_OTP_VDD), U402.54 (QSPI_IOVDD); also elsewhere on the board
/BOOTSEL: R403.1; also elsewhere on the board
/RP2354/ADC0: U402.40 (GPIO26_ADC0); also elsewhere on the board
/RP2354/ADC1: U402.41 (GPIO27_ADC1); also elsewhere on the board
/RP2354/ADC2: U402.42 (GPIO28_ADC2)
/RP2354/ADC3: U402.43 (GPIO29_ADC3)
/RP2354/GPIO0: R401.1, U401.1 (~CE), U402.2 (GPIO0)
/RP2354/GPIO1: U402.3 (GPIO1)
/RP2354/GPIO2: U402.4 (GPIO2)
/RP2354/GPIO3: U402.5 (GPIO3)
/RP2354/GPIO4: U402.7 (GPIO4)
/RP2354/GPIO5: U402.8 (GPIO5)
/RP2354/GPIO6: U402.9 (GPIO6)
/RP2354/GPIO7: U402.10 (GPIO7)
/RP2354/GPIO8: U402.12 (GPIO8); also elsewhere on the board
/RP2354/GPIO9: U402.13 (GPIO9); also elsewhere on the board
/RP2354/GPIO10: U402.14 (GPIO10); also elsewhere on the board
/RP2354/GPIO11: U402.15 (GPIO11); also elsewhere on the board
/RP2354/GPIO12: U402.16 (GPIO12); also elsewhere on the board
/RP2354/GPIO13: U402.17 (GPIO13); also elsewhere on the board
/RP2354/GPIO14: U402.18 (GPIO14); also elsewhere on the board
/RP2354/GPIO15: U402.19 (GPIO15)
/RP2354/GPIO16: U402.27 (GPIO16)
/RP2354/GPIO17: U402.28 (GPIO17)
/RP2354/GPIO18: U402.29 (GPIO18)
/RP2354/GPIO19: U402.31 (GPIO19); also elsewhere on the board
/RP2354/GPIO24: U402.36 (GPIO24)
/RP2354/GPIO25: U402.37 (GPIO25)
/RP2354/NRST: R404.1
/RP2354/SCLK: U401.6 (SCLK), U402.56 (QSPI_SCLK)
/RP2354/SD0: U401.5 (SI/SIO0), U402.57 (QSPI_SD0)
/RP2354/SD1: U401.2 (SO/SIO1), U402.59 (QSPI_SD1)
/RP2354/SD2: U401.3 (SIO2), U402.58 (QSPI_SD2)
/RP2354/SD3: U401.7 (SIO3), U402.55 (QSPI_SD3)
/RP2354/SWCLK: U402.24 (SWCLK)
/RP2354/SWDIO: U402.25 (SWD)
/RP2354/VREG_AVDD: C406.1, R402.2, U402.46 (VREG_AVDD)
/RP2354/VREG_LX: L401.2, U402.48 (VREG_LX)
/RP2354/XIN: C419.1, U402.21 (XIN), Y401.1
/RP2354/XOUT: R407.1, U402.22 (XOUT)
/TAC5242/I2S.BCLK: U402.35 (GPIO23); also elsewhere on the board
/TAC5242/I2S.DIN: U402.32 (GPIO20); also elsewhere on the board
/TAC5242/I2S.DOUT: U402.33 (GPIO21); also elsewhere on the board
/TAC5242/I2S.FSYNC: U402.34 (GPIO22); also elsewhere on the board
/USB-D+: R405.2; also elsewhere on the board
/USB-D-: R406.2; also elsewhere on the board
GND: C401.2, C402.2, C403.2, C404.2, C405.2, C406.2, C407.2, C408.2, C409.2, C410.2, C411.2, C412.2, C413.2, C414.2, C415.2, C416.2, C417.2, C418.2, C419.2, C420.2, C421.2, C422.2, U401.4 (VSS), U401.9 (EPAD), U402.47 (VREG_PGND), U402.61 (GND), Y401.2 (G), Y401.4 (G); also elsewhere on the board
unnamed: C420.1, R407.2, Y401.3
unnamed: R403.2, U402.60 (QSPI_SS)
unnamed: R404.2, U402.26 (RUN)
unnamed: R406.1, U402.51 (USB_DM)
unnamed: R405.1, U402.52 (USB_DP)

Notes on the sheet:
RP2354 as per the hardware design datasheet and as per the minimal board schematic from https://datasheets.raspberrypi.com/rp2350/Minimal-KiCAD.zip which is also where the 2354 symbol is from
12MHz crystal as per hw design datasheet

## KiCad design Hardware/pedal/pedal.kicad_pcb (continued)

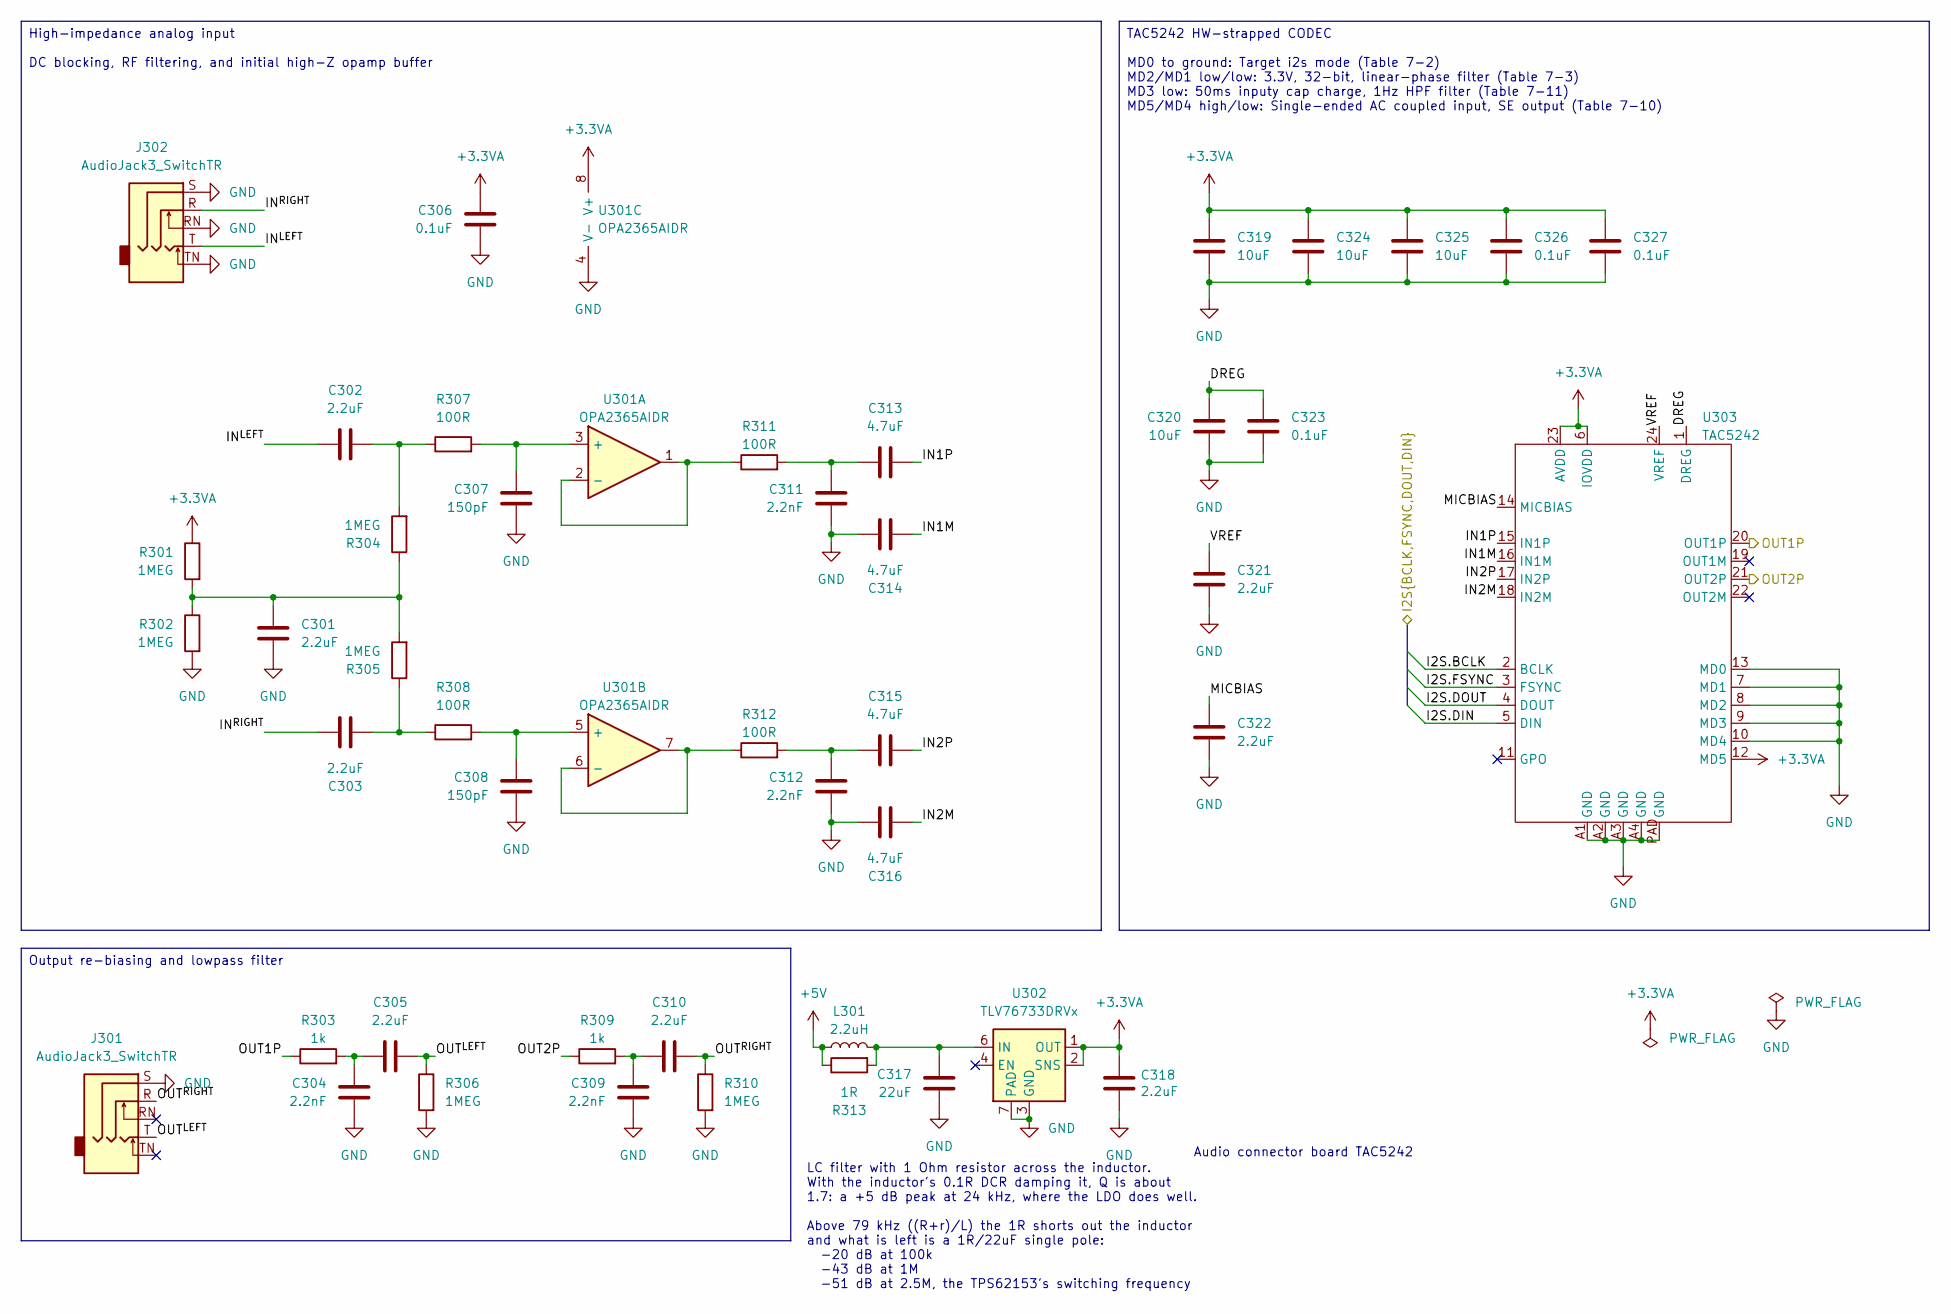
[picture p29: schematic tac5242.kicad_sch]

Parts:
C301, C302, C303, C305, C310, C318, C321, C322: 2.2uF; C_0603_1608Metric; MANUFACTURER_PART_NUMBER GRM188Z71E225KE43D; LCSC PN C415535
C304, C309, C311, C312: 2.2nF; C_0402_1005Metric; MANUFACTURER_PART_NUMBER GRM1555C1H222GA01D; LCSC PN C2987940
C306, C323, C326, C327: 0.1uF; C_0402_1005Metric; MANUFACTURER_PART_NUMBER CL05B104KO5NNNC; LCSC PN C1525
C307, C308: 150pF; C_0402_1005Metric; MANUFACTURER_PART_NUMBER GRM1555C1E151JA01D; LCSC PN C710836
C313, C314, C315, C316: 4.7uF; C_0805_2012Metric; MANUFACTURER_PART_NUMBER GRM21BZ71H475KE15L; LCSC PN C437557
C317: 22uF; C_1210_3225Metric; MANUFACTURER_PART_NUMBER CL32B226KAJNNNE; LCSC PN C309062
C319, C320, C324, C325: 10uF; C_0603_1608Metric; MANUFACTURER_PART_NUMBER GRM188R61E106MA73D; LCSC PN C91606
J301, J302: AudioJack3_SwitchTR; NRJ6HM-1-PRE
L301: 2.2uH; L_0806; MANUFACTURER_PART_NUMBER DFE201612E-2R2M=P2; LCSC PN C337893
R301, R302, R304, R305, R306, R310: 1MEG; R_0402_1005Metric; MANUFACTURER_PART_NUMBER MCS04020C1004FE000; LCSC PN C1884615
R303, R309: 1k; R_0402_1005Metric; MANUFACTURER_PART_NUMBER RT0402FRE071KL; LCSC PN C136974
R307, R308, R311, R312: 100R; R_0402_1005Metric; MANUFACTURER_PART_NUMBER RT0402BRD07100RL; LCSC PN C705627
R313: 1R; R_0402_1005Metric; MANUFACTURER_PART_NUMBER FRC0402F1R00TS; LCSC PN C2909329
U301: OPA2365AIDR; SOIC-8_3.9x4.9mm_P1.27mm; MANUFACTURER_PART_NUMBER OPA2365AIDR; LCSC PN C130011
U302: TLV76733DRVx; WSON-6-1EP_2x2mm_P0.65mm_EP1x1.6mm; MANUFACTURER_PART_NUMBER TLV76733DRVR; LCSC PN C2848334
U303: TAC5242; MANUFACTURER_PART_NUMBER TAC5242IRGER; LCSC PN C47122155

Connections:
+3.3VA: C306.2, C318.1, C319.1, C324.1, C325.1, C326.1, C327.1, R301.1, U301.8 (V+), U302.1 (OUT), U302.2 (SNS), U303.6 (IOVDD), U303.12 (MD5), U303.23 (AVDD)
+5V: L301.1, R313.1; also elsewhere on the board
/OUT1P: R303.1, U303.20 (OUT1P)
/OUT2P: R309.1, U303.21 (OUT2P)
/TAC5242/DREG: C320.1, C323.1, U303.1 (DREG)
/TAC5242/I2S.BCLK: U303.2 (BCLK); also elsewhere on the board
/TAC5242/I2S.DIN: U303.5 (DIN); also elsewhere on the board
/TAC5242/I2S.DOUT: U303.4 (DOUT); also elsewhere on the board
/TAC5242/I2S.FSYNC: U303.3 (FSYNC); also elsewhere on the board
/TAC5242/IN1M: C314.2, U303.16 (IN1M)
/TAC5242/IN1P: C313.2, U303.15 (IN1P)
/TAC5242/IN2M: C316.2, U303.18 (IN2M)
/TAC5242/IN2P: C315.2, U303.17 (IN2P)
/TAC5242/IN^{LEFT}: C302.1, J302.T
/TAC5242/IN^{RIGHT}: C303.1, J302.R
/TAC5242/MICBIAS: C322.1, U303.14 (MICBIAS)
/TAC5242/OUT^{LEFT}: C305.2, J301.T, R306.1
/TAC5242/OUT^{RIGHT}: C310.2, J301.R, R310.1
/TAC5242/VREF: C321.1, U303.24 (VREF)
GND: C301.1, C304.1, C306.1, C307.2, C308.2, C309.1, C311.1, C312.1, C314.1, C316.1, C317.2, C318.2, C319.2, C320.2, C321.2, C322.2, C323.2, C324.2, C325.2, C326.2, C327.2, J301.S, J302.RN, J302.S, J302.TN, R302.2, R306.2, R310.2, U301.4 (V-), U302.3 (GND), U302.5 (GND), U302.7 (PAD), U303.7 (MD1), U303.8 (MD2), U303.9 (MD3), U303.10 (MD4), U303.13 (MD0), U303.A1 (GND), U303.A2 (GND), U303.A3 (GND), U303.A4 (GND), U303.PAD (GND); also elsewhere on the board
unnamed: C301.2, R301.2, R302.1, R304.1, R305.2
unnamed: C302.2, R304.2, R307.1
unnamed: C303.2, R305.1, R308.1
unnamed: C304.2, C305.1, R303.2
unnamed: C309.2, C310.1, R309.2
unnamed: C311.2, C313.1, R311.2
unnamed: C312.2, C315.1, R312.2
unnamed: C307.1, R307.2, U301.3 (+)
unnamed: R311.1, U301.1, U301.2 (-)
unnamed: C308.1, R308.2, U301.5 (+)
unnamed: R312.1, U301.6 (-), U301.7
unnamed: C317.1, L301.2, R313.2, U302.6 (IN)

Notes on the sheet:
LC filter with 1 Ohm resistor across the inductor. With the inductor's 0.1R DCR damping it, Q is about 1.7: a +5 dB peak at 24 kHz, where the LDO does well. Above 79 kHz ((R+r)/L) the 1R shorts out the inductor and what is left is a 1R/22uF single pole: -20 dB at 100k -43 dB at 1M -51 dB at 2.5M, t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
Audio connector board TAC5242
High-impedance analog input DC blocking, RF filtering, and initial high-Z opamp buffer
Output re-biasing and lowpass filter
TAC5242 HW-strapped CODEC MD0 to ground: Target i2s mode (Table 7-2) MD2/MD1 low/low: 3.3V, 32-bit, linear-phase filter (Table 7-3) MD3 low: 50ms inputy cap charge, 1Hz HPF filter (Table 7-11) MD5/MD4 high/low: Single-ended AC coupled input, SE output (Table 7-10)

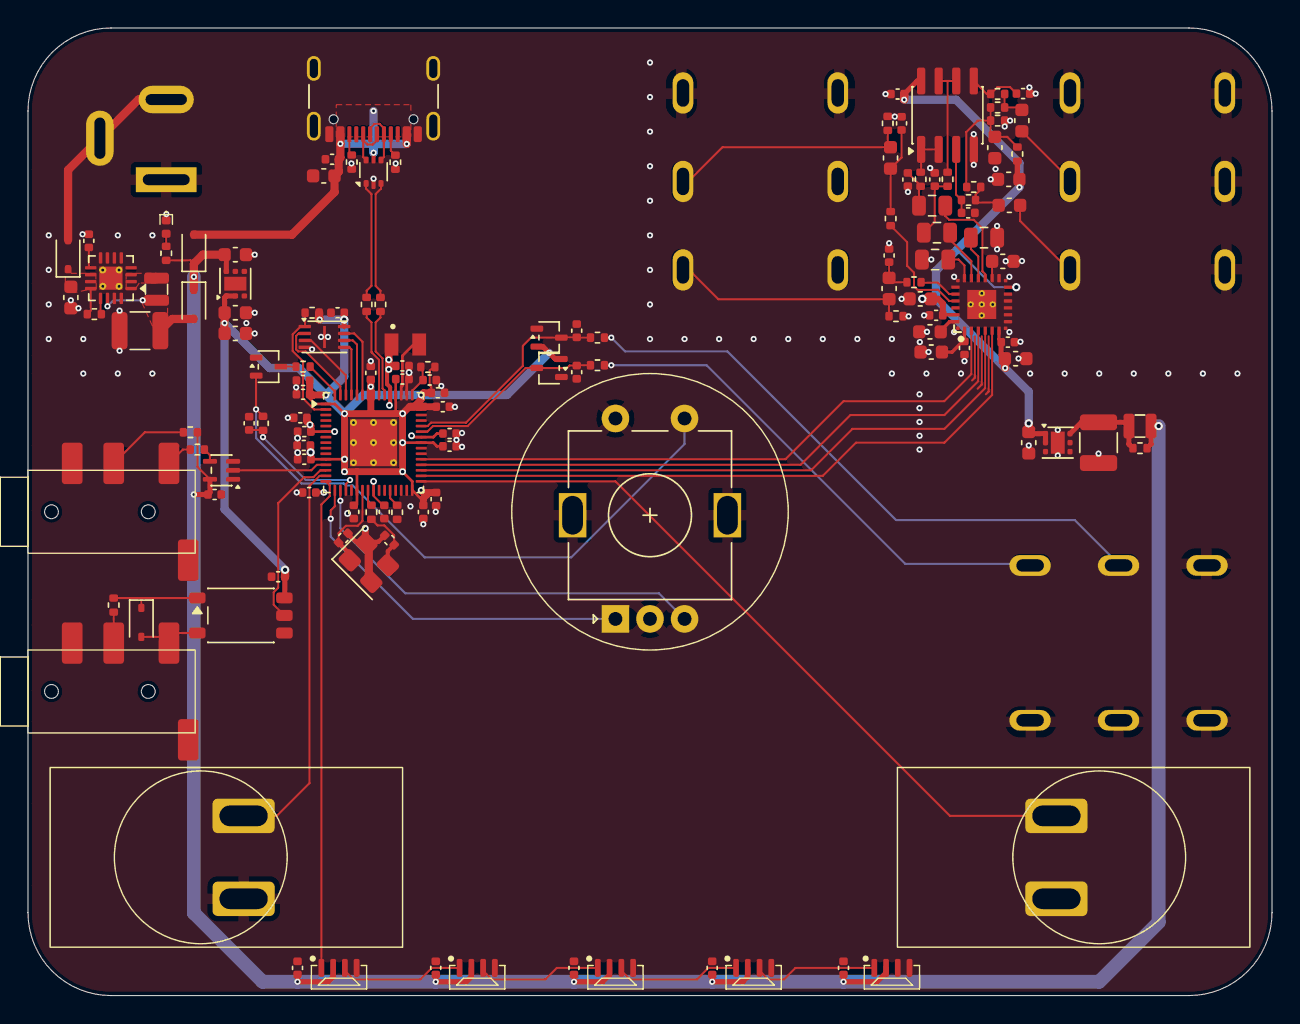
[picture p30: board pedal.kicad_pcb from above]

Board: 4 copper layers, 90.0 x 70.0 mm, 134 parts (0 on the bottom side), 87 nets.

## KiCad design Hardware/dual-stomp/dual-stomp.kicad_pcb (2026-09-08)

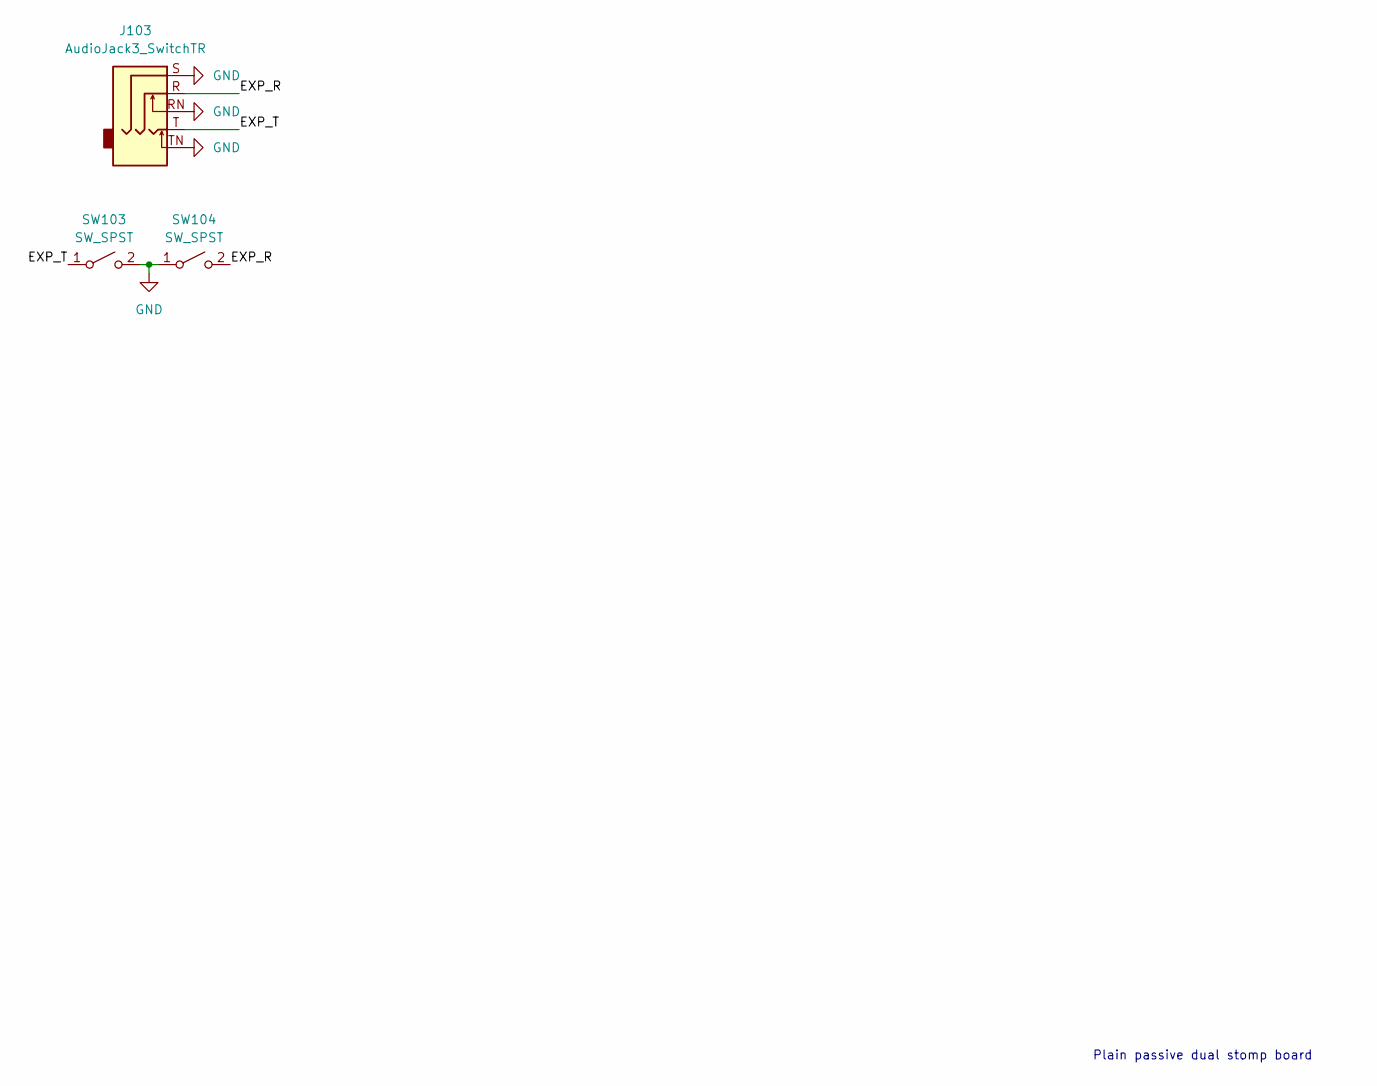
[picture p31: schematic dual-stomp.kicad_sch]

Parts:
J103: AudioJack3_SwitchTR; NRJ6HM-1-PRE
SW103, SW104: SW_SPST; Daier PBS-24B-2

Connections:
/EXP_R: J103.R, SW104.2 (B)
/EXP_T: J103.T, SW103.1 (A)
GND: J103.RN, J103.S, J103.TN, SW103.2 (B), SW104.1 (A)

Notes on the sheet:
Plain passive dual stomp board

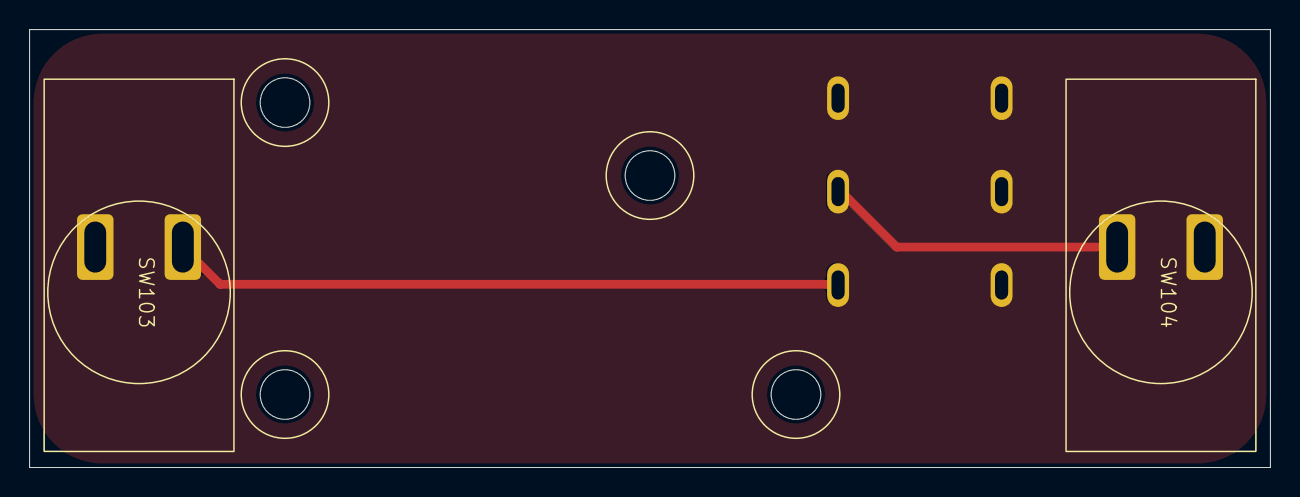
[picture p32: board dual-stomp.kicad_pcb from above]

Board: 2 copper layers, 85.0 x 30.0 mm, 3 parts (0 on the bottom side), 3 nets.

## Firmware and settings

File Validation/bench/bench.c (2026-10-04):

//
// The pedal's audio core, on a workstation.
//
// This is not a model of the signal path.  It is the signal path: the
// same audio/effect.h, the same effects/*.h, the same single_sample(),
// compiled with the same flags for a different instruction set.  The
// only things replaced are the two register blocks the audio core
// touches, and they are replaced with ordinary memory - see shim/.
//
// That distinction is the whole reason this exists.  A harness that
// re-implemented the middle of single_sample() would be a second
// opinion about what the pedal does, and a second opinion is exactly
// what you cannot check an effect against.
//
// Raw float32 stereo frames in on stdin, the same out on stdout, so
// every signal and every measurement belongs to the python on the other
// end.  Effects are named, pots are named, and nothing here is
// addressed by a number that could quietly come to mean something else.
//
// Build: see ../Makefile.  It needs effect_map.h and the three math
// tables generated first, which the Makefile does into bench/gen/.
//
#include <stdio.h>
#include <stdlib.h>
#include <stdint.h>
#include <stdbool.h>
#include <stdarg.h>
#include <string.h>
#include <strings.h>

#ifdef __SSE__
#include <xmmintrin.h>
#endif

//
// The two fake register blocks the shim headers declare.  Defined here
// rather than in a header of their own because they are storage, and
// this is the only translation unit there is - the same bargain the
// firmware makes with pedal.c.
//
#include "pico/stdlib.h"
#include "hardware/dma.h"
#include "hardware/timer.h"

struct bench_dma bench_dma_regs;
struct bench_timer bench_timer_regs;

//
// Everything below is pedal.c's include list, in pedal.c's order,
// stopping at the point where the pedal starts being a pedal.  Include
// order is program order in this codebase, so the order matters and the
// omissions are deliberate: no tinyusb, no i2c, no PIO, no scene
// storage, no UI.  None of them is between an input sample and an
// output one.
//
#include "status.h"

#include "Audio/types.h"
#include "Audio/util.h"
#include "Audio/envelope.h"
#include "Audio/single-pole.h"
#include "Audio/biquad.h"
#include "Audio/fft.h"
#include "Audio/analyze.h"

//
// One of the things audio/effect.h expects to already exist - see the
// contract at the top of it.  Written by hardware.h and read by
// nothing on this side.  analyzer_mode stays off: a bench measuring an
// effect is not measuring the tuner.
//
static volatile int user_interaction = 0;

#include "Audio/effect.h"

uint8_t effect_chain[MAX_ROUTED_EFFECTS];
uint8_t routed_effect_count = 0;

#include "effect-state.h"

//
// Declared by audio/effect.h and defined by usb-audio.h on the pedal.
// There is no USB here, and USB audio input is a separate question from
// what an effect does to a signal, so it is silence.
//
sample_t get_usb_audio_input(void)
{
	sample_t zero = { 0.0f, 0.0f };
	return zero;
}

// The same for the radio, which the bench has none of either.
sample_t get_radio_audio_input(void)
{
	sample_t zero = { 0.0f, 0.0f };
	return zero;
}

void put_radio_audio_output(raw_sample_t wet, raw_sample_t dry)
{
}

static void die(const char *fmt, ...)
	__attribute__((format(printf, 1, 2), noreturn));

static void die(const char *fmt, ...)
{
	va_list ap;
	va_start(ap, fmt);
	vfprintf(stderr, fmt, ap);
	va_end(ap);
	exit(1);
}

//
// Naming things
//
// Effects are addressed by their display name and pots by their label,
// because those are the two strings that actually exist at runtime.
// The short name - [ECHO], [CHAIN] - is deliberately not in struct
// effect: it is the effect's name in the generated C, and
// audio/effect.h says outright that storing it "cost a pointer per
// effect for nobody".  Adding one so a test could say ECHO would be
// paying that cost after all, to spell a name the display string
// already spells.
//
// Matching is case-insensitive, exact first and then unique substring,
// so 'echo' finds "Tape Echo" while an ambiguous fragment is an error
// with the candidates in it rather than a guess.
//
static bool name_hit(const char *haystack, const char *needle, bool *exact)
{
	*exact = !strcasecmp(haystack, needle);
	if (*exact)
		return true;
	for (const char *p = haystack; *p; p++) {
		if (!strncasecmp(p, needle, strlen(needle)))
			return true;
	}
	return false;
}

//
// Labels may carry leading spaces for indentation in the app -
// settings.h has "  ATTN" - so a name on a command line should not have
// to reproduce the layout.
//
static const char *unpad(const char *s)
{
	while (*s == ' ')
		s++;
	return s;
}

static struct effect *find_effect(const char *name)
{
	struct effect *hit = NULL;
	int hits = 0;

	for (int i = 0; i < (int)ARRAY_SIZE(effects); i++) {
		bool exact;

		if (!name_hit(effects[i]->name, name, &exact))
			continue;
		if (exact)
			return effects[i];
		hit = effects[i];
		hits++;
	}

	if (hits == 1)
		return hit;

	fprintf(stderr, hits ? "'%s' is ambiguous.  It could be:\n"
			     : "There is no effect called '%s'.  There is:\n",
		name);
	for (int i = 0; i < (int)ARRAY_SIZE(effects); i++) {
		bool exact;

		if (!hits || name_hit(effects[i]->name, name, &exact))
			fprintf(stderr, "    %s\n", effects[i]->name);
	}
	exit(1);
}

static int find_pot(struct effect *e, const char *label)
{
	int hit = -1, hits = 0;

	for (int i = 0; i < 10; i++) {
		bool exact;

		if (!e->pots[i].label)
			continue;
		if (!name_hit(unpad(e->pots[i].label), label, &exact))
			continue;
		if (exact)
			return i;
		hit = i;
		hits++;
	}

	if (hits == 1)
		return hit;

	fprintf(stderr, hits ? "'%s' is ambiguous on %s.  Its pots are:\n"
			     : "%s has no pot called '%s'.  It has:\n",
		hits ? label : e->name, hits ? e->name : label);
	for (int i = 0; i < 10; i++) {
		if (e->pots[i].label)
			fprintf(stderr, "    %s\n", unpad(e->pots[i].label));
	}
	exit(1);
}

static unsigned char pot_value(struct effect *e, int idx, const char *text)
{
	char *end;
	long v = strtol(text, &end, 0);

	if (end == text || *end)
		die("'%s' is not a number\n", text);
	if (v < 0 || v > max_pot_val(e, idx))
		die("%s / %s takes 0..%d, not %ld\n",
		    e->name, unpad(e->pots[idx].label), max_pot_val(e, idx), v);
	return (unsigned char) v;
}

//
// A mix is 0..120 whatever the effect is, and it is not a pot.
//
// This used to go through pot_value() with an index of zero, which
// bounded the mix against whatever the *first* pot happened to accept
// and named that pot in the error.  Every effect had a 0..120 pot in
// that slot, so it read correctly and did the right thing for years -
// until an effect turned up whose first pot is an enumeration, and
// "--mix Cabinet=120" was refused as out of range for a five-way
// switch it had nothing to do with.
//
static unsigned char mix_value(struct effect *e, const char *text)
{
	char *end;
	long v = strtol(text, &end, 0);

	if (end == text || *end)
		die("'%s' is not a number\n", text);
	if (v < 0 || v > 120)
		die("%s mix takes 0..120, not %ld\n", e->name, v);
	return (unsigned char) v;
}

//
// --list, which is how you find out what the other options accept.
//
static void list_effects(void)
{
	for (int i = 0; i < (int)ARRAY_SIZE(effects); i++) {
		struct effect *e = effects[i];

		printf("%s%s [mix: %s]\n", e->name,
		       effect_always_runs(i) ? "  (always runs)" : "",
		       e->no_mix ? "none" :
		       e->mix_law == MIX_POWER ? "equal power" : "linear");
		for (int p = 0; p < 10; p++) {
			if (!e->pots[p].label)
				continue;
			printf("    %-14s 0..%-4d default %-4d %s\n",
			       unpad(e->pots[p].label), max_pot_val(e, p),
			       e->pots[p].def_val,
			       e->pots[p].unit ? e->pots[p].unit : "");
		}
	}
}

//
// The two ends of the converter, run backwards and forwards.
//
// process_input() and convert_output() are deliberately not inverses of
// each other - the 1.2198 asymmetry in audio/process.h is exactly what
// makes the peak of the internal float equal the RMS volts of a sine -
// so undoing one with the other would put a silent 1.7dB in the middle
// of every measurement.  Each is undone with itself.
//
// So stdin and stdout are both in the pedal's *internal* float scale,
// where 1.0 is one volt RMS of sine and every dB an effect is marked in
// is measured.  A transparent chain is then a bit-exact pipe, which is
// the property the negative control checks.
//
// The input can carry a little over full scale (2^31 x the multiplier
// is 1.2198) and the output cannot: convert_output() pins anything at
// or past 1.0 and says so in 'output_clipped'.  That asymmetry is the
// pedal's, not the bench's, and the summary on stderr is how a
// measurement finds out it happened.
//
#define RAW_FULL_SCALE 2147483647.0f

static s32 float_to_raw(float v)
{
	float scaled = v / (float)SAMPLE_TO_FLOAT_MULTIPLIER;

	if (scaled >= RAW_FULL_SCALE)
		return INT32_MAX;
	if (scaled <= -RAW_FULL_SCALE)
		return INT32_MIN;
	return (s32) scaled;
}

static float raw_to_float(s32 v)
{
	return v * (float)(1.0 / 2147483648.0);
}

//
// Asking a primitive directly.
//
// Everything above runs a signal through the audio path.  This does not:
// it maps one float to one float through a single function out of
// audio/util.h, so that the fast approximations can be characterised
// against double-precision arithmetic without an effect's own
// distortion sitting on top of the answer.
//
// It is deliberately a separate mode with a separate wire format - mono
// floats rather than stereo frames - because it is not audio and should
// not be mistaken for it in a capture file.
//
// Note that the sine here is fastsincos(), which is not the same code as
// the sine the test tone generates: lfo_step() interpolates the quarter
// table itself.  Two implementations of one idea, so both are worth
// asking, and the tone generator is asked by running [TESTTONE].
//
static float map_tanh(float x) { return tanhf(x); }
static float map_sin(float x) { return fastsincos(x).sin; }
static float map_cos(float x) { return fastsincos(x).cos; }
static float map_pow2(float x) { return pow2(x); }
static float map_log2(float x) { return log2f(x); }
static float map_exp(float x) { return expf(x); }
static float map_db(float x) { return db_to_level(x); }
static float map_dbA(float x) { return db_to_A(x); }
static float map_tc(float x) { return time_constant(x); }

//
// The two single-pole helpers hand back a one-field struct, so the
// field is what there is to look at: 'alpha' is the whole filter.
//
static float map_sp_freq(float x) { return single_pole_freq(x).alpha; }
static float map_sp_time(float x) { return single_pole_time(x).alpha; }

//
// Not an approximation at all, and here because the pot curves are the
// one place where being exactly right at the ends matters - a pot that
// cannot reach its own declared maximum is a different bug from an
// inaccurate one.
//
static float map_pot_linear(float x) { return POT_TO_FLOAT(x); }
static float map_pot_cubic(float x) { return cubic(POT_TO_FLOAT(x), 0.0f, 1.0f); }

static const struct {
	const char *name;
	float (*fn)(float);
} maps[] = {
	{ "tanh", map_tanh },
	{ "sin", map_sin },
	{ "cos", map_cos },
	{ "pow2", map_pow2 },
	{ "log2", map_log2 },
	{ "exp", map_exp },
	{ "db_to_level", map_db },
	{ "db_to_A", map_dbA },
	{ "time_constant", map_tc },
	{ "single_pole_freq", map_sp_freq },
	{ "single_pole_time", map_sp_time },
	{ "pot_to_float", map_pot_linear },
	{ "pot_cubic", map_pot_cubic },
};

static int run_map(const char *name)
{
	float (*fn)(float) = NULL;
	float x;

	for (int i = 0; i < (int)ARRAY_SIZE(maps); i++) {
		if (!strcasecmp(maps[i].name, name))
			fn = maps[i].fn;
	}
	if (!fn) {
		fprintf(stderr, "no such primitive '%s'.  There is:\n", name);
		for (int i = 0; i < (int)ARRAY_SIZE(maps); i++)
			fprintf(stderr, "    %s\n", maps[i].name);
		return 1;
	}

	while (fread(&x, sizeof(x), 1, stdin) == 1) {
		float y = fn(x);

		if (fwrite(&y, sizeof(y), 1, stdout) != 1)
			die("short write\n");
	}
	fflush(stdout);
	return 0;
}

//
// One "cpu" sample period.
//
// Everything here is what the DMA engine would have done, and nothing
// here is what single_sample() does - that is the point.  The receive
// pointer goes one slot ahead of the cpu so the spin exits immediately,
// and the transmit pointer stays half a ring behind so the deadline
// check in single_sample() stays false and samples_dropped keeps
// meaning something.
//
static void bench_sample(raw_sample_t in, raw_sample_t *out)
{
	unsigned slot = cpu_idx;

	i2s_dma_buf[slot] = in;

	bench_dma_regs.ch[dma_rx].write_addr = (uintptr_t)&i2s_dma_buf[(slot + 1) & 15];
	bench_dma_regs.ch[dma_tx].read_addr  = (uintptr_t)&i2s_dma_buf[(slot + 8) & 15];

	//
	// 20.83us a sample at 48kHz.  The load meter reads the difference
	// across its own spin, which is zero here, so it will report a
	// fully loaded core.  That is honest - this "core" never waits -
	// and it is not audio either way.
	//
	bench_timer_regs.timerawl += 21;

	single_sample(1.0f);

	*out = i2s_dma_buf[slot];
}

int main(int argc, char **argv)
{
	struct { struct effect *e; int pot; unsigned char val; } pots[64];
	struct { struct effect *e; unsigned char val; } mixes[32];
	struct effect *route[MAX_ROUTED_EFFECTS];
	int nr_pots = 0, nr_mixes = 0, nr_route = 0;
	routing_bitmap_t routable;
	unsigned long frames = 0;

#ifdef __SSE__
	//
	// The pedal sets FZ in FPSCR on both cores - see enable_ftz() in
	// pedal.c - so subnormal results flush to zero.  Do the same here,
	// or a reverb tail decaying past 1e-38 takes a different path on
	// the two machines and the bench stops being the pedal.
	//
	_mm_setcsr(_mm_getcsr() | 0x8040);	/* FTZ | DAZ */
#endif

	for (int i = 1; i < argc; i++) {
		const char *arg = argv[i];
		char buf[256], *eq, *colon;

		if (!strcmp(arg, "--list")) {
			list_effects();
			return 0;
		}

		if (i + 1 >= argc)
			die("%s wants a value\n", arg);
		snprintf(buf, sizeof(buf), "%s", argv[++i]);

		//
		// Before any of the effect setup, because it does not use
		// any of it - see run_map().
		//
		if (!strcmp(arg, "--map"))
			return run_map(buf);

		if (!strcmp(arg, "--route")) {
			if (nr_route >= MAX_ROUTED_EFFECTS)
				die("a chain holds %d effects\n", MAX_ROUTED_EFFECTS);
			route[nr_route++] = find_effect(buf);
			continue;
		}

		eq = strchr(buf, '=');
		if (!eq)
			die("%s wants a NAME=VALUE\n", arg);
		*eq++ = 0;

		if (!strcmp(arg, "--mix")) {
			if (nr_mixes >= (int)ARRAY_SIZE(mixes))
				die("too many --mix\n");
			mixes[nr_mixes].e = find_effect(buf);
			mixes[nr_mixes].val = mix_value(mixes[nr_mixes].e, eq);
			nr_mixes++;
			continue;
		}

		if (!strcmp(arg, "--pot")) {
			if (nr_pots >= (int)ARRAY_SIZE(pots))
				die("too many --pot\n");
			colon = strrchr(buf, ':');
			if (!colon)
				die("--pot wants EFFECT:POT=VALUE\n");
			*colon++ = 0;
			pots[nr_pots].e = find_effect(buf);
			pots[nr_pots].pot = find_pot(pots[nr_pots].e, colon);
			pots[nr_pots].val = pot_value(pots[nr_pots].e,
						      pots[nr_pots].pot, eq);
			nr_pots++;
			continue;
		}

		die("unknown option %s\n", arg);
	}

	//
	// Bring the effects up the way pedal.c's init_effects() does:
	// every effect reset to its declared defaults, the routing, the
	// pots, then one init() per effect.  What is skipped is
	// load_globals() and load_scene(), which read an eeprom that is
	// not here - so the starting point is a pedal that has never been
	// saved to, which is exactly the reproducible one.
	//
	for (int i = 0; i < (int)ARRAY_SIZE(effects); i++)
		reset_effect(effects[i]);

	routable = routing_start();
	for (int i = 0; i < nr_route; i++) {
		uint8_t id = 0;

		while (id < EFFECT_COUNT && effects[id] != route[i])
			id++;
		if (!routing_add(&routable, id))
			die("cannot route %s: already routed, or it is not routable\n",
			    route[i]->name);
	}
	routing_end(routable);

	//
	// After the routing, because routing_end() unroutes everything
	// that was not asked for and unroute_effect() puts every pot back
	// to its default on the way past.
	//
	for (int i = 0; i < nr_pots; i++)
		set_effect_pot(pots[i].e, pots[i].pot, pots[i].val);
	for (int i = 0; i < nr_mixes; i++)
		set_effect_mix(mixes[i].e, mixes[i].val);

	for (int i = 0; i < (int)ARRAY_SIZE(effects); i++) {
		struct effect *e = effects[i];

		e->last = e->seq;
		//
		// Both of the places an effect can be set up from.  There
		// is one core here, so the split that matters on the pedal
		// does not, and whichever it has gets called.
		//
		if (e->prepare)
			e->prepare(effect_pots(e));
		if (e->init)
			e->init(effect_pots(e));
	}

	init_meters();

	//
	// And then it is just a pipe.  A frame at a time rather than a
	// buffer, because the ring is sixteen slots deep and the point is
	// to stay inside it; the cost is irrelevant next to what python
	// does with the answer.
	//
	for (;;) {
		float frame[2];
		raw_sample_t in, out;

		if (fread(frame, sizeof(frame), 1, stdin) != 1)
			break;

		in.left = float_to_raw(frame[0]);
		in.right = float_to_raw(frame[1]);

		bench_sample(in, &out);
		frames++;

		frame[0] = raw_to_float(out.left);
		frame[1] = raw_to_float(out.right);

		if (fwrite(frame, sizeof(frame), 1, stdout) != 1)
			die("short write\n");
	}

	fflush(stdout);

	//
	// The conditions the numbers were taken under, on stderr where
	// they cannot be mistaken for signal.  'clipped' and 'dropped'
	// are the two that invalidate a measurement rather than merely
	// describing it, and 'fade' is how many frames at the front of the
	// capture are an effect ramping in rather than an effect.
	//
	fprintf(stderr,
		"frames %lu  clipped %u  dropped %u  fade %d\n"
		"in %.6f  floor %.6f  out %.6f\n",
		frames, output_clipped, samples_dropped, EFF_ENABLE_STEPS,
		meter_in, meter_floor, meter_out);

	return 0;
}

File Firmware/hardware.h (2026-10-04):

#ifndef HARDWARE_H
#define HARDWARE_H

//
// Bringing the board up, and finding out which board it is.
//
// include/board.h says *which pins*.  This says *how to start them*: the
// i2s state machines and their DMA, the WS2812 program, one debounce
// state machine per switch, the PWM the LEDs are dimmed with, and the
// rotary encoder's quadrature decoder.
//
// It also probes what is on the i2c bus, which is a different question
// and lives here because it is the same one: what is actually out there.
// A fixed build cannot adapt to the board it lands on and does not try -
// the answer goes out in the identity reply so that "is this the board
// this firmware was built for" can be asked of a running pedal.
//
// Ordering note, since this is one translation unit and include order is
// program order: this has to come before midi/sysex.h, because the
// identity reply reports what probe_hardware() found.
//

//
// What gets reported is what was *observed*.  Any inference from it -
// which board this is, how old - belongs to whoever is reading rather
// than in the wire format, so that being wrong about it later costs an
// app change and not a protocol one.
//
static struct {
	bool i2c_codec;		// a codec answered, so it is not strapped
	bool legacy_screen;	// SH1106, 0x3c - a design that is gone
#ifdef NRF54_SWDIO
	uint32_t radio;		// the nRF54's debug port id, or zero
#endif
} hardware;

//
// One i2s state machine's DMA.
//
// All four are the same channel with the direction flipped.  Memory is
// the side that increments and the side the ring wraps, and which of
// read or write that is depends on which way the samples are going.
//
static int i2s_dma_channel(uint sm, bool is_tx, raw_sample_t *buf,
			   uint ring_bits)
{
	int chan = dma_claim_unused_channel(true);
	dma_channel_config c = dma_channel_get_default_config(chan);

	channel_config_set_transfer_data_size(&c, DMA_SIZE_32);
	channel_config_set_read_increment(&c, is_tx);
	channel_config_set_write_increment(&c, !is_tx);
	channel_config_set_dreq(&c, pio_get_dreq(pio0, sm, is_tx));
	channel_config_set_ring(&c, !is_tx, ring_bits);	// the buffer

	pio_sm_clear_fifos(pio0, sm);

	if (is_tx)
		dma_channel_configure(chan, &c, &pio0->txf[sm], buf,
				      0xffffffff, false);
	else
		dma_channel_configure(chan, &c, buf, &pio0->rxf[sm],
				      0xffffffff, false);

	return chan;
}

#ifdef NRF54_SWDIO
#include "nRF54/app/src/i2stest.h"

//
// The radio's audio link, in rings the DMA loops round.  What goes out is
// what the audio core writes a few frames ahead of the DMA - audio, or the
// test pattern (i2stest.h) when Bluetooth Audio's Out is None - and starts
// as the pattern.  What comes back is audio or the radio's copy of the
// pattern, into a ring deep enough - 85 ms - that the main loop checks
// every frame of it.
//
#define NRF54_I2S_TX_SHIFT	8
#define NRF54_I2S_TX_FRAMES	(1 << NRF54_I2S_TX_SHIFT)
#define NRF54_I2S_TX_MASK	(NRF54_I2S_TX_FRAMES - 1)
#define NRF54_I2S_RX_SHIFT	12
#define NRF54_I2S_RX_FRAMES	(1 << NRF54_I2S_RX_SHIFT)
#define NRF54_I2S_RX_MASK	(NRF54_I2S_RX_FRAMES - 1)

static raw_sample_t __attribute__((aligned(sizeof(raw_sample_t) *
					 NRF54_I2S_TX_FRAMES)))
	nrf54_i2s_tx[NRF54_I2S_TX_FRAMES];

// One repeat of the pattern, in RAM for the audio core
static raw_sample_t nrf54_i2s_pattern[I2STEST_FRAMES];
static raw_sample_t __attribute__((aligned(sizeof(raw_sample_t) *
					 NRF54_I2S_RX_FRAMES)))
	nrf54_i2s_rx[NRF54_I2S_RX_FRAMES];
static int nrf54_dma_tx, nrf54_dma_rx;

static struct {
	bool on;
	uint32_t tail;			// frames taken from the ring
	struct i2stest_rx rx;		// since the last report
	uint32_t reported_at;

	//
	// The same frames read as audio, for when it is not the pattern:
	// the peak of each channel, and how often each crosses zero going
	// up, which over a second of a tone is its frequency.
	//
	int32_t peak[2];
	uint32_t ups[2];
	bool was_neg[2];
} nrf54_i2s;

static void nrf54_i2s_audio(int ch, int32_t v)
{
	int32_t a = v < 0 ? -(v + 1) : v;

	if (a > nrf54_i2s.peak[ch])
		nrf54_i2s.peak[ch] = a;
	if (nrf54_i2s.was_neg[ch] && v >= 0)
		nrf54_i2s.ups[ch]++;
	nrf54_i2s.was_neg[ch] = v < 0;
}

// A peak as dBFS, to a tenth of a dB, for the report
static void nrf54_i2s_dbfs(int32_t peak)
{
	int db10 = peak ? (int)lrintf(200.0f *
				      log10f(peak / 2147483648.0f)) : -1200;

	if (db10 < 0) {
		dbg_puts("-");
		db10 = -db10;
	}
	dbg_dec(db10 / 10);
	dbg_puts(".");
	dbg_dec(db10 % 10);
	dbg_puts(" dBFS");
}

//
// Times core 1 has had to move its read or its write position in the
// radio's rings, which skips or repeats audio.  Written by core 1 only.
//
static volatile uint32_t nrf54_i2s_moves, nrf54_i2s_out_moves;
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

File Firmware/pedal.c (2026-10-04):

#include <stdio.h>
#include <stdlib.h>
#include "pico/stdlib.h"
#include "pico/bootrom.h"
#include "pico/unique_id.h"
#include "hardware/watchdog.h"
#include "pico/multicore.h"

#include "hardware/gpio.h"
#include "hardware/pio.h"
#include "hardware/i2c.h"
#include "hardware/pwm.h"
#include "hardware/clocks.h"
#include "hardware/dma.h"
#include "hardware/timer.h"

#include "board.h"
#include "branch.h"

#include "status.h"
#include "debounce.pio.h"
#include "rotary.pio.h"
#include "i2s.pio.h"
#include "swd.pio.h"

// Both i2s links live on pio0 so that they share one copy of the two
// programs: an instance costs a state machine rather than another 18
// instructions, and all four run the identical code.  The radio's pair
// is started only when a radio answers - see init_nrf54_i2s().
#define PIO0_I2S_TX_SM 0
#define PIO0_I2S_RX_SM 1
#define PIO0_NRF54_I2S_TX_SM 2
#define PIO0_NRF54_I2S_RX_SM 3

// PIO1 runs one debounce state machine per switch, and the state
// machine index is the switch id - see switch.h.  PIO2 has the one
// rotary encoder, the WS2812s, which were on pio0 until its four state
// machines went to the two i2s links, and the SWD wire to the radio.
#define ROTARY_SM 0
#define PIO2_WS2812_SM 1
#define PIO2_SWD_SM 2

#define PWM_WRAP 4096	// Entirely arbitrary

#include "Audio/types.h"
#include "Audio/util.h"
#include "Audio/envelope.h"
#include "Audio/single-pole.h"
#include "Audio/biquad.h"
#include "Audio/fft.h"
#include "Audio/analyze.h"
#include "hwtone.h"
#include "tac5112.h"

//
// After the state machine numbering above, which it uses.
//
// Only on a board that has them.  pixels.h is the whole WS2812B driver
// and is written against NR_LEDS and WS2812_GPIO, so on a board with a
// plain PWM LED there is nothing here to compile - every caller is
// already behind the same #ifdef.
//
#ifdef WS2812_GPIO
#include "pixels.h"
#endif


#include "midi/midi.h"
#include "midi/uart.h"
#include "tusb.h"
#include "debug.h"
#include "usb-audio.h"
#include "usb-volume.h"
#include "switch.h"

static volatile int user_interaction = 0;

#include "Audio/effect.h"

uint8_t effect_chain[MAX_ROUTED_EFFECTS];
uint8_t routed_effect_count = 0;

#include "effect-state.h"

#include "scene.h"
#include "nrf54/swd.h"
#include "nrf54/dap.h"
#include "nrf54/rram.h"
#include "nrf54/update.h"
#include "nrf54/uart.h"
#include "hardware.h"
#include "exp.h"
#include "midi/sysex.h"
#include "hum-learn.h"

#include "ui.h"

static inline void enable_ftz(void)
{
	// FZ bit (24) in FPSCR flushes subnormal results to zero in hardware,
	// covering every float op in the audio chain. Without it, any feedback
	// path that decays into sub-1e-38 range causes a 5-20x FPU slowdown on
	// Cortex-M33 (VFPv5 handles subnormals in hardware, not via trap, but
	// still at a significant penalty). Must be set per-core.
	uint32_t fpscr;

	fpscr = __builtin_arm_get_fpscr();
	fpscr |= 1u << 24;
	__builtin_arm_set_fpscr(fpscr);
}

static void __audio_func(audio_processing)(void)
{
	enable_ftz();
	init_meters();
	for (;;)
		make_one_noise();
}

unsigned get_audio_samples(int32_t *buffer, unsigned nr)
{
	return get_output_samples((s32 *)buffer, nr);
}

static void init_effects(void)
{
	for (int i = 0; i < ARRAY_SIZE(effects); i++) {
		struct effect *effect = effects[i];
		reset_effect(effect);
	}

	//
	// The settings first, because they are the pedal's and not the
	// scene's - which of them is the MIDI channel should not depend
	// on which scene happens to load next.
	//
	load_globals();

	//
	// No fallback for a store with nothing in it, because there is
	// nothing to fall back to.  A slot that fails its hash, or was
	// never written, simply does not load and every effect keeps the
	// defaults reset_effect() just gave it - which leaves a new pedal
	// with everything at its default and nothing routed.  That is the
	// right answer, and guessing a chain would be worse.
	//
	load_scene(0);

	//
	// By hand, both of them, because core 1 is not running yet:
	// nothing will reach init() on its own until the audio loop
	// starts.
	//
	for (int i = 0; i < ARRAY_SIZE(effects); i++) {
		struct effect *effect = effects[i];

		if (effect->prepare)
			effect->prepare(effect_pots(effect));
		if (effect->init)
			effect->init(effect_pots(effect));
	}
}

#include "tuner.h"

//
// How long boot is allowed to take before it is called a hang.
//
// Everything between here and the main loop is i2c probes with 2ms
// timeouts, some table building and a flash read, so the real figure is
// milliseconds and this is all margin.  It has to stay well clear of
// the truth in the other direction too: a boot that legitimately took
// longer than this would reach BOOTSEL instead of playing, which is a
// worse failure than the one being guarded against.
//
#define BOOT_WATCHDOG_MS 3000
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

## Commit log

2026-05-13 Bring in kicad design files for the rebooted guitar pedal project
    I'm not bringing in the whole messy history - some of it exists in
    previous generations of the guitar pedal project, but most of it is just
    me making (and hopefully fixing) mistakes and random updates.
    So this is just the current state of the project.
    There are two core "modular" boards with the core hardware:
    - The rp2354 board contains the Raspberry Pi RP2354 microcontroller
    together with the required basic infrastructure: 12MHz crystal,
    bypass capacitors, and components for the internal 1.1V switching
    power supply of the rp2354.
    - the codec board contains TAC5112 stereo codec, and a small 2kbit
    EEPROM flas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
    [CK-6.35-308.step, WR-DC-2.1.step, audio-jacks.kicad_pcb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]
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2026-05-15 Add "enumeration pot values" to the UI
    This converts the hacky USB Wet - Dry - WetDry output setting to the new
    pot model, which avoids all the random special handling it did to get
    that three-way choice instead of a linear scale from -100 to 100.
    But the real reason for it is for a conversion of the Hothouse
    "EchoKing" effect, which uses three-way toggle switches for some of the
    effect settings.
    I was talking to Ricky Sheaves (Cleveland Music Co, who makes that
    Hothouse pedal) and he noted my description of the dismal state of my
    echo effect, and pointed me at his much superior DSP implementation of
    that Echo King pedal, and graciously agreed to also re-license it as
    "GPLv2 or later", so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
    [effect.h, ui.h]
2026-05-15 Replace simplistic echo with the Cleveland Music Co Echo King
    This is the converted Echo King implementation. Most of my effort was
    the prep-work to explain to antigravity what I wanted done.
    Any bugs as a result are mine, but even if the conversion may be buggy
    it's definitely an improvement over the old echo effect.
    All actual credit for the effect goes to Ricky Sheaves of Cleveland
    Music Co, and I want to just point out the source of this effect here:
    https://github.com/clevelandmusicco/HothouseExamples
    [ Current top-of-tree as of right now is commit dd10d8d ("Tweak README
    for style and change echo_king.cpp to GPLv2 [with the 'either version
    2 of the License, or (at your opti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
    [echo.h]
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2026-05-23 Add much better 'tanh()' approximation
    This is a [5/4]-Padé approximant, tweaked to also always limit the
    result to the ±1.0 range.
    It's basically accurate to within the float representation(*) in the
    reasonable [-1,1] range, with the max error at ±3.647, where the
    accuracy has fallen to "only" 9.5 bits (2.87 decimal digits).
    This was triggered by discussion with Ricky Sheaves, who is tuning the
    Echo King effect and the simplistic tanh() approximation using the
    'limit_value()' code was audibly not good enough.
    I didn't actually make the Echo King code use this new tanhf(), because
    Ricky is doing other changes to it too, but I wanted to at least add the
    improved infrastructure.
    (*) Ok,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
    [util.h]
2026-05-24 Tape Echo: use the updated tanhf() Padé approximant
    The version in util.h is slightly more exact because it doesn't tweak
    the Padé approximant to meet the limit at the input at ±3.0 and just
    clamps the output instead.
    Not that it matters, but it triggered my OCD and the more exact version
    doesn't generate any worse code and is arguably even simpler.
    Equally importantly - but not unexpectedly - it passes Ricky's ear
    tests.
    [echo.h]
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2026-05-27 Tape Echo: remove cruft and tweak performance
    - Remove tape noise generator (`LCG PRNG`, `noise_lpf`, hiss injection): the noise floor was set to 0; this was an expensive no-op
    - Lower all three filter cutoffs by ~1 kHz (`record_fc `7500->6500, `playback_fc` 6000->5500, `feedback_fc` 5000->4500): darker baseline character closer to an actual tape echo
    - Tone pot default value 19->13: matches the adjusted filter center after the cutoff changes
    - Replace local `echo_smooth()` with the shared `linear()` helper: removes a duplicate of the same one-liner already in util.h
    - Inline `echo_time_pot` and `echo_tone_pot`: both were trivial wrappers with no logic worth naming
    - Guard playback LPF cutof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
    [echo.h]
2026-05-27 Add preamp and vibrato effects
    **Preamp** (`preamp.h`)
    Wait, don't we already have a Boost effect? Yes, but ...
    The current boost effect does wavefolding: it hard-clips by reflecting the
    signal back on itself, generating mostly odd-order harmonics with a sharp
    transition at the clip boundary. That's perfect for aggressive clipping or
    distortion pedal simulation, but it is not how a class-A analog front end
    behaves.
    Preamp uses asymmetrically biased tanh saturation. Biasing the waveshaper
    off-centre generates even-order harmonics (mostly 2nd), which is the magick
    behind the warm character of class-A tube and JFET stages. The distortion onset
    is gradual; there is no clip boundary; just a so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
    [effect.h]
2026-05-27 Add Freeverb reverb effect (Schroeder-Moorer, mono 48 kHz)
    Jezar's public-domain Freeverb algorithm, ported to the pedal's
    sample-at-a-time mono path at 48 kHz.
    DSP topology:
    - 8 parallel feedback comb filters (FBCF), all fed directly from
    the input; each has a one-pole LP in its feedback path
    - 4 series Schroeder allpass filters on the summed comb output
    - Delay lengths are the canonical Freeverb 44100 Hz values scaled
    to 48000 Hz (multiply by 48/44.1)
    Parameters:
    - Mix: linear dry/wet, with `fixedgain` (0.015) on the comb input
    and `scalewet`/`scaledry` (3.0/2.0) normalising levels
    - Room: feedback gain `g` in [0.70, 0.98] via roomscale/roomoffset
    - Damp: one-pole LP pole in [0, 0.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
    [effect.h]
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2026-05-27 Reduce reverb CPU load; minor echo optimisations
    While testing, I discovered that loading reverb and echo at the same
    time resulted in audio artefacts. I don't have a profiler or cycle
    counter on the hardware, so I made these changes a couple at a time
    until the noise/distortion/crackle disappeared from the combined
    echo loop + reverb tail. Not very scientific, and my math may not be
    close to right, but it worked.
    Reverb:
    - Drop from 12 to 10 parallel FBCFs; scale `REVERB_FIXEDGAIN` up from
    0.007 to 0.0084 to preserve wet level with fewer combs; reverb still
    sounds OK
    - Remove fractional-delay interpolation from the comb read: one buffer
    load per comb instead of two, dropping the lerp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
    [echo.h]
2026-05-28 Add tremolo effect with NORM and HARM modes
    Just three controls.
    RATE: 0.1-10 Hz, cubic
    DEPTH
    MODE (NORM/HARM).
    NORM mode uses bipolar AM: gain = 1 + k*lfo, where k = depth/(2-depth).
    Average level stays at 1.0 at all depth settings, so 100% depth swings
    0..2x rather than cutting average level by up to 6 dB.
    HARM mode models the Fender 6G4 harmonic vibrato circuit with two
    one-pole filters: a LP at 144.7 Hz (220k/5nF) for the low branch and a
    HP at 636.6 Hz (1M/250pF, computed as in-LP) for the high branch. The
    LFO modulates them in opposite phase. The two corners are not
    complementary, so there is a broad mid-frequency dip and phasey
    recombination on summing, which is what gives the brow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
    [effect.h]
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2026-05-29 Echo: replace float[65536] delay line with int16_t[32768]
    The `float array[65536]` delay line was consuming 256 KB -- 59% of the
    entire 434 KB bss -- leaving only 7.5 KB of headroom against the 520 KB
    SRAM limit. With `copy_to_ram` in effect, text + bss share the same
    pool. A 7.5 KB margin is far too uncomfortable.
    `audio/util.h`:
    - Add `__sample_array_write_s16` / `sample_array_write_s16`: writes a
    `[-1, 1]` float to an `int16_t` cell as `val * 32767`.
    - Add `__sample_array_read_s16` / `sample_array_read_s16`: converts two
    adjacent `int16_t` cells to float via `1/32767` and returns the
    linearly interpolated result. Same ring-buffer bitmask logic as the
    float variants.
    `audio/echo.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
    [echo.h, util.h]
2026-05-29 Switch USB HID protocol to use MIDI over USB instead
    The HID protocol was a mistake - I blame the fact that I have all the
    musical ability of a snail on drugs. The obviously correct answer is to
    use MIDI, so that we could use an actual standard interface both on a
    computer and even using things like external stomp switches.
    As always, the USB code is written by Antigravity. I think that's the
    proper distribution of roles: Ricky has been doing any actual _musical_
    effects, I've been doing the hardware interfaces, and Antigravity deals
    with the tinyusb integration.
    [ui.h, usb-device.c]
2026-05-29 Change pot value range from -100..+100 to -60..+60
    So "100" looks like a rounder number to a human, and that's obviously
    why I picked that original range.
    But the -100..+100 range does not map very well to MIDI, which sends
    7-bit numbers in the 0..127 range. I started out with -63..+63
    originally, but that really doesn't work when some of the settings (like
    the "octaves" for the pitch shifter) really want nice divisors.
    So '60' it is, and in some ways it is actually a "rounder" number than
    100, in that it divides nicely into even more cases than 100 does.
    While 100 is natural in base-10, it is only divisible by combinations of
    two and five. In contrast 60 is divisible by combinations of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
    [compressor.h, echo.h, ui.h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]
2026-05-30 Fix USB device descriptor for the composite audio / MIDI device case
    The USB device descriptor needs a "Interface Association Descriptor
    (IAD)" for the MIDI part. Add it.
    Since the pedal exposes a composite interface of both the audio
    interface (for audio in and out) and the MIDI interface (for controlling
    the effects), it should have that interface association descriptor to
    tell the other side that the two interfaces go together and control the
    same function.
    I don't think Linux actually cares, but Antigravity tells me apparently
    Windows needs it to load the MIDI drivers, so let's do it right.
    Of course, I have no way of testing whether this really makes any
    difference. But in my cunni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
    [usb-device.c]
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2026-05-31 Convert effects to metadata-driven boiler plate generation
    This is the actual effect format update mentioned in the previous
    commit: express the boiler plate details in the comment at the top of
    the effect so that it can be auto-generated.
    Part of that is that now the default values can be much more sanely
    expressed: instead of setting the defaults as the particular integer
    values the pot takes, express them in the user-visible units.
    So the default noise gate level value can now be described as
    // POT: "Level" LINEAR(-100.0 -40.0) = -70.0 dB
    instead of the inscrutable
    EFFECT_POT("Level", desc_dB, gate_pot0_level, 0), // -70dB
    where the default value of 0 ended up indeed bein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
    [compressor.h, echo.h, effect.h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]
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2026-06-01 echo: Fix up displayed time and tone values
    The echo effect did actually calculate the right values for the sound,
    but in the conversion to the metadata model, the "display in right
    units" code for these two pots got lost.
    The math was done in two places (in echo_time/tone_display() and in
    echo_init()) and the 'display' part was lost in the chaos of rewriting
    the pot descriptors and re-doing how the effects were defined.
    This reinstates the display by teaching the metadata about the special
    exponential function that these two pots used, and updating the pot
    description to match the match that the effects used to do in two
    separate places.
    My bad for not noticing immediately - this is all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
    [echo.h]
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2026-06-03 Extend the range of "not twitchy rotary effects"
    The recent USB MIDI channel effect had 17 enumerations ("Omni" and
    channels one through sixteen), and that ended up being enough of a range
    that the UI code decided to go into "fast mode" for the rotary encoders.
    That's way too twitchy.
    I really need to sit down and tune the rotary encoder quadrature
    decoding, because Dirk also was complaining about how the effect rotary
    doesn't feel reliable - sometimes it switches every detent on the
    rotary, sometimes it takes two.
    I think the issue is that I generate a counter update (up or down) on
    every quadrature change, but the detents on a rotary encoder are only at
    a full quadrature sequence. I "c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
    [ui.h]
2026-06-05 Add plain MIDI-control only pedal design
    This has no UI except for a single stomp switch and LED, since the plan
    is that it replaces it all with with just MIDI control.
    I already have working MIDI-over-USB (with horribly inconvenient USB-C
    port placement on the previous board, but that's a historical accident
    from when I didn't realize that I actually want to use that connector
    for more than programming).
    But this also adds 3.5mm TRS jacks for MIDI input and output, so that I
    could attempt to do that too.
    Do I know what I am doing? No.
    Has that stopped me before? Also no.
    The plan is that this should work together with the existing audio jack
    board and connect to it over the 12P FFC cab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
    [CK-6.35-308.scad, CK-6.35-Stereo.scad, CK-6.35-Stereo.step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]
2026-06-06 Change effect saving to happen on long-press of the effect stomp
    The whole "save at effect change" really didn't work very well as an
    interface to begin with, and had stopped working entirely with the MIDI
    changes.
    This "save with long-press" was always one of the primary alternatives,
    so let's do just that.
    I'm open to better UI suggestions.
    [ui.h]
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2026-06-06 Add some basic single-pole helpers
    These are slightly over-engineered, but the point is to make them both
    type-safe in C with structure wrappers around the coefficients and
    previous state, and to also allow the coefficient to just be a fixed
    compile-time value for the case where you just want to use a plain fixed
    time constant or frequency.
    [tac5112.h, util.h]
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2026-06-06 Abstract out the envelope follower code
    The noise gate and compressor both had the same envelope code, and I'm
    looking at some more users, so let's just abstract it out and make it
    more legible in the process.
    [compressor.h]
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2026-06-06 Frenchie: update based on code review by Antigravity
    - Completely remove frenchie.input_hp (the 80Hz biquad high-pass) as a
    guitar plugs straight into the 12AX7 grid on a Champ. This will
    restore the authentic low-end response.
    - Remove the 800Hz cathode shelf from frenchie_input_stage. The 5F1
    Champ V1A has no bypass capacitor, so the gain is flat.
    - Fix Cathode Bias Shift Physics: Change the 6V6 cathode bias shift
    from a VCA multiplier to a true DC offset:
    Old: b *= (1.0f - cathode_shift);
    New: b -= cathode_shift;
    This accurately models the grid-to-cathode voltage shifting
    negatively under load, causing the asymmetric clipping to push
    into cutoff faster.
    - F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
    [frenchie.h]
2026-06-07 Fix selected effect (and enum) highlighting for longer cases
    This has been broken for a while: the highlighting of a selected effect
    or enum was limited to just five characters because we only had sprite
    data 32 pixels wide (which was five characters, each six pixels wide,
    plus the two columns around the text).
    That was fine originally, because the effect short-names were all five
    characters or less. But the enum name highlighting had the same broken
    code, and enumerations already had longer names (eg "Wet/Dry" for the
    USB audio output).
    And now "Frenchie" had a 6-character shortname ("FRENCH") and made the
    bug really obvious.
    I should probably extend the sh1106 code to actually have a "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
    [ui.h]
2026-06-07 sh1106: do the reverse rectangle properly
    Bah. I did this ugly hack to ui.h to do reverse text because I didn't
    have the energy to look at sh1106. But then I shamed myself at just
    going back to the sh1106_fill() logic, and realized that it's actually
    trivial to just make it do the reversing.
    In fact, it was less effort than the ugly ui.h hack was.
    That should teach me.
    Anyway, no more artificial limits on the reverse text length now that
    sh1106 code just does the reverse rectangle case for arbitrary sizes.
    [ui.h]
2026-06-07 Rename 'USB' effect to 'Settings'
    When I added the MIDI channel setting, the USB effect really became more
    of a general settings panel. It still kind of made sense to call it
    'USB' when MIDI was still only over USB, but I now have a HW design (not
    back yet) that has actual hardware MIDI support entirely separately from
    the USB port. While I won't start doing the actual software support
    until I have hardware to test it back, I might as well just rename this
    'effect' now.
    While at it, just to test, this adds settings for the LED brightness. It
    was briefly discussed as an issue (#11) and I decided I just want to see
    how much of a difference the PWM intensity makes.
    Note that the brightness wi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
    [effect.h, ui.h]
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2026-06-09 Add 'float_to_ascii()' helper function to ease printing of floats
    We did have one case of it done by hand with 'to_ascii' and multiplying
    by tens etc, but that one didn't do rounding to significant digits for
    large values etc.
    I want the tuner to actually show frequencies too, and I don't want to
    add another hack 'to_ascii()' case.
    [ui.h]
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2026-06-09 Clean up 'rintf()' use - prefer 'lrintf()' instead
    Stop doing the float-to-integer conversions with 'rintf()' and a cast.
    There's a perfectly fine 'lrintf()' that does it all.
    I clearly don't have a lot of history of doing a lot of floating point
    in C, and I used to do this same thing in subsurface (where it was fixed
    by others long ago, without me ever learning better).
    One day I'll use the right function from the start.
    [tac5112.h, ui.h, util.h]
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2026-06-11 Improve on spectral whitening precision
    I tried doing the polyphonic tuning before whitening, but it really
    doesn't work. On the DADGAD tuning, the harmonics of D2 will basically
    exactly hit D3, A3 and D4, and they'll all look like they are perfectly
    in tune if D2 is in tune.
    So scrap that idea.
    But being more surgical about the spectral whitening seems to improve on
    things, and if you have a D2 in tune and whiten things carefully enough,
    you'll still see when the other strings are out-of-tune.
    And while an in-tune D4 will get whitened out, that's not nearly as bad
    as a badly out-of-tune D4 being hidden by a well-tuned D2. So let's
    keep the whitening where it is, but just improve on it.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
    [util.h]
2026-06-11 Add MIDI transfer of tuning data
    It transfers the tuning data as actual MIDI notes with the cent data
    using the "pitch bend" range. The tuner on/off is just another
    GLOBAL_ENABLE_CC byte.
    Because pitch bending is per-channel - and we want to send multiple
    notes for the polyphonic case - this sends the tuning data on separate
    channels, with channel #0 for the chromatic tuning data.
    This is all possibly horribly wrong. And I think my recent
    simplifications of the tuning code may have over-simplified things a
    bit, and it got a bit less reliable and the chromatic one now finds
    bogus over-tones much too easily.
    So this all will need tweaking a lot to be useful, but the code *looks*
    clean. I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
    [usb-device.c]
2026-06-11 Add our tuner magnitude data to the MIDI note output
    This is potentially useful for debugging, particularly when things go
    wrong and it just picks up noise or we have harmonics on the polyphonic
    tuning.
    But who am I kidding - the real reason for this is a hilariously
    annoying experimental addition to the WebUI where it not only shows the
    results, but plays them too. It's horrible.
    [usb-device.c]
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2026-06-20 Re-organize MIDI code a bit, add UART option
    This adds a parallel path for MIDI packets using the UART for
    traditional HW MIDI ports.
    It's off by default, because I didn't think things through: my non-UI
    pedal with MIDI HW support uses GPIO26/27 for MIDI OUT/IN.
    But that's what the second rotary encoder uses for the pedal with a UI,
    so if you enable MIDI support you lose the rotary.
    So make it an option you have to explicitly enable when you build for
    the non-UI pedal.
    I didn't bring out enough GPIOs from the rp2354 board to have unique
    GPIOs (mainly because I incorrectly thought that I wanted to bring out
    the SWD pins that I've never used), so now I have the situation that I
    have to mak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
    [usb-device.c]
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2026-06-23 i2s: mostly fix things up as per previous notes
    This is a fairly minimal "let's try to fix up i2s as per notes":
    - Move from 24-bit to 32-bit i2s word size
    The TAC5112 doesn't care, it will auto-sync with whatever BCLK/FCLK
    that is in sane limits (and we certainly don't need the extra
    precision that doesn't exist in the signal and that we'll throw away
    by converting to single-precision floating point anyway).
    But since I'm considering using a TAC5242 that appears to be fixed at
    32 bit word size, let's just move to that now. And technically it
    does mean that we have one less shift in the SW path now that the
    data comes in as a full 32-bit word.
    - As a result, the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
    [effect.h]
2026-06-24 Start using DMA for i2s transmit
    We already used DMA for the i2c transfers for the SH1106 display
    updates, just so that we wouldn't block the CPU while waiting for a slow
    i2c bus.
    This starts using DMA for the i2s transmit side - not because we need
    the buffering, but mainly because I'm thinking of how to do stereo, and
    I feel like keeping the channels in sync in the presence of possibly
    missed samples if the CPU ever falls behind is a nightmare.
    So the use of DMA is mainly about guaranteeing that the i2s PIO engine
    is fed reliably, even if we were to screw something up in the audio
    effect chain. It's better to feed stale samples than to get out of
    sync.
    Currently, this isn't an issue, b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
    [effect.h]
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2026-06-24 Update the 'dropped sample' debugging to the i2s DMA situation
    It's disabled again, but I used this to verify that things actually work
    as expected, with the RX and CPU pointers in the i2s_dam_buf staying
    rock solid at about 24 samples ahead of the TX pointer.
    And by "rock solid" I mean "until the CPU starts falling behind and
    missing samples". And at that point, the RX/TX pointers keep in a
    steady sync as expected, and the CPU pointer is all over the map because
    the i2s data just keeps coming faster than we can deal with.
    So this shows that the code works exactly as intended. The CPU overload
    case was the main reason for this all, and the fact that the data is
    still fed reliably to the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
    [ui.h]
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

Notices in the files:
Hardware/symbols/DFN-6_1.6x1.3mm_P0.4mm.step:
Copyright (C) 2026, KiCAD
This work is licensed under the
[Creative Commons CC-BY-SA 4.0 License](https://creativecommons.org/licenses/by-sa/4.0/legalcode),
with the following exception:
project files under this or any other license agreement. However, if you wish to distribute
